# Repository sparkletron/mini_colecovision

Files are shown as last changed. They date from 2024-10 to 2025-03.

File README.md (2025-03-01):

# Mini Colecovision Project with Super Game Module Support
### Schematic, PCB, and CPLD design.



---

  author: Jay Convertino

  date: 2024.03.24

  details: A Super Game Module Compatible Colecovision that is much smaller than the original, and only uses +5v.

  license: MIT

---

## LICENSE
  - All files related to or generated from the KiCAD source fall under the MIT license.
  - All files related to or generated from the Verilog source fall under the MIT license.
  - All files generated by me, Jay Convertino, fall under the MIT license.
  - All files from other sources fall under the license of their specification.

## RELEASE VERSIONS
### Current
  - 1.0.1 - Fixed opcode games AY check for super game module.

### Past
  - 1.0.0 - First working version
  - DEV

### MISC
  - std_v1 - A branch that contains the first version with standard colecovision compatibility only.

## Intro
  This is a miniturization of the original colecovision. All logic is simplified to a single CPLD.

## Documentation
  For detailed usage information, please navigate to one of the following sources. They are the same, just in a different format.
  - [mini_colecovision.pdf](docs/manual/mini_colecovision.pdf)
  - [github page](https://sparkletron.github.io/mini_colecovision/)

## SOURCES
### Schematic Check
  - Righteous Tentacle Colecovision : https://github.com/sparkletron/righteous_tentacle_colecovision : Jay Convertino

## SOFTWARE REQUIREMENTS
  - KiCAD v7.X
  - Quartus v13.0.1sp1 web edition
  - Altera USB Blaster

## BUILD TIPS
  This design is made so anyone can build this. Though it will need a board from a PCB manufacture due to the small pitch and
  vias. There are only a few SMD devices, the CPU, a cap, and a few resistors. These are larger to help make soldering easier.

  Recommend populating the SMD parts first, then moving on to the through hole parts from passive to active. If you do not plan
  on using a battery pack the shotkey diodes can be omitted.

  This is a 4 layer board, power and ground planes are run on the two internal planes.

  All case parts are ABS Plastic.

## Completed Project Image

coleco|300

## PCB IMAGE

pcb_3D_img_front|300

pcb_3D_img_back|300

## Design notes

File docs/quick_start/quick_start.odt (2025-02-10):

Mini Colecovision Compatible Portable Console with Super Game Module Compatibility.

QUICK START GUIDE

Console Startup:

1. Insert Cartridge into the console (figure 3) while powered off.
2. Power on console using the power switch (figure 3). Power LED will illuminate.
3. Enjoy the game.

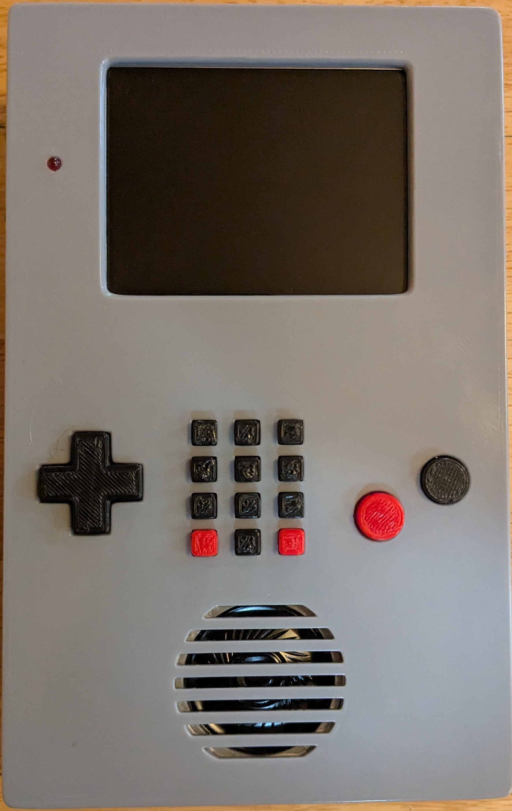
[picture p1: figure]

Figure 1: FRONT

The front of the console (figure 1) has the 3.5 inch LCD screen, power LED, first player controller, and speaker.

When powered the LED will illuminate. The LCD screen will display graphics.

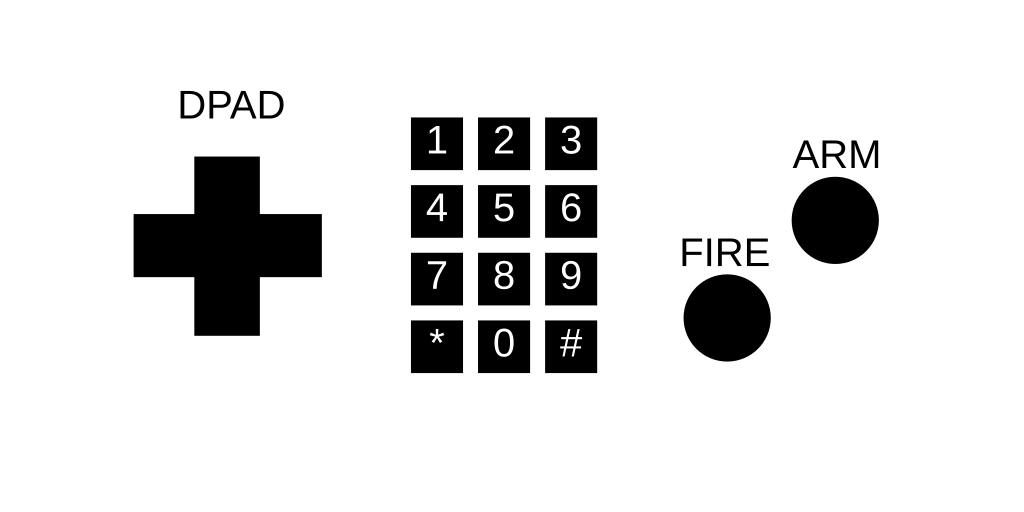
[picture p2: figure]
Controller

Figure 2: CONTROLLER

Figure 2 is the first player controller layout. This is similar to the original controller.

Headphone jack, power switch, and cartridge port are located on the top of the console (figure 3).

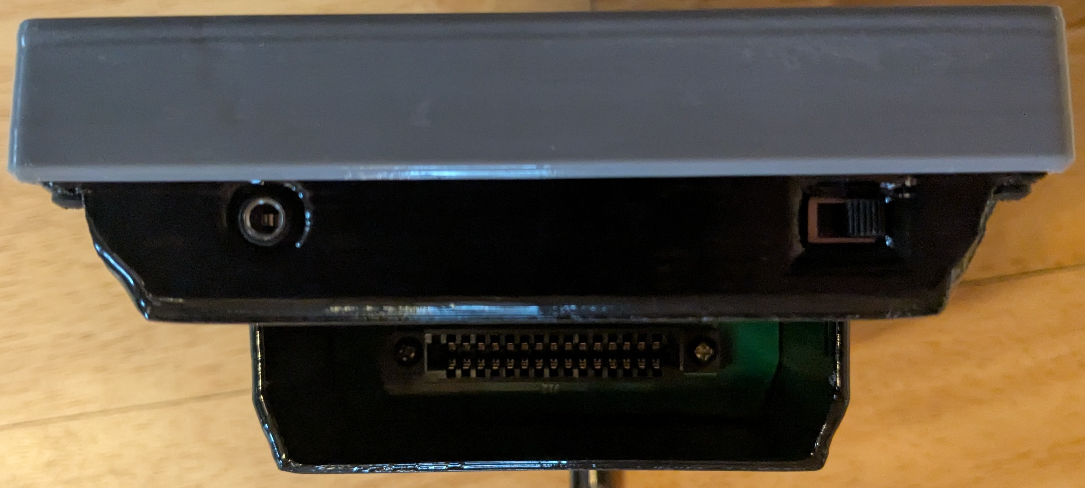
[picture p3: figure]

Figure 3: TOP

The headphone jack, circular port to the left, is a stereo 1/8th inch jack. When headphones are plugged in the speaker will have no sound output

On the right side, is a power switch for turning the console on and off.

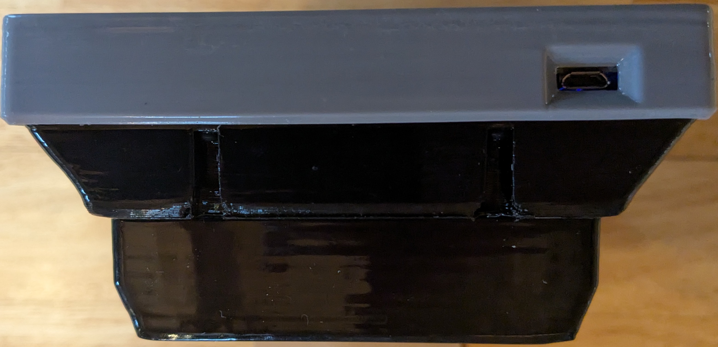
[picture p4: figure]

Figure 4: BOTTOM

To charge the console, use the power connector on the bottom (figure 4). It is a mini-USB connector that uses a 5 volt 500 mA charger.

Console specific controls are located on the left side (figure 5). This includes a row of four round switches for adjusting the LCD screen. From left to right these are: Enter Menu/Select, Adjust Up, Adjust Down, Input Switch (useless, press if screen is black). The rest from left to right are a reset switch, controller select switch, and first player controller port.

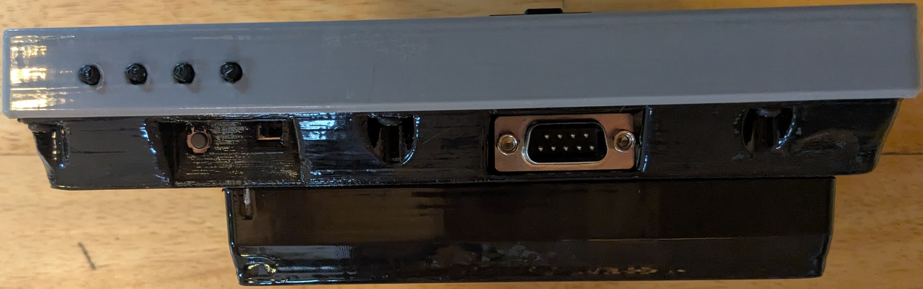
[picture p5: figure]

Figure 5: LEFT SIDE

From the top, left side of figure 5, the round gray switch is for resetting the console. Next is the toggle switch for selecting the controller to use. When it is positioned towards the reset switch, it will use the internal controllers only. When positioned towards the controller port it will use the external controller ports only. Last is the left side controller port that is for the first player controller when the controller toggle switch is set to the external position.

The right side (figure 6) has few controls. The volume control thumb wheel, and second player controller port are located on this side. The volume control, at the top right, adjusts the sound level for the speaker and the headphones Second player controller port, at the bottom left, is only active when the controller toggle switch is set to external.

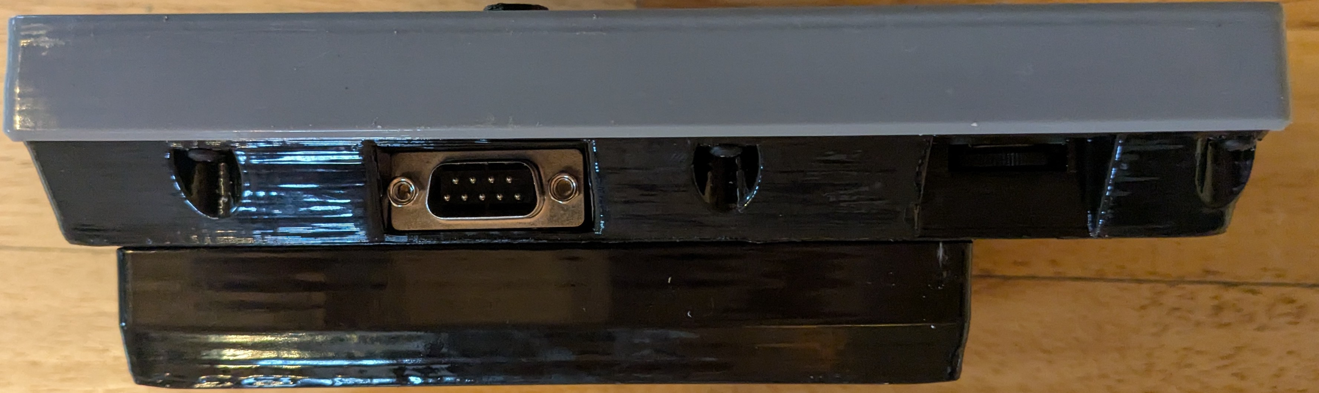
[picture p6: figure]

Figure 6: RIGHT SIDE

SPECIFICATIONS:

- z80 CPU @ 3.56 MHz
- 32 KiB of RAM
- 8 KiB of ROM
- MAX7128 CPLD
- TMS9118 VDP
- SN76489 Sound Chip
- YMZ284 Sound Chip
- TPA711D Amplifier
- 3.5 inch LCD screen
- Colecovision Compatible
- Super Game Module Compatible

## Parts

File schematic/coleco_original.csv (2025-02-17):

Item | Qty | Reference(s) | Value | LibPart | Footprint | Datasheet | DNP | Arrow Part Number | Arrow Price/Stock | Height | Manufacturer_Name | Manufacturer_Part_Number | Mouser Part Number | Mouser Price/Stock | Placement
1 | 14 | C1, C7, C8, C10, C11, C12, C13, C14, C18, C19, C23, C25, C29, C36 | 100nF | Device:C | Capacitor_THT:C_Disc_D7.0mm_W2.5mm_P5.00mm | ~
2 | 1 | C2 | 330uF | Device:CP | Capacitor_THT:CP_Radial_D8.0mm_P5.00mm
3 | 4 | C3, C5, C24, C30 | 10uF | Device:CP | Capacitor_THT:CP_Radial_D5.0mm_P2.50mm
4 | 1 | C4 | 100pF | Device:C | Capacitor_THT:C_Disc_D4.7mm_W2.5mm_P5.00mm | ~
5 | 1 | C6 | 270pF | Device:C | Capacitor_THT:C_Disc_D4.7mm_W2.5mm_P5.00mm | ~
6 | 8 | C9, C17, C22, C31, C32, C33, C34, C35 | 100nF | Device:C | Capacitor_SMD:C_1206_3216Metric | ~
7 | 2 | C15, C16 | 33pF | Device:C | Capacitor_THT:C_Disc_D3.0mm_W1.6mm_P2.50mm | ~
8 | 2 | C20, C21 | 10nF | Device:C | Capacitor_THT:C_Disc_D7.0mm_W2.5mm_P5.00mm | ~
9 | 1 | C26 | 0.47uF | Device:C_Polarized | Capacitor_THT:CP_Radial_D5.0mm_P2.00mm | ~
10 | 1 | C27 | 0.1uF | Device:C_Polarized | Capacitor_THT:CP_Radial_D5.0mm_P2.00mm | ~
11 | 1 | C28 | 2.2uF | Device:C_Polarized | Capacitor_THT:CP_Radial_D5.0mm_P2.00mm | ~
12 | 1 | D1 | LED | Device:LED | LED_THT:LED_D3.0mm | ~
13 | 5 | H1, H2, H4, H6, H7 | MountingHole_Pad | Mechanical:MountingHole_Pad | MountingHole:MountingHole_3.2mm_M3_DIN965_Pad | ~
14 | 1 | J1 | Conn_01x07 | Connector_Generic:Conn_01x07 | Connector_PinHeader_2.54mm:PinHeader_1x07_P2.54mm_Vertical | ~
15 | 3 | J2, J10, J11 | Conn_01x02 | Connector_Generic:Conn_01x02 | Connector_Molex:Molex_KK-254_AE-6410-02A_1x02_P2.54mm_Vertical | ~
16 | 1 | J3 | Conn_Coaxial | Connector:Conn_Coaxial | Connector_Molex:Molex_KK-254_AE-6410-02A_1x02_P2.54mm_Vertical | ~
17 | 1 | J4 | Cartridge Port | Connector_Generic:Conn_02x15_Odd_Even | TE_5530841-2:55308412_coleco | ~
18 | 1 | J5 | Player 1 | Connector:DB9_Male | Connector_Dsub:DSUB-9_Male_Horizontal_P2.77x2.84mm_EdgePinOffset7.70mm_Housed_MountingHolesOffset9.12mm | ~
19 | 1 | J6 | Conn_02x05_Odd_Even | Connector_Generic:Conn_02x05_Odd_Even | Connector_PinHeader_2.54mm:PinHeader_2x05_P2.54mm_Vertical | ~
20 | 1 | J7 | Player 2 | Connector:DB9_Male | Connector_Dsub:DSUB-9_Male_Horizontal_P2.77x2.84mm_EdgePinOffset7.70mm_Housed_MountingHolesOffset9.12mm | ~
21 | 1 | J9 | SJ1-3525NG | SJ-63053A:SJ1-3525NG | jacks2:SJ1-3525NG_CUD | SJ1-3525NG
22 | 3 | L1, L2, L3 | 4.7uH | Device:L | Inductor_THT:L_Axial_L7.0mm_D3.3mm_P10.16mm_Horizontal_Fastron_MICC | ~
23 | 1 | Q1 | 2N3904 | Transistor_BJT:2N3904 | Package_TO_SOT_THT:TO-92_Wide | https://www.onsemi.com/pub/Collateral/2N3903-D.PDF |  |  |  |  |  |  |  |  | Do Not Place if your end up with ghosting.
24 | 1 | R1 | 4k7 | Device:R | Resistor_THT:R_Axial_DIN0207_L6.3mm_D2.5mm_P10.16mm_Horizontal | ~
25 | 1 | R2 | 470R | Device:R | Resistor_THT:R_Axial_DIN0207_L6.3mm_D2.5mm_P10.16mm_Horizontal | ~
26 | 2 | R3, R28 | 100k | Device:R | Resistor_THT:R_Axial_DIN0207_L6.3mm_D2.5mm_P10.16mm_Horizontal | ~
27 | 2 | R4, R27 | 100K | Device:R | Resistor_THT:R_Axial_DIN0207_L6.3mm_D2.5mm_P7.62mm_Horizontal | ~
28 | 2 | R5, R6 | 2k2 | Device:R | Resistor_THT:R_Axial_DIN0207_L6.3mm_D2.5mm_P7.62mm_Horizontal | ~
29 | 3 | R7, R8, R9 | 3K3 | Device:R | Resistor_SMD:R_0805_2012Metric | ~
30 | 1 | R10 | 75R | Device:R | Resistor_THT:R_Axial_DIN0207_L6.3mm_D2.5mm_P7.62mm_Horizontal | ~ |  |  |  |  |  |  |  |  | Do Not Place if you get ghosting
31 | 1 | R11 | 510R | Device:R | Resistor_THT:R_Axial_DIN0207_L6.3mm_D2.5mm_P7.62mm_Horizontal | ~
32 | 1 | R12 | 100R | Device:R | Resistor_THT:R_Axial_DIN0207_L6.3mm_D2.5mm_P7.62mm_Horizontal | ~
33 | 1 | R13 | 3k3 | Device:R | Resistor_SMD:R_0805_2012Metric | ~
34 | 4 | R14, R15, R16, R17 | 1k | Device:R | Resistor_THT:R_Axial_DIN0207_L6.3mm_D2.5mm_P10.16mm_Horizontal | ~
35 | 2 | R18, R19 | 10k | Device:R | Resistor_THT:R_Axial_DIN0207_L6.3mm_D2.5mm_P10.16mm_Horizontal | ~
36 | 1 | R20 | 1K | Device:R | Resistor_SMD:R_0805_2012Metric | ~
37 | 1 | R21 | 1k | Device:R | Resistor_SMD:R_0805_2012Metric | ~
38 | 1 | R22 | 220R | Device:R | Resistor_THT:R_Axial_DIN0207_L6.3mm_D2.5mm_P10.16mm_Horizontal | ~
39 | 1 | R23 | 10K | Device:R | Resistor_THT:R_Axial_DIN0207_L6.3mm_D2.5mm_P7.62mm_Horizontal | ~
40 | 2 | R24, R26 | 1K | Device:R | Resistor_THT:R_Axial_DIN0207_L6.3mm_D2.5mm_P7.62mm_Horizontal | ~
41 | 1 | R25 | 68K | Device:R | Resistor_THT:R_Axial_DIN0207_L6.3mm_D2.5mm_P7.62mm_Horizontal | ~
42 | 2 | R29, R30 | 2R | Device:R | Resistor_THT:R_Axial_DIN0207_L6.3mm_D2.5mm_P7.62mm_Horizontal | ~
43 | 2 | RN1, RN2 | 10k | Device:R_Network06 | Resistor_THT:R_Array_SIP7 | http://www.vishay.com/docs/31509/csc.pdf
44 | 1 | RV1 | 10K | Device:R_Potentiometer | RV100F-30:RV100F304K1B50K | ~
45 | 1 | S1 | sparkletron | logos:sparkletron | logos:sparkletron
46 | 1 | SW1 | SW_Push | Switch:SW_Push | Button_Switch_THT:SW_Tactile_SKHH_Angled | ~
47 | 1 | SW2 | SW_SPDT | Switch:SW_SPDT | 1101M2S3ABE2:1101M2S3ABE2 | ~
48 | 1 | SW3 | SW_SPDT | Switch:SW_SPDT | Switches_THT:SW_CuK_OS102011MA1QN1_SPDT_Angled | ~
49 | 1 | U1 | TPA711D | TPA711D:TPA711D | TPA:SOIC127P600X175-8N | http://uk.rs-online.com/web/p/products/6606310 |  | TPA711D | https://www.arrow.com/en/products/tpa711d/texas-instruments | 1.75 | Texas Instruments | TPA711D | 595-TPA711D | https://www.mouser.co.uk/ProductDetail/Texas-Instruments/TPA711D?qs=N6WZOzgtpqXZp9VA2XuuWQ%3D%3D
50 | 1 | U2 | SN76489AN | Vintage_Audio_Synth:SN76489AN | Package_DIP:DIP-16_W7.62mm
51 | 1 | U3 | Z84C0010AEG | CPU_EXT:Z84C0010AEG | Package_QFP:LQFP-44_10x10mm_P0.8mm | http://www.mouser.com/datasheet/2/450/ps0178-19386.pdf |  | Z84C0010AEG | https://www.arrow.com/en/products/z84c0010aeg/ixys?region=nac | 1.6 | LITTELFUSE | Z84C0010AEG | 692-Z84C0010AEG | https://www.mouser.co.uk/ProductDetail/ZiLOG/Z84C0010AEG?qs=87AjWkFq0r4vnAaeK2Di%2FA%3D%3D
52 | 1 | U4 | CY62256-55PC | Memory_RAM:CY62256-70PC | Package_DIP:DIP-28_W15.24mm | https://ecee.colorado.edu/~mcclurel/Cypress_SRAM_CY62256.pdf
53 | 1 | U5 | 27C256 | Memory_EPROM:27C256 | Package_DIP:DIP-28_W15.24mm | http://ww1.microchip.com/downloads/en/DeviceDoc/doc0014.pdf
54 | 1 | U6 | TMS9118NL | Vintage_VDP:TMS9118NL | Package_DIP:DIP-40_W15.24mm
55 | 2 | U7, U8 | TMS4416 | Vintage_RAM:TMS4416 | Package_DIP:DIP-18_W7.62mm
56 | 1 | U9 | EPM7128SLC | CPLD:MAX7000_84_PLCC | Package_LCC:PLCC-84_THT-Socket
57 | 1 | U10 | 74ABT125 | 74xx:74LS125 | Package_SO:SOIC-14_3.9x8.7mm_P1.27mm | http://www.ti.com/lit/gpn/sn74LS125
58 | 1 | U11 | YMZ284 | Vintage_Audio_Synth:YMZ284 | Package_DIP:DIP-16_W7.62mm
59 | 5 | U12, U13, U14, U15, U16 | 74AHCT1G08 | 74xGxx:74AHCT1G08 | Package_TO_SOT_SMD:SOT-23-5_HandSoldering | http://www.ti.com/lit/sg/scyt129e/scyt129e.pdf
60 | 1 | Y1 | 10.738635 MHz | Device:Crystal | Crystal:Crystal_HC49-4H_Vertical | ~

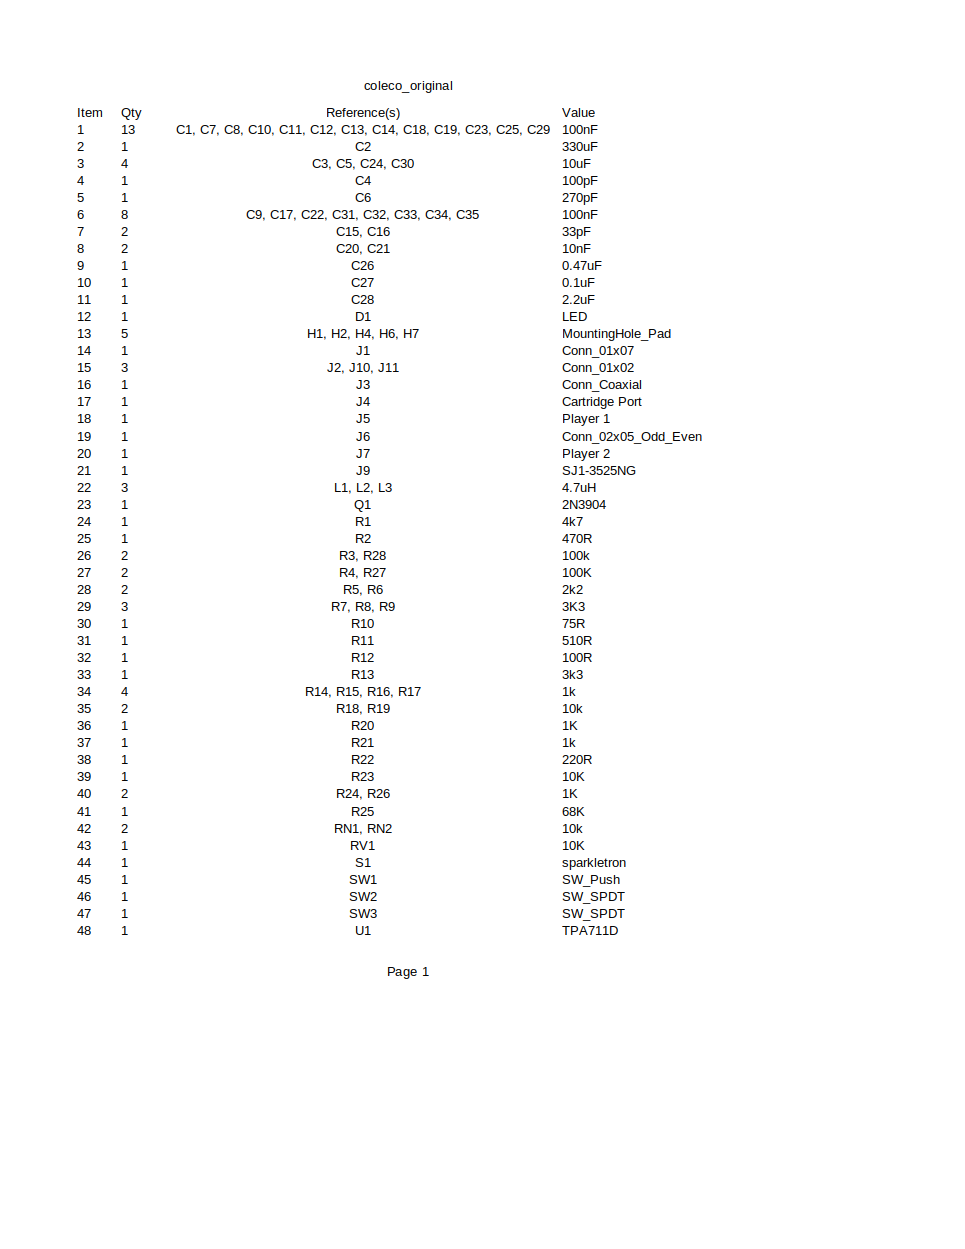
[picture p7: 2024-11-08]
docs/manual/img/coleco_bom.png

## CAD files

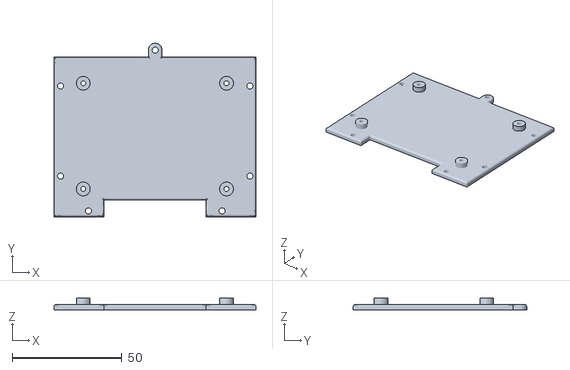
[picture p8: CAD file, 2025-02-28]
models/case/lcd_hold_mount.stl
92.2 x 79.2 x 5.33

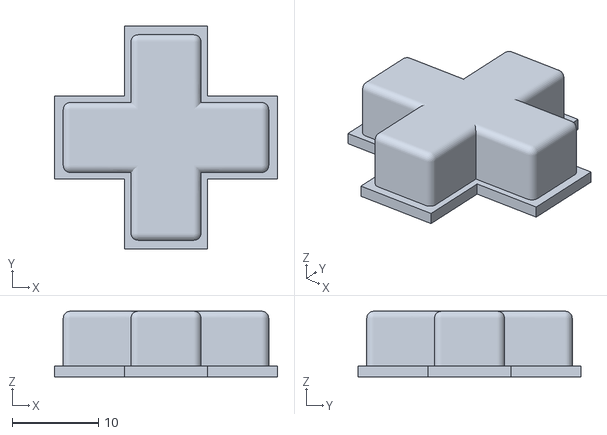
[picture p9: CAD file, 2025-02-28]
models/case/dpad_large.stl
25.9 x 25.9 x 7.62

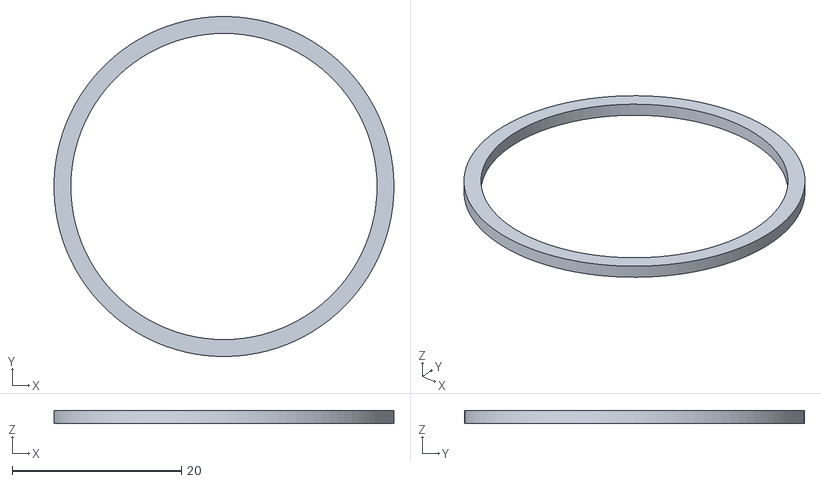
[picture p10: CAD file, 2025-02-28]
models/case/speaker_spacer.stl
40.1 x 40.1 x 1.50

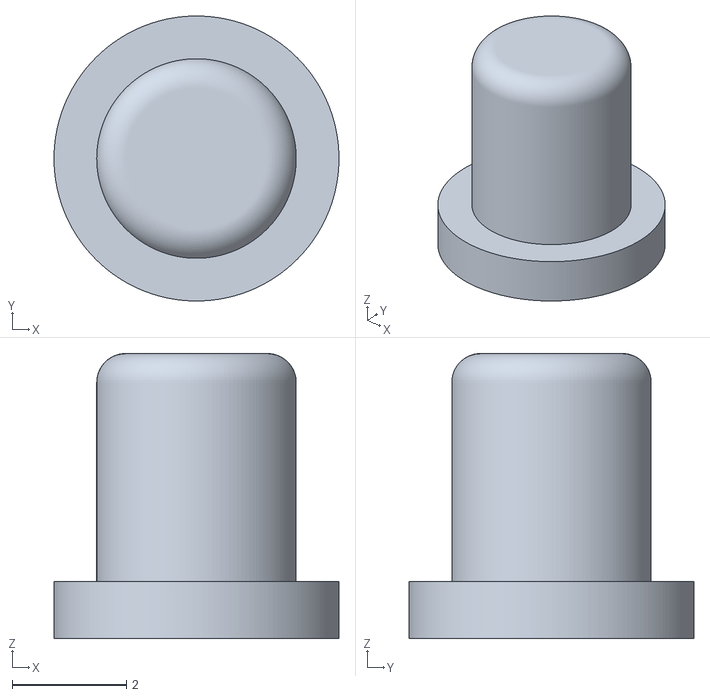
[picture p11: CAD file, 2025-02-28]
models/case/button.stl
5.00 x 5.00 x 5.00

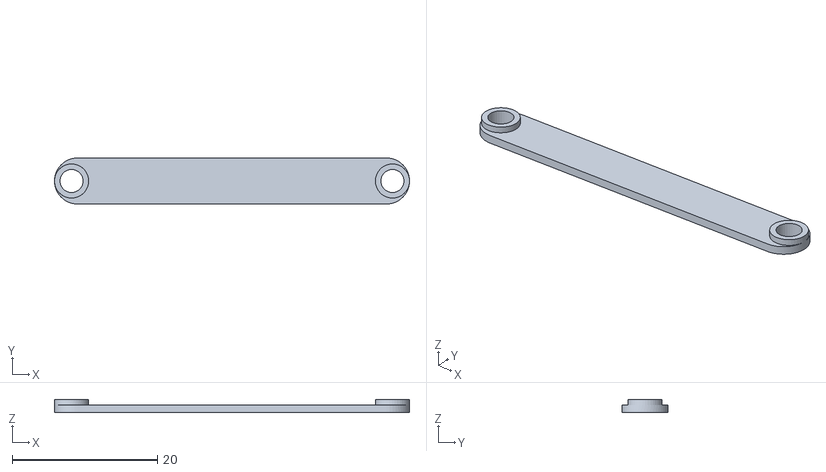
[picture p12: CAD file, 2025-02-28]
models/case/speaker_mount.stl
48.9 x 6.35 x 1.85

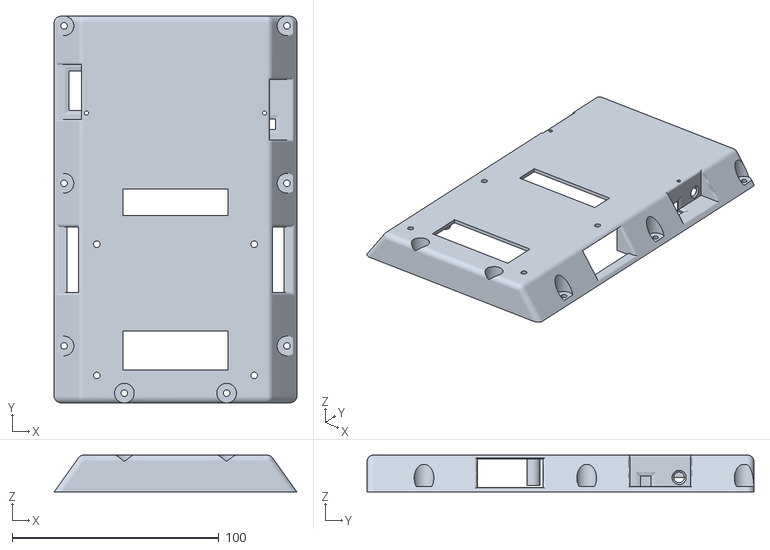
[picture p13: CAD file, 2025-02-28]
models/case/back.stl
117.5 x 187.3 x 17.8

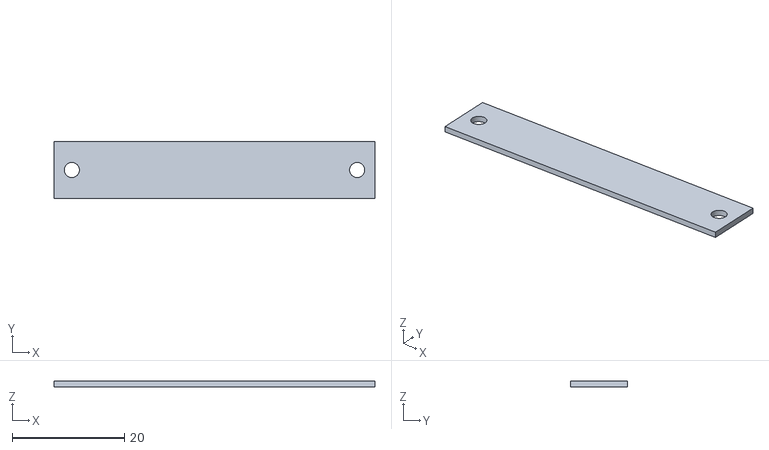
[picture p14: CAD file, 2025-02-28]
models/case/serial_strip.stl
57.2 x 10.2 x 1.02

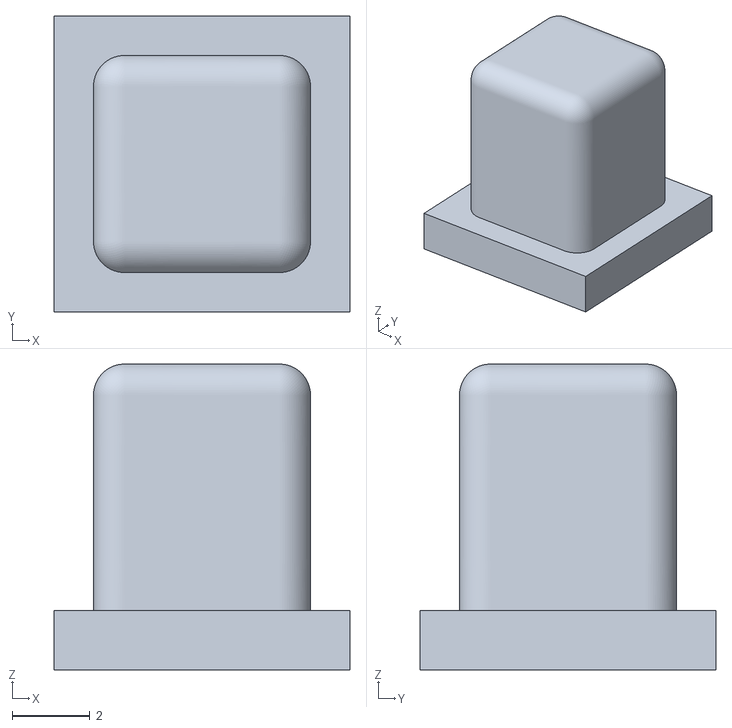
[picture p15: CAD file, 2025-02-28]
models/case/numpad.stl
7.62 x 7.62 x 7.87

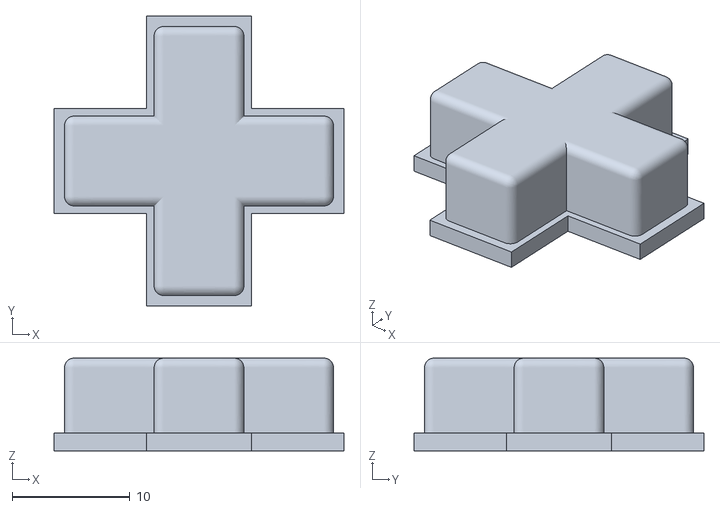
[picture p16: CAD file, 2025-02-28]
models/case/dpad.stl
24.6 x 24.6 x 7.87

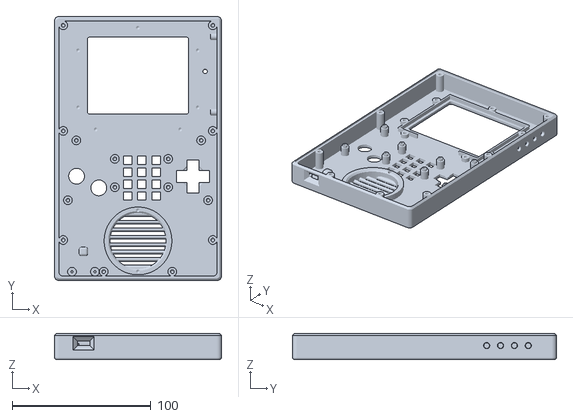
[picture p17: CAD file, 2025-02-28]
models/case/front.stl
120.7 x 190.5 x 19.0

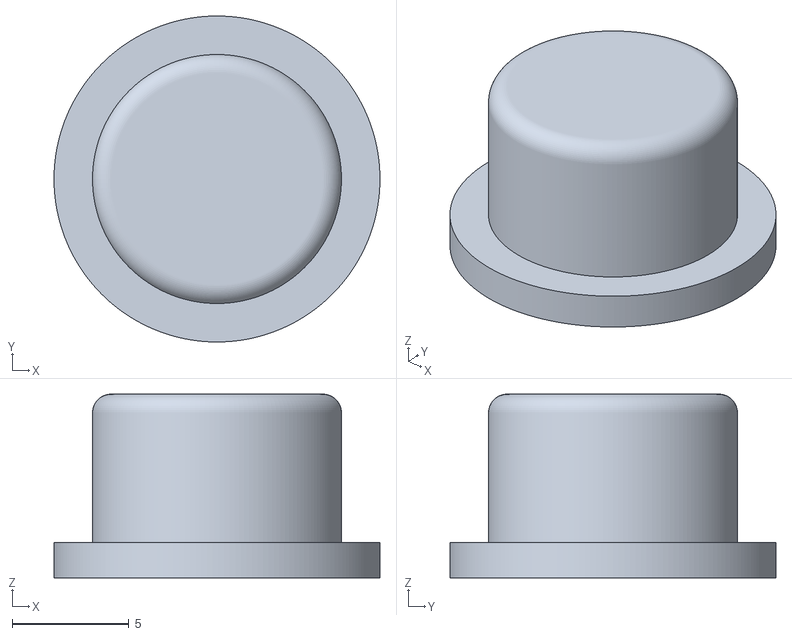
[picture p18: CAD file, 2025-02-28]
models/case/firebutton.stl
14.0 x 14.0 x 7.87

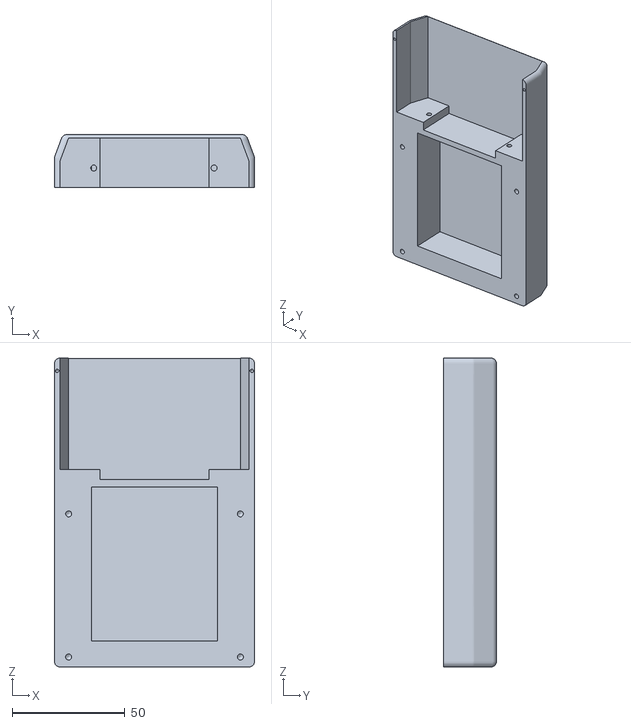
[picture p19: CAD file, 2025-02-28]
models/case/cart_back.stl
88.9 x 23.5 x 137.2

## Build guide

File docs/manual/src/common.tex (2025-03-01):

\begin{titlepage}
  \begin{center}

  {\Huge Mini Colecovision Compatible Portable}

  \vspace{25mm}

  

  \vspace{25mm}

  \today

  \vspace{15mm}

  {\Large Jay Convertino}

  \end{center}
\end{titlepage}

\tableofcontents

\newpage

\section{Introduction}

\par
Mini Colecovision Compatible Portable is a portable console version of the original Colecovision. Much of the TTL and Analog Monostable circuits
are emulated by a CPLD. The full PCB and CPLD code is in this repository. It emulates the original Colecovision
with the additional super game module. No 3D printed case is included at the moment, but has been designed and tested. This
manual is not at step by step document of how to build the unit, more of a highlight of aspects of the project.

\subsection{Fix for opcode games}

Opcode super game module mega cart games have a particular check for the sound chip in there startup routine.

\begin{enumerate}
  \item Set AY register address to 0x00
  \item Write the value 0xAA to AY (register 0x00).
  \item Set AY register address to 0x02
  \item Write the value 0x55 to AY (register 0x02).
  \item Set AY register address to 0x00
  \item Read the value from AY (register 0x00).
  \item Compare to value originally written (0xAA), fail if not matching
  \item Set AY register address to 0x02
  \item Read the value from AY (register 0x02).
  \item Compare to value originally written (0x55), fail if not matching.
\end{enumerate}

The hack fix for my setup is to only have 4 8 bit regiters for 0,1,2,3,4,5,6, and 7. The mapping is
AY Software Register ADDRESS => Cache Register ADDRESS

\begin{itemize}
  \item 0 => 0
  \item 1 => 0
  \item 2 => 1
  \item 3 => 1
  \item 4 => 2
  \item 5 => 2
  \item 6 => 3
  \item 7 => 3
\end{itemize}

\subsection{Specifications}

\par
\begin{itemize}
  \item Z80 CPU
  \item 32 KiB of RAM
  \item 32 KiB of ROM
  \item SN76489 Sound Chip
  \item YMZ284 Sound Chip
  \item TMS9118 Video Display Processor with 16 KiB of VRAM
  \item MAX7000S CPLD (EPM7128SLC)
  \item Main PCB, four layer
  \item Right Angle PCB, two layer
\end{itemize}

\subsection{Parts List}

\subsubsection{main pcb}
\begin{footnotesize}
\begin{longtable}{ |*{4}{c|} }
\hline
{Item} & {Qty} & {Reference(s)} & {Value} \\
\hline
{1} & {13} & {C1, C7, C8, C10 to C14, C18, C19, C23, C25, C29} & {100nF} \\
\hline
{2} & {1} & {C2} & {330uF} \\
\hline
{3} & {4} & {C3, C5, C24, C30} & {10uF} \\
\hline
{4} & {1} & {C4} & {100pF} \\
\hline
{5} & {1} & {C6} & {270pF} \\
\hline
{6} & {8} & {C9, C17, C22, C31 to C35} & {100nF} \\
\hline
{7} & {2} & {C15, C16} & {33pF} \\
\hline
{8} & {2} & {C20, C21} & {10nF} \\
\hline
{9} & {1} & {C26} & {0.47uF} \\
\hline
{10} & {1} & {C27} & {0.1uF} \\
\hline
{11} & {1} & {C28} & {2.2uF} \\
\hline
{12} & {1} & {D1} & {LED} \\
\hline
{14} & {1} & {J1} & {Conn\_01x07} \\
\hline
{15} & {3} & {J2, J10, J11} & {Conn\_01x02} \\
\hline
{16} & {1} & {J3} & {Conn\_Coaxial} \\
\hline
{17} & {1} & {J4} & {Cartridge Port} \\
\hline
{18} & {1} & {J5} & {DB9 Male} \\
\hline
{19} & {1} & {J6} & {Conn\_02x05\_Odd\_Even} \\
\hline
{20} & {1} & {J7} & {DB9 Male} \\
\hline
{21} & {1} & {J9} & {SJ1-3525NG} \\
\hline
{22} & {3} & {L1, L2, L3} & {4.7uH} \\
\hline
{23} & {1} & {Q1} & {2N3904} \\
\hline
{24} & {1} & {R1} & {4k7} \\
\hline
{25} & {1} & {R2} & {470R} \\
\hline
{26} & {2} & {R3, R28} & {100k} \\
\hline
{27} & {2} & {R4, R27} & {100K} \\
\hline
{28} & {2} & {R5, R6} & {2k2} \\
\hline
{29} & {3} & {R7, R8, R9} & {3K3} \\
\hline
{30} & {1} & {R10} & {75R} \\
\hline
{31} & {1} & {R11} & {510R} \\
\hline
{32} & {1} & {R12} & {100R} \\
\hline
{33} & {1} & {R13} & {3k3} \\
\hline
{34} & {4} & {R14, R15, R16, R17} & {1k} \\
\hline
{35} & {2} & {R18, R19} & {10k} \\
\hline
{36} & {1} & {R20} & {1K} \\
\hline
{37} & {1} & {R21} & {1k} \\
\hline
{38} & {1} & {R22} & {220R} \\
\hline
{39} & {1} & {R23} & {10K} \\
\hline
{40} & {2} & {R24, R26} & {1K} \\
\hline
{41} & {1} & {R25} & {68K} \\
\hline
{42} & {2} & {RN1, RN2} & {10k} \\
\hline
{43} & {1} & {RV1} & {10K} \\
\hline
{45} & {1} & {SW1} & {SW\_Push} \\
\hline
{46} & {1} & {SW2} & {SW\_SPDT} \\
\hline
{47} & {1} & {SW3} & {SW\_SPDT} \\
\hline
{48} & {1} & {U1} & {TPA711D} \\
\hline
{49} & {1} & {U2} & {SN76489AN} \\
\hline
{50} & {1} & {U3} & {Z84C0010AEG} \\
\hline
{51} & {1} & {U4} & {CY62256-55PC} \\
\hline
{52} & {1} & {U5} & {27C256} \\
\hline
{53} & {1} & {U6} & {TMS9118NL} \\
\hline
{54} & {2} & {U7, U8} & {TMS4416} \\
\hline
{55} & {1} & {U9} & {EPM7128SLC} \\
\hline
{56} & {1} & {U10} & {74ABT125} \\
\hline
{57} & {1} & {U11} & {YMZ284} \\
\hline
{58} & {5} & {U12, U13, U14, U15, U16} & {74AHCT1G08} \\
\hline
{59} & {1} & {Y1} & {10.738635 MHz} \\
\hline
\end{longtable}
\end{footnotesize}

\subsubsection{right angle adaptor}
\begin{footnotesize}
\begin{longtable}{ |*{4}{c|} }
\hline
{Item} & {Qty} & {Reference(s)} & {Value} \\
\hline
{1} & {1} & {J} & {Cartridge Port} \\
\hline
\end{longtable}
\end{footnotesize}

\subsubsection{misc electronics}
\begin{footnotesize}
\begin{longtable}{ |*{4}{c|} }
\hline
{Item} & {Qty} & {Reference(s)} & {Value} \\
\hline
{1} & {1} & {C1} & {Colecovision Controller, github.com/sparkletron/Colecovision\_Controller} \\
\hline
{2} & {1} & {LS1} & {LCD, LQ035NC111} \\
\hline
{3} & {1} & {LC1} & {LCD Controller, VS\-D1612\-N3 type with SS0101 controller chip or BIT1612} \\
\hline
{4} & {1} & {Battery} & {3 Cell 10050 mAh Adafruit 5035} \\
\hline
{5} & {1} & {Battery Charger} & {500 mA charger Adafruit 1944} \\
\hline
{6} & {1} & {Speaker} & {CMS\-4049\-28S} \\
\hline
\end{longtable}
\end{footnotesize}

\subsubsection{hardware}
\begin{footnotesize}
\begin{longtable}{ |*{4}{c|} }
\hline
{Item} & {Qty} & {Reference(s)} & {Value} \\
\hline
{1} & {22} & {S1} & {\#4-24 x 1/4 Fastenal 0142972, screw} \\
\hline
{2} & {9} & {S2} & {\#4-24 x 1/2 Fastenal 0173613, screw} \\
\hline
{3} & {4} & {S3} & {\#2-32 x 1/4 Fastenal 0148209, screw} \\
\hline
{4} & {8} & {S4} & {\#4-24 x 1/2 Fastenal 0149046, screw black} \\
\hline
\end{longtable}
\end{footnotesize}

\subsubsection{3D printed hardware}
\begin{footnotesize}
\begin{longtable}{ |*{4}{c|} }
\hline
{Item} & {Qty} & {Reference(s)} & {Value} \\
\hline
{1} & {1} & {P1} & {back.stl 100.5} \\
\hline
{2} & {4} & {P2} & {button.stl 100} \\
\hline
{3} & {1} & {P3} & {cart\_back.stl 100.5} \\
\hline
{4} & {1} & {P4} & {dpad\_large.stl 100} \\
\hline
{5} & {2} & {P5} & {firebutton.stl 100} \\
\hline
{6} & {1} & {P6} & {front.stl 100.5} \\
\hline
{7} & {1} & {P7} & {lcd\_hold\_mount.stl 100.5} \\
\hline
{8} & {12} & {P8} & {numpad.stl 100} \\
\hline
{9} & {4} & {P9} & {serial\_strip.stl 100} \\
\hline
{10} & {1} & {P10} & {speaker\_mount.stl 100.5} \\
\hline
{11} & {1} & {P11} & {speaker\_spacer.stl 100} \\
\hline
\end{longtable}
\end{footnotesize}

\section{Building}

\par
This document assumes some Electrical Engineering knowledge. Building circuits is not
trivial due to the mix of SMD and through hole components. What follow are general
steps to build the Mini Colecovision

\begin{itemize}
  \item Create main PCB from schematic/gerber/coleco\_original.zip
  \item Create Right Angle PCB from schematic/gerber/right\_angle/right\_angle.zip
  \item Program ROM with BIOS
  \item Populate main PCB
  \item Populate right angle PCB
  \item Power up and program CPLD
  \item Build your own case
\end{itemize}

\subsection{Dependencies}

\par
The following are the dependencies needed to build the firmware and PCB for the system.

\begin{itemize}
  \item Quartus 13.0 sp1
  \item python 3.X
  \item KiCAD v7.X
\end{itemize}

\input{src/fusesoc/files_fusesoc.tex}

\subsubsection{Fusesoc}
\par
Fusesoc is used for the simulation target only. There are no build targets due to the use of Quartus 13.0sp1.
This makes the use of it a bit silly. It does make it easier to use in future projects where the RAM,ROM,CPU,VDP,
and Sound chips are also IP cores.

\input{src/fusesoc/targets_fusesoc.tex}

\subsubsection{Quartus}
\par
This project uses the last version of Quartus that supports the MAX7000S series. The version is 13.0sp1.
The project is located at src/quartus13sp01/. Once you have the project open please follow the softwares steps
for building and programming the CPLD bitfile.

\subsection{PCB}

\par
The four layer PCB is fairly easy to populate. The right angle PCB is a dual layer PCB which is even easier.
I recommend starting with resistors, then IC's, and then the rest. Surface mount parts should be done last.
This is a fairly complex project to build, take great caution in making sure your CPU and CPLD are installed
correctly. Its easy to rotate square packages these come in.

\subsection{3D Printed Case}

\par
The 3D printed case has been tested on two different printers. It has only been tested with ABS filament.
The parts list for the 3D printed case has the STL file name in the value and the XXX.X value is the scale size.
In general I recommend the following steps for assembly.

\begin{enumerate}
  \item Front, populate side controls w/buttons. PCB will need to be cut down to fit height wise.
  \item Front, populate LCD screen.
  \item Front, Insert Power LED
  \item Front, Route LCD screen wires under gamepad. Glue LED wires to side of case to keep out of DPAD.
  \item Front, Mount colecovision\_controller with buttons.
  \item Front, Insert speaker with spacer.
  \item Front, Glue or use speaker\_mount to hold speaker.
  \item Front, Mount USB battery charger.
  \item Cart\_back, insert battery, check for wire crimping.
  \item Cart\_back, mount right angle adaptor.
  \item Back, mount cart\_back to back.
  \item Back, run battery wire to charger
  \item Back, run wires from front to main PCB
  \item Back, hot glue any wires that seem like they may come off.
  \item Back, Mount PCB by inserting the top with the power switch first. Then press it in and watch the reset switch and cart port for binding.
  \item Back, Mount serial strips over PCB ports.
  \item Finish, mate the back to the front. It should fold together and not give much resistance.
\end{enumerate}

\subsection{Programming}

\par
There are two devices that need to be programmed. ROM (read only memory) and the CPLD (complex programmable logic device).
They use two different methods to be programmed. The ROM is done off the board and then installed. The CPLD is installed
and the JTAG header is used to upload the bitfile.

\subsubsection{ROM}

\par
A TL866 is an excellent device for programming the ROM with a BIOS. The open source minipro application works well with it and
its clones. Below is a example command to use to program the ROM with a bios.

  \begin{lstlisting}[language=bash]
$ minipro -p ST27C256 -w coleco_bios.bin
  \end{lstlisting}

\subsubsection{CPLD}

\par
Quartus 13.0sp1 is the easiest way to build and program the MAX7000 CPLD. You will need an altera blaster.
I recommend the chinese clone blasters, they actually worked the best. While the worst was the Terasic blaster
which did not work at all. As for instructions on how to program it in Quartus, please see the software for details.

\newpage

\section{Usage}

\subsection{Directory Guide}

\par
Below highlights important folders from the root of mini\_colecovision.

\begin{enumerate}
  \item \textbf{docs} Contains all documentation related to this project.
    \begin{itemize}
      \item \textbf{datasheets} Contains all datasheets for components.
      \item \textbf{manual} Contains user manual and github page that are generated from the latex sources.
    \end{itemize}
  \item \textbf{img} Contains images of the project
  \item \textbf{schematic} KiCAD v7.X schematic and PCB designs
    \begin{itemize}
      \item \textbf{gerber} Contains gerber files and archives for production.
      \item \textbf{pdf} PDF schematic
    \end{itemize}
  \item \textbf{src} CPLD firmware source
    \begin{itemize}
      \item \textbf{protable\_coleco} Contains verilog source code and constraits
      \item \textbf{quartus13sp01} Quartus project used to generate firmware.
    \end{itemize}
\end{enumerate}

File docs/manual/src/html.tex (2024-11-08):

\documentclass{article}
\usepackage{graphicx}
\usepackage{listings}
\usepackage{longtable}
\usepackage[hidelinks]{hyperref}
\begin{document}

  \include{src/common.tex}

  \section{Module Documentation}
  \par What follows are html links to the natural docs generated pages. This documents
  the source code used for the CPLD.

  \subsection{\href{../files/porta_glue_coleco-v.html}{porta\_glue\_coleco}}

  \section{Schematics}

  \subsection{\href{../../../schematic/coleco_original.pdf}{Coleco Mini}}

  \subsection{\href{../../../schematic/right_angle.pdf}{Right Angle}}

\end{document}

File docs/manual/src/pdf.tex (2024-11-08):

\documentclass[usletter]{article}
\usepackage{DejaVuSans}
\renewcommand*\familydefault{\sfdefault}
\usepackage[T1]{fontenc}
\usepackage{graphicx}
\usepackage{listings}
\usepackage{pdfpages}
\usepackage{multirow}
\usepackage{lscape}
\usepackage{graphics}
\usepackage{longtable}
\usepackage{graphics}
\usepackage{lscape}
\usepackage[hidelinks]{hyperref}
\begin{document}

  \include{src/common.tex}

  \section{Module Documentation}
  \par What follows are PDF pages generated from natural docs HTML pages. This documents
  the source code used for the CPLD.

  \includepdf[pages=-, addtotoc={1,subsection,1,porta\_glue\_coleco,p1}, pagecommand={}]{porta_glue_coleco-v.pdf}

  \section{Schematics}

  \includepdf[pages=-, addtotoc={1,subsection,1,Coleco Mini,p1}, pagecommand={}]{../../schematic/pdf/coleco_original.pdf}

  \includepdf[pages=-, addtotoc={1,subsection,1,Right Angle,p1}, pagecommand={}]{../../schematic/pdf/right_angle.pdf}

\end{document}

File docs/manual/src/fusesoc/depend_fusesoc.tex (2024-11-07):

\subsubsection{Protable Coleco Glue Depenecies}
\begin{itemize}
\end{itemize}

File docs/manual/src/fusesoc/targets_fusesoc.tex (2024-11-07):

\subsubsection{Protable Coleco Glue Targets}
\begin{itemize}
\item default
	\begin{itemize}
	\item[$\space$] Info: Default IP target for future tool intergration.
	\item src
	\item constr
	\end{itemize}
\item sim
	\begin{itemize}
	\item[$\space$] Info: Simulation target for basic test bench.
	\item src
	\item tb
	\end{itemize}
\end{itemize}

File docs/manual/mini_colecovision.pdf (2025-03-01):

# Mini Colecovision Compatible Portable

March 1, 2025

## Jay Convertino

## Contents

1 Introduction | 2
2 Building | 5
3 Usage | 9
4 Module Documentation | 10
5 Schematics | 31

1

## 1 Introduction

Mini Colecovision Compatible Portable is a portable console version of the original Colecovision. Much of the TTL and Analog Monostable circuits are emulated by a CPLD. The full PCB and CPLD code is in this repository. It emulates the original Colecovision with the additional super game module. No 3D printed case is included at the moment, but has been designed and tested. This manual is not at step by step document of how to build the unit, more of a highlight of aspects of the project.

## 1.1 Fix for opcode games

Opcode super game module mega cart games have a particular check for the sound chip in there startup routine.

1. Set AY register address to 0x00
2. Write the value 0xAA to AY (register 0x00).
3. Set AY register address to 0x02
4. Write the value 0x55 to AY (register 0x02).
5. Set AY register address to 0x00
6. Read the value from AY (register 0x00).
7. Compare to value originally written (0xAA), fail if not matching
8. Set AY register address to 0x02
9. Read the value from AY (register 0x02).
10. Compare to value originally written (0x55), fail if not matching.

The hack fix for my setup is to only have 4 8 bit regiters for 0,1,2,3,4,5,6, and 7. The mapping is AY Software Register ADDRESS => Cache Register ADDRESS

- 0 => 0
- 1 => 0
- 2 => 1
- 3 => 1
- 4 => 2
- 5 => 2
- 6 => 3
- 7 => 3

2

## 1.2 Specifications

- Z80 CPU
- 32 KiB of RAM
- 32 KiB of ROM
- SN76489 Sound Chip
- YMZ284 Sound Chip
- TMS9118 Video Display Processor with 16 KiB of VRAM
- MAX7000S CPLD (EPM7128SLC)
- Main PCB, four layer
- Right Angle PCB, two layer

## 1.3 Parts List

### 1.3.1 main pcb

Item | Qty | Reference(s) | Value
1 | 13 | C1, C7, C8, C10 to C14, C18, C19, C23, C25, C29 | 100nF
2 | 1 | C2 | 330uF
3 | 4 | C3, C5, C24, C30 | 10uF
4 | 1 | C4 | 100pF
5 | 1 | C6 | 270pF
6 | 8 | C9, C17, C22, C31 to C35 | 100nF
7 | 2 | C15, C16 | 33pF
8 | 2 | C20, C21 | 10nF
9 | 1 | C26 | 0.47uF
10 | 1 | C27 | 0.1uF
11 | 1 | C28 | 2.2uF
12 | 1 | D1 | LED
14 | 1 | J1 | Conn_01x07
15 | 3 | J2, J10, J11 | Conn_01x02
16 | 1 | J3 | Conn_Coaxial
17 | 1 | J4 | Cartridge Port
18 | 1 | J5 | DB9 Male
19 | 1 | J6 | Conn_02x05_Odd_Even
20 | 1 | J7 | DB9 Male
21 | 1 | J9 | SJ1-3525NG
22 | 3 | L1, L2, L3 | 4.7uH
23 | 1 | Q1 | 2N3904
24 | 1 | R1 | 4k7
25 | 1 | R2 | 470R
26 | 2 | R3, R28 | 100k
27 | 2 | R4, R27 | 100K
28 | 2 | R5, R6 | 2k2

3

29 | 3 | R7, R8, R9 | 3K3
30 | 1 | R10 | 75R
31 | 1 | R11 | 510R
32 | 1 | R12 | 100R
33 | 1 | R13 | 3k3
34 | 4 | R14, R15, R16, R17 | 1k
35 | 2 | R18, R19 | 10k
36 | 1 | R20 | 1K
37 | 1 | R21 | 1k
38 | 1 | R22 | 220R
39 | 1 | R23 | 10K
40 | 2 | R24, R26 | 1K
41 | 1 | R25 | 68K
42 | 2 | RN1, RN2 | 10k
43 | 1 | RV1 | 10K
45 | 1 | SW1 | SW_Push
46 | 1 | SW2 | SW_SPDT
47 | 1 | SW3 | SW_SPDT
48 | 1 | U1 | TPA711D
49 | 1 | U2 | SN76489AN
50 | 1 | U3 | Z84C0010AEG
51 | 1 | U4 | CY62256-55PC
52 | 1 | U5 | 27C256
53 | 1 | U6 | TMS9118NL
54 | 2 | U7, U8 | TMS4416
55 | 1 | U9 | EPM7128SLC
56 | 1 | U10 | 74ABT125
57 | 1 | U11 | YMZ284
58 | 5 | U12, U13, U14, U15, U16 | 74AHCT1G08
59 | 1 | Y1 | 10.738635 MHz

### 1.3.2 right angle adaptor

Item | Qty | Reference(s) | Value
1 | 1 | J | Cartridge Port

### 1.3.3 misc electronics

Item | Qty | Reference(s) | Value
1 | 1 | C1 | Colecovision Controller, github.com/sparkletron/Colecovision_Controller
2 | 1 | LS1 | LCD, LQ035NC111
3 | 1 | LC1 | LCD Controller, VSD1612N3 type with SS0101 controller chip or BIT1612
4 | 1 | Battery | 3 Cell 10050 mAh Adafruit 5035
5 | 1 | Battery Charger | 500 mA charger Adafruit 1944
6 | 1 | Speaker | CMS404928S

### 1.3.4 hardware

4

Item | Qty | Reference(s) | Value
1 | 22 | S1 | #4-24 x 1/4 Fastenal 0142972, screw
2 | 9 | S2 | #4-24 x 1/2 Fastenal 0173613, screw
3 | 4 | S3 | #2-32 x 1/4 Fastenal 0148209, screw
4 | 8 | S4 | #4-24 x 1/2 Fastenal 0149046, screw black

1.3.5 3D printed hardware

Item | Qty | Reference(s) | Value
1 | 1 | P1 | back.stl 100.5
2 | 4 | P2 | button.stl 100
3 | 1 | P3 | cart_back.stl 100.5
4 | 1 | P4 | dpad_large.stl 100
5 | 2 | P5 | firebutton.stl 100
6 | 1 | P6 | front.stl 100.5
7 | 1 | P7 | lcd_hold_mount.stl 100.5
8 | 12 | P8 | numpad.stl 100
9 | 4 | P9 | serial_strip.stl 100
10 | 1 | P10 | speaker_mount.stl 100.5
11 | 1 | P11 | speaker_spacer.stl 100

## 2 Building

This document assumes some Electrical Engineering knowledge. Building circuits is not trivial due to the mix of SMD and through hole components. What follow are general steps to build the Mini Colecovision

- Create main PCB from schematic/gerber/coleco_original.zip
- Create Right Angle PCB from schematic/gerber/right_angle/right_angle.zip
- Program ROM with BIOS
- Populate main PCB
- Populate right angle PCB
- Power up and program CPLD
- Build your own case

## 2.1 Dependencies

The following are the dependencies needed to build the firmware and PCB for the system.

- Quartus 13.0 sp1
- python 3.X
- KiCAD v7.X

5

### 2.1.1 Protable Coleco Glue File List

- src

– ’src/porta_glue_coleco.v’: ’file_type’: ’verilogSource’

- constr

– ’constr/porta_glue_coleco.sdc’: ’file_type’: ’SDC’

- tb

– ’tb/tb_porta_glue_coleco.v’: ’file_type’: ’verilogSource’

### 2.1.2 Fusesoc

Fusesoc is used for the simulation target only. There are no build targets due to the use of Quartus 13.0sp1. This makes the use of it a bit silly. It does make it easier to use in future projects where the RAM,ROM,CPU,VDP, and Sound chips are also IP cores.

### 2.1.3 Protable Coleco Glue Targets

- default

Info: Default IP target for future tool intergration. – src
– constr
- sim

Info: Simulation target for basic test bench. – src
– tb

### 2.1.4 Quartus

This project uses the last version of Quartus that supports the MAX7000S series. The version is 13.0sp1. The project is located at src/quartus13sp01/. Once you have the project open please follow the soft-wares steps for building and programming the CPLD bitfile.

6

## 2.2 PCB

The four layer PCB is fairly easy to populate. The right angle PCB is a dual layer PCB which is even easier. I recommend starting with resistors, then IC’s, and then the rest. Surface mount parts should be done last. This is a fairly complex project to build, take great caution in making sure your CPU and CPLD are installed correctly. Its easy to rotate square packages these come in.

## 2.3 3D Printed Case

The 3D printed case has been tested on two different printers. It has only been tested with ABS filament. The parts list for the 3D printed case has the STL file name in the value and the XXX.X value is the scale size. In general I recommend the following steps for assembly.

1. Front, populate side controls w/buttons. PCB will need to be cut down to fit height wise.
2. Front, populate LCD screen.
3. Front, Insert Power LED
4. Front, Route LCD screen wires under gamepad. Glue LED wires to side of case to keep out of DPAD.
5. Front, Mount colecovision_controller with buttons.
6. Front, Insert speaker with spacer.
7. Front, Glue or use speaker_mount to hold speaker.
8. Front, Mount USB battery charger.
9. Cart_back, insert battery, check for wire crimping.
10. Cart_back, mount right angle adaptor.
11. Back, mount cart_back to back.
12. Back, run battery wire to charger
13. Back, run wires from front to main PCB
14. Back, hot glue any wires that seem like they may come off.
15. Back, Mount PCB by inserting the top with the power switch first. Then press it in and watch the reset switch and cart port for binding.
16. Back, Mount serial strips over PCB ports.
17. Finish, mate the back to the front. It should fold together and not give much resistance.

7

## 2.4 Programming

There are two devices that need to be programmed. ROM (read only memory) and the CPLD (complex programmable logic device). They use two different methods to be programmed. The ROM is done off the board and then installed. The CPLD is installed and the JTAG header is used to upload the bitfile.

### 2.4.1 ROM

A TL866 is an excellent device for programming the ROM with a BIOS. The open source minipro application works well with it and its clones. Below is a example command to use to program the ROM with a bios.

$ minipro −p ST27C256 −w coleco_bios . bin

### 2.4.2 CPLD

Quartus 13.0sp1 is the easiest way to build and program the MAX7000 CPLD. You will need an altera blaster. I recommend the chinese clone blasters, they actually worked the best. While the worst was the Tera-sic blaster which did not work at all. As for instructions on how to program it in Quartus, please see the software for details.

8

## 3 Usage

## 3.1 Directory Guide

Below highlights important folders from the root of mini_colecovision.

1. docs Contains all documentation related to this project.
- datasheets Contains all datasheets for components.
- manual Contains user manual and github page that are generated from the latex sources.
2. img Contains images of the project
3. schematic KiCAD v7.X schematic and PCB designs
- gerber Contains gerber files and archives for production.
- pdf PDF schematic
4. src CPLD firmware source
- protable_coleco Contains verilog source code and constraits
- quartus13sp01 Quartus project used to generate firmware.

9

## 4 Module Documentation

What follows are PDF pages generated from natural docs HTML pages. This documents the source code used for the CPLD.

10

# porta_glue_coleco.v

## AUTHORS

## JAY CONVERTINO

## DATES

2024/11/06

## INFORMATION

## Brief

Colecovision SGM glue logic chip

## License MIT

Copyright 2024 Jay Convertino
Permission is hereby granted, free of charge, to any person obtaining a copy of this software and associated documentation files (the "Software"), to deal in the Software without restriction, including without limitation the rights to use, copy, modify, merge, publish, distribute, sublicense, and/or sell copies of the Software, and to permit persons to whom the Software is furnished to do so, subject to the following conditions: The above copyright notice and this permission notice shall be included in all copies or substantial portions of the Software.
THE SOFTWARE IS PROVIDED "AS IS", WITHOUT WARRANTY OF ANY KIND, EXPRESS OR IMPLIED, INCLUDING BUT NOT LIMITED TO THE WARRANTIES OF MERCHANTABILITY, FITNESS FOR A PARTICULAR PURPOSE AND NONINFRINGEMENT. IN NO EVENT SHALL THE AUTHORS OR COPYRIGHT HOLDERS BE LIABLE FOR ANY CLAIM, DAMAGES OR OTHER LIABILITY, WHETHER IN AN ACTION OF CONTRACT, TORT OR OTHERWISE, ARISING FROM, OUT OF OR IN CONNECTION WITH THE SOFTWARE OR THE USE OR OTHER DEALINGS IN THE SOFTWARE.

## CONSTANTS

## DEF_RESET_DELAY

Number ticks for reset delay register

## DEF_FB_MONOSTABLE_COUNT

delay till state is at 1 instead of 0 (its stable state) for feedback stable circuit

## DEF_IRQ_MONOSTABLE_COUNT

11 delay till state is at 1 instead of 0 (its stable state) for the controller (spinner) generated interrupt.

## porta_glue_coleco

module porta_glue_coleco ( input
clk,

15:0]
A,
input
C1P1,
input
C1P2,
input
C1P3,
input
C1P4,
input
C1P6,
input
C1P7,
input
C1P9,
input
C2P1,
input
C2P2,
input
C2P3,
input
C2P4,
input
C2P6,
input
C2P7,
input
C2P9,
input
MREQn,
input
IORQn,
input
RFSHn,
input
M1n,
input
WRn,
input
RESETn_SW,
input
RDn,

7:0]
D,
output
CP5_ARM,
output
CP8_FIRE,
output
CS_h8000n,
output
CS_hA000n,
output

12

CS_hC000n,
output
CS_hE000n,
output
SND_ENABLEn,
output
ROM_ENABLEn,
output
RAM_CSn,
output
RAM_OEn,
output
CSWn,
output
CSRn,
output
WAITn,
output
RESETn,
output
RAM_MIRRORn,
output
INTn,
output
AS,
output
AY_SND_ENABLEn
)

Colecovision Super Game Module Glue Logic

### Ports

clk | Clock for all devices in the core

A Address input bus from Z80

C1P1 | DB9 Controller 1 Pin 1
C1P2 | DB9 Controller 1 Pin 2
C1P3 | DB9 Controller 1 Pin 3
C1P4 | DB9 Controller 1 Pin 4
C1P6 | DB9 Controller 1 Pin 6
C1P7 | DB9 Controller 1 Pin 7
C1P9 | DB9 Controller 1 Pin 9
C2P1 | DB9 Controller 2 Pin 1
C2P2 | DB9 Controller 2 Pin 2
C2P3 | DB9 Controller 2 Pin 3
C2P4 | DB9 Controller 2 Pin 4
C2P6 | DB9 Controller 2 Pin 6

13

C2P7 | DB9 Controller 2 Pin 7
C2P9 | DB9 Controller 2 Pin 9
MREQn | Z80 memory request input, active low
IORQn | Z80 IO request input, active low
RFSHn | Z80 Refresh input, active low
M1n | Z80 M1 state, active low
WRn | Z80 Write to bus, active low
RESETn_SW | Input for reset switch
RDn | Z80 Read from bus, active low

D Z80 8 bit data bus, tristate IN/OUT

CP5_ARM | DB9 Controller 1&2 ARM Select
CP8_FIRE | DB9 Controller 1&2 FIRE Select
CS_h8000n | Select when Z80 requests memory at h8000 (GAME CART), active low
CS_hA000n | Select when Z80 requests memory at hA000 (GAME CART), active low
CS_hC000n | Select when Z80 requests memory at hC000 (GAME CART), active low
CS_hE000n | Select when Z80 requests memory at hE000 (GAME CART), active low
SND_ENABLEn | SN76489 Sound chip enable, active low
ROM_ENABLEn | Enable BIOS ROM, active low
RAM_CSn | RAM chip select, active low
RAM_OEn | RAM Ouput enable, active low
CSWn | Chip Select Write for VDP, active low
CSRn | Chip Select Read for VDP, active low
WAITn | Wait state generator for Z80, active low
RESETn | Timed reset generated by Logic, active low
RAM_MIRRORn | Extended RAM, high is extended RAM, active low is mirrored.
INTn | Interrupt generator for Z80, active low

14

AS | AY sound chip address(0)/data(1) select
AY_SND_ENABLEn | AY sound enable, active low

## REGISTER INFORMATION

Core has 3 registers at the addresses that follow.
SOUND_ADDR_CACHE | h50
SOUND_CACHE | h51
RAM_24K_ENABLE | h53
SWAP_BIOS_TO_RAM | h7F

## SOUND_ADDR_CACHE

localparam SOUND_ADDR_CACHE = 8'h50

Defines the address of r_snd_addr_cache

Setup an address for cache the sound address so each write will be to a proper address (opcode games need to write multiple and read multiple addresses) The resister is only 2 bits, and is set to data line bits 2:1 to create a shift to divide all address by 2. Reducing the number of registers in r_snd_cache to 4.

## SOUND_CACHE

localparam SOUND_CACHE = 8'h51

Defines the address of r_snd_cache

Cache Sound Chip as the SGM games read from it (Yamaha chip does not have a read like a GI does).

## RAM_24K_ENABLE

localparam RAM_24K_ENABLE = 8'h53

Defines the address of r_24k_ena

15

Super Game Module 24K RAM enable using bit 0 (Active High)

## SWAP_BIOS_TO_RAM

localparam SWAP_BIOS_TO_RAM = 8'h7F

Defines the address of r_swap_ena

Super Game Module BIOS to RAM swap on bit 1 (Active Low)

## r_snd_addr_cache

reg [ 1:0] r_snd_addr_cache = 0

register for SOUND_ADDR_CACHE See Also: SOUND_ADDR_CACHE

## r_24k_ena

reg [ 7:0] r_24k_ena = 0

register for RAM_24K_ENABLE See Also: RAM_24K_ENABLE

## r_swap_ena

reg [ 7:0] r_swap_ena = 8'h0F

register for 8K RAM/ROM swap See Also: SWAP_BIOS_TO_RAM

## r_snd_cache

reg [ 7:0] r_snd_cache[3:0]

register for SOUND_CACHE See Also: SOUND_CACHE

## r_int_p1

16

reg r_int_p1 = 1'b0

Interrupt from player one control

## r_int_p2

reg r_int_p2 = 1'b0

Interrupt from player two control

## r_wait

reg r_wait = 1'b0

Wait state generated register

## r_reset_counter

reg [ 7:0] r_reset_counter = 0

Timed reset counter

## r_resetn

reg r_resetn = 0

Registered reset output, active low

## r_mono_count_p1

reg [11:0] r_mono_count_p1 = 0

monostable circuit counters, player 1 AND

## r_mono_count_p2

reg [11:0] r_mono_count_p2 = 0

monostable circuit counters, player 2 AND

## r_mono_count_int_p1

reg [ 5:0] r_mono_count_int_p1 = 0

monostable circuit counters, player 1 interrupt

17

## r_mono_count_int_p2

reg [ 5:0] r_mono_count_int_p2 = 0

monostable circuit counters, player 2 interrupt

## r_mono_p1

reg r_mono_p1 = 1'b0

Feedback from IRQ to controller 1 register

## r_mono_p2

reg r_mono_p2 = 1'b0

Feedback from IRQ to controller 2 register

## r_ctrl_fire

reg r_ctrl_fire = 1'b1

NAND Feedback Flip Flop FIRE select.

## r_ctrl_arm

reg r_ctrl_arm = 1'b0

NAND Feedback Flip Flop ARM select.

## ASSIGNMENT INFORMATION

How signals are created

## s_ram_csn

assign s_ram_csn = (
s_y0_seln |
r_swap_ena[1]
) & (s_ram2_csn | ~r_24k_ena[0]) & (s_ram1_csn | ~r_24k_ena[0]) & s_ram0_cs

RAM Chip select when address is requested (active low).
(s_y0_seln | r_swap_ena[1]) | address range starting at h0000, swap bios/rom bit is enabled (1 is disabled).
(s_ram1_csn | ~r_24k_ena[0]) | address range starting at h4000, 24k enable bit from register.
(s_ram2_csn | ~r_24k_ena[0]) | address range starting at h2000, 24k enable bit from register.

18

s_ram0_csn | address range starting h6000, this is always an available range.

## RAM_OEn

assign RAM_OEn = RDn | s_ram_csn

RAM Output enable when read is requested (active low).
RDn | Z80 read request, active low.
s_ram_csn | See Also: s_ram_csn

## RAM_CSn

assign RAM_CSn = s_ram_csn

RAM Chip Select output assignment. s_ram_csn See Also: s_ram_csn

## RAM_MIRRORn

assign RAM_MIRRORn = (
r_24k_ena[0] |
~
r_swap_ena[1]
)

RAM Mirror enable. Output to AND gates that block address lines (active low)
r_24k_ena[0] | If 24k ram extension is disabled, enable ram mirror
r_swap_ena[1] | If ram/bios swap is disabled, enable ram mirror.

## ROM_ENABLEn

assign ROM_ENABLEn = (
s_y0_seln |
~
r_swap_ena[1]
)

ROM enable (active low).
s_y0_seln | Only select ROM when address range h0000 is enabled.
r_swap_ena[1] | If ram/bios swap is disabled, enable ROM.

## DECODER INFORMATION FOR U5

How address decoder is created.

## s_enable_u5

19

assign s_enable_u5 = (
RFSHn &
~
MREQn
)

Enable the the decoder, duplicates U5 functionality from colecovision. always 1, RFSH is a double inversion on coleco (inverter + 138 internal)
RFSHn | Z80 Refresh line, when not in refresh enable is active.
MREQn | When the MREQn is active then encoder is enabled.

## s_y0_seln

assign s_y0_seln = ~(

A[14] &
~
A[13]
)

Address h0000, ROM/RAM
s_enable_u5 | Enable decoder
A[15:13] | Address lines used for select lines.

## s_ram2_csn

assign s_ram2_csn = ~(

A[14] &
A[13]
)

Address h2000, RAM
s_enable_u5 | Enable decoder
A[15:13] | Address lines used for select lines.

## s_ram1_csn

assign s_ram1_csn = ~(

A[14] &
~
A[13]
)

Address h4000, RAM
s_enable_u5 | Enable decoder
A[15:13] | Address lines used for select lines.

## s_ram0_csn

20

assign s_ram0_csn = ~(

A[14] &
A[13]
)

Address h6000, RAM
s_enable_u5 | Enable decoder
A[15:13] | Address lines used for select lines.

## CS_h8000n

assign CS_h8000n = ~(

A[14] &
~
A[13]
)

Address h8000, Game ROM bank select.
s_enable_u5 | Enable decoder
A[15:13] | Address lines used for select lines.

## CS_hA000n

assign CS_hA000n = ~(

A[14] &
A[13]
)

Address hA000, Game ROM bank select.
s_enable_u5 | Enable decoder
A[15:13] | Address lines used for select lines.

## CS_hC000n

assign CS_hC000n = ~(

A[14] &
~
A[13]
)

Address hC000, Game ROM bank select.
s_enable_u5 | Enable decoder
A[15:13] | Address lines used for select lines.

## CS_hE000n

21

assign CS_hE000n = ~(

A[14] &
A[13]
)

Address hE000, Game ROM bank select.
s_enable_u5 | Enable decoder
A[15:13] | Address lines used for select lines.

## DECODER INFORMATION FOR U6

How address decoder is created

## s_enable_u5

Enable the the decoder, duplicates U6 functionality from colecovision.
A[7] | Address IO range h80 to hFF
IORQn | When the IORQn is active then encoder is enabled.

## s_ctrl_en_2n

assign s_ctrl_en_2n = ~(

A[5] &
~
WRn
)

h80 PORT IO for controller Fire Select
s_enable_u6 | Enable decoder
A[6:5] | Address lines used for select lines.
WRn | Select write or read.

## CSWn

assign CSWn = ~(

A[5] &
~
WRn
)

hBE PORT IO for VDP write
s_enable_u6 | Enable decoder
A[6:5] | Address lines used for select lines.
WRn | Select write or read.

22

## CSRn

assign CSRn = ~(

A[5] &
WRn
)

hBF PORT IO for VDP read
s_enable_u6 | Enable decoder
A[6:5] | Address lines used for select lines.
WRn | Select write or read.

## s_ctrl_en_1n

assign s_ctrl_en_1n = ~(

A[5] &
~
WRn
)

hC0 PORT IO for controller ARM select
s_enable_u6 | Enable decoder
A[6:5] | Address lines used for select lines.
WRn | Select write or read.

## SND_ENABLEn

assign SND_ENABLEn = ~(

A[5] &
~
WRn
)

hFF PORT IO for sound enable.
s_enable_u6 | Enable decoder
A[6:5] | Address lines used for select lines.
WRn | Select write or read.

## s_ctrl_readn

assign s_ctrl_readn = ~(

A[5] &
WRn
)

hFC/FF PORT IO for controller read s_enable_u6 Enable decoder

23

A[6:5] | Address lines used for select lines.
WRn | Select write or read.

## DECODER INFORMATION FOR SUPER GAME MODULE

How address decoder is created for Super Game Module
SGM IO REG Clocked IO decoder for Super Game Module.

AS

assign AS = (
A[7:0]

)

h50 is the address select, when selected its in data mode
A[7:0] | If address matches h50, enable
IORQn | Active IO request, enable
WRn | Z80 write is active, enable

## AY_SND_ENABLEn

assign AY_SND_ENABLEn = (
A[7:1]

)

match both h50 and h51 by ignoring bit 0. Enable AY sound chip.
A[7:0] | If address matches h50 or h51, enable
IORQn | Active IO request, enable
WRn | Z80 write is active, enable

## AY_SND_ENABLEn

read cached register from previous write (AY emulation), at set address location (0=0,1=0,2=1,3=1,4=2,5=2,6=3,7=3).
A[7:0] | If address matches h52, enable
IORQn | Active IO request, enable
RDn | Z80 read is active, enable

## CONTROLLER REGISTER READ

How to read controller inputs for player 1 and 2, works with roller and standard gamepads.

## CP5_ARM

24 assign CP5_ARM = r_ctrl_arm

Activate ARM porition of controllers. r_ctrl_arm See Also: r_ctrl_arm

## CP8_FIRE

assign CP8_FIRE = r_ctrl_fire

Activate FIRE porition of controllers. r_ctrl_fire See Also: r_ctrl_fire

D[0]

assign D[0] = (

C1P1
:
1'bz
)

Data bit zero for P1
s_ctrl_readn | See Also: s_ctrl_readn, read when active low
A[1] | Address bit 1 is 0, read

D[1]

assign D[1] = (

C1P4
:
1'bz
)

Data bit one for P1
s_ctrl_readn | See Also: s_ctrl_readn, read when active low
A[1] | Address bit 1 is 0, read

D[2]

assign D[2] = (

C1P2
:
1'bz
)

Data bit two for P1
s_ctrl_readn | See Also: s_ctrl_readn, read when active low
A[1] | Address bit 1 is 0, read

25

D[3]

assign D[3] = (

C1P3
:
1'bz
)

Data bit three for P1
s_ctrl_readn | See Also: s_ctrl_readn, read when active low
A[1] | Address bit 1 is 0, read

D[4]

assign D[4] = (

r_mono_p1
:
1'bz
)

Data bit one for P1
s_ctrl_readn | See Also: s_ctrl_readn, read when active low
A[1] | Address bit 1 is 0, read

D[5]

assign D[5] = (

C1P7
:
1'bz
)

Data bit five for P1
s_ctrl_readn | See Also: s_ctrl_readn, read when active low
A[1] | Address bit 1 is 0, read

D[6]

assign D[6] = (

C1P6
:
1'bz
)

Data bit six for P1
s_ctrl_readn See Also: s_ctrl_readn, read when active low

26

A[1] | Address bit 1 is 0, read

D[7]

assign D[7] = (

s_int_p1
:
1'bz
)

Data bit seven for P1
s_ctrl_readn | See Also: s_ctrl_readn, read when active low
A[1] | Address bit 1 is 0, read

## s_int_p1

assign s_int_p1 = ~(
r_mono_p1 &
C1P9
)

generate interrupt for player one
r_mono_p1 | See Also: r_mono_p1, RC TL emulation
C1P9 | Input from controller port. Roller controller only.

D[0]

assign D[0] = (

C2P1
:
1'bz
)

Data bit zero for P2
s_ctrl_readn | See Also: s_ctrl_readn, read when active low
A[1] | Address bit 1 is 1, read

D[1]

assign D[1] = (

C2P4
:
1'bz
)

Data bit one for P2
s_ctrl_readn See Also: s_ctrl_readn, read when active low

27

A[1] | Address bit 1 is 1, read

D[2]

assign D[2] = (

C2P2
:
1'bz
)

Data bit two for P2
s_ctrl_readn | See Also: s_ctrl_readn, read when active low
A[1] | Address bit 1 is 1, read

D[3]

assign D[3] = (

C2P3
:
1'bz
)

Data bit three for P2
s_ctrl_readn | See Also: s_ctrl_readn, read when active low
A[1] | Address bit 1 is 1, read

D[4]

assign D[4] = (

r_mono_p2
:
1'bz
)

Data bit four for P2
s_ctrl_readn | See Also: s_ctrl_readn, read when active low
A[1] | Address bit 1 is 1, read

D[5]

assign D[5] = (

C2P7
:
1'bz
)

Data bit five for P2

28

s_ctrl_readn | See Also: s_ctrl_readn, read when active low
A[1] | Address bit 1 is 1, read

D[6]

assign D[6] = (

C2P6
:
1'bz
)

Data bit six for P2
s_ctrl_readn | See Also: s_ctrl_readn, read when active low
A[1] | Address bit 1 is 1, read

D[7]

assign D[7] = (

s_int_p2
:
1'bz
)

Data bit seven for P2
s_ctrl_readn | See Also: s_ctrl_readn, read when active low
A[1] | Address bit 1 is 1, read

## s_int_p2

assign s_int_p2 = ~(
r_mono_p2 &
C2P9
)

generate interrupt for player one
r_mono_p1 | See Also: r_mono_p1, RC TL emulation
C2P9 | Input from controller port. Roller controller only.

## INTn

assign INTn = ~(
r_int_p1 |
r_int_p2
)

INTn is generated by monostable circuit based on NAND outputs.
r_int_p1 | See Also: r_int_p1, RC TL emulation
r_int_p2 | See Also: r_int_p2, RC TL emulation

29

## CIRCUIT EMULATION

Everything below emulates a part of the circuit that uses some sort of linear/non-linear components to perform its task. Things such as RC reset circuits, RC interrupts, IRQ and others. See this source file for details.
WAIT GENERATE | Generate wait states for the Z80 procressor
RESET GENERATE | Generate a timed reset for the CPU/VDP/ETC.
TL RC RESET | Generate a interrupt for a monostable circuit that will trigger a 1 for a short duration.
CONTROLLER NAND | Controller NAND Latch FIRE/ARM emulation.
NAND IRQ PULSE | Controller bit 4 is a pulse that represents the spinner state.

30

## 5 Schematics

31

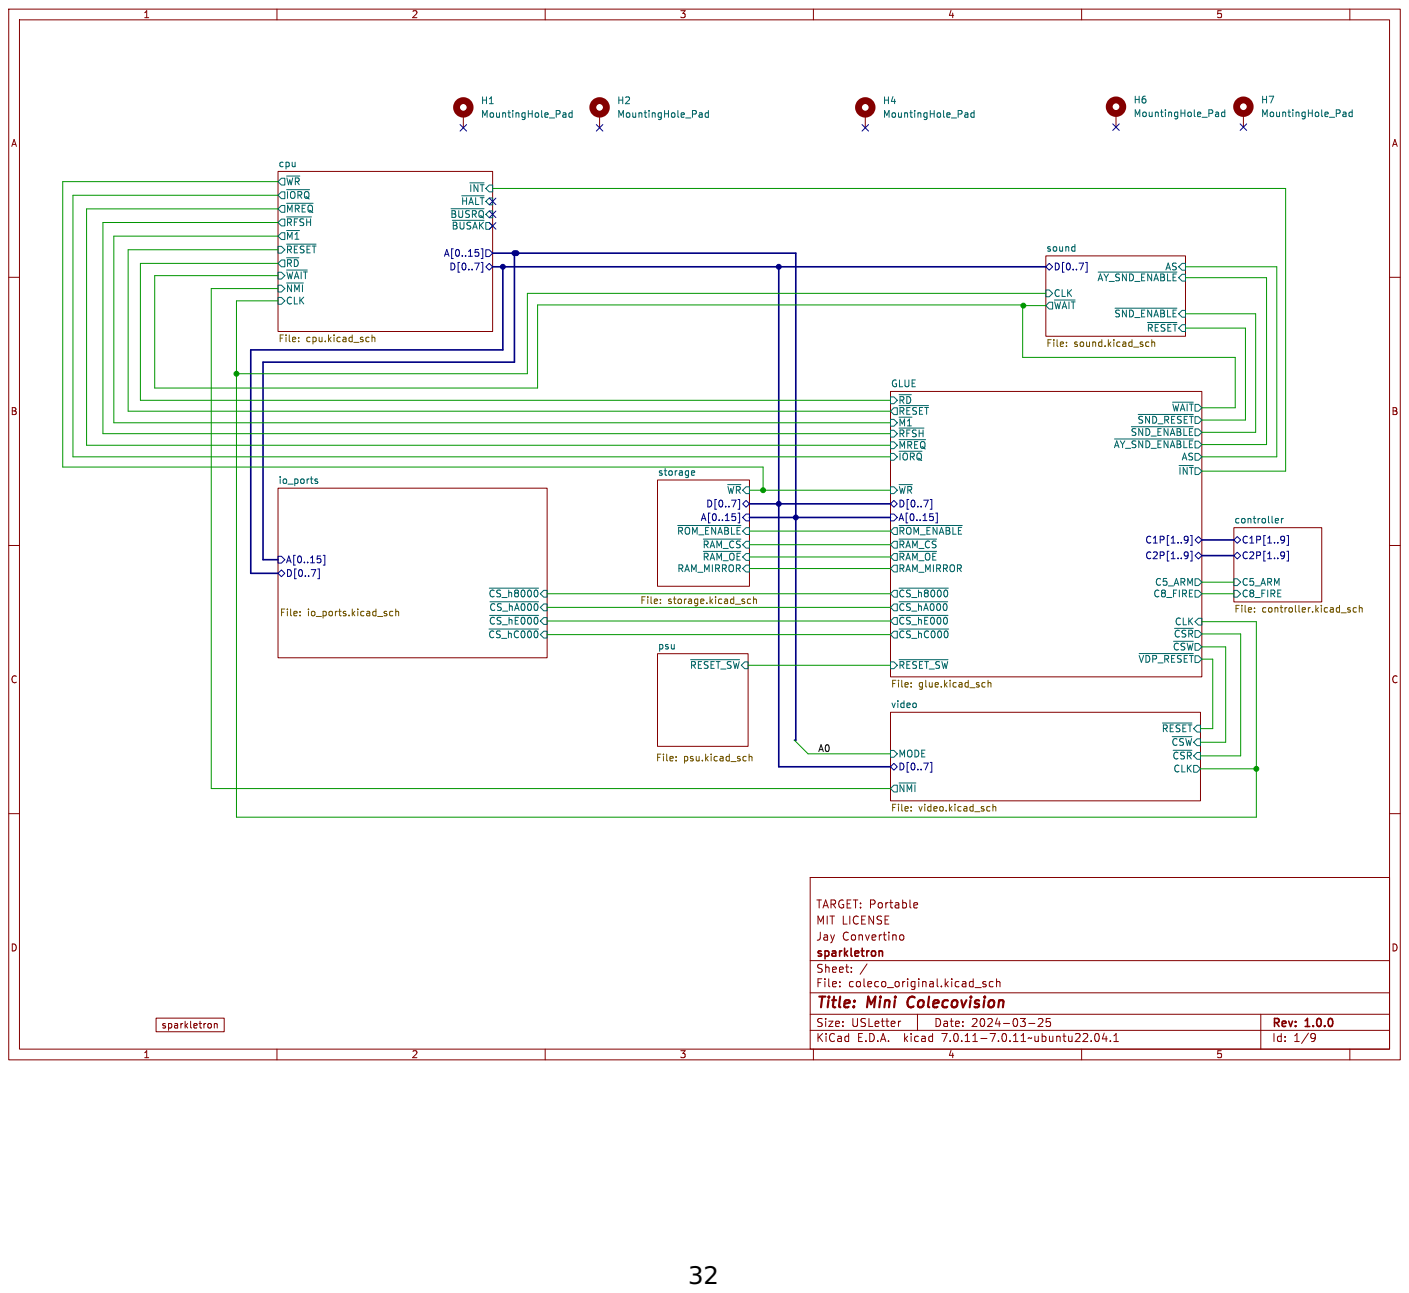
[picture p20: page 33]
D Date: 2024-03-25 KiCad E.D.A. kicad 7.0.11-7.0.11~ubuntu22.04.1 Size: USLetter; Rev: 1.0.0; ~{WAIT}; ~{SND_ENABLE} CLK; ~{RESET}; ~{AY_SND_ENABLE} AS; ~{IORQ}; ~{RFSH}; CLK D[0..7]; ~{MREQ}; ~{SND_ENABLE}; ~{ROM_ENABLE} ~{RAM_CS}; ~{CSW}; ~{CSR}; ~{INT}; ~{VDP_RESET}; ~{RAM_OE}; C8_FIRE C5_ARM; ~{SND_RESET}; ~{AY_SND_ENABLE} AS RAM_MIRROR GLUE; C2P[1..9] C8_FIRE C5_ARM; ~{NMI}; ~{HALT} ~{MREQ}; ~{BUSAK}; ~{BUSRQ}; ~{RFSH} CLK; cpu File: cpu.kicad_sch; io_ports File: io_ports.kicad_sch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

C1P[1..9] controller File: controller.kicad_sch D[0..7]

sound File: sound.kicad_sch ~{WR}

storage File: storage.kicad_sch

~{RESET_SW}
File: glue.kicad_sch
video File: video.kicad_sch

TARGET: Portable
Jay Convertino MIT LICENSE

File: coleco_original.kicad_sch Sheet: / sparkletron

Id: 1/9 Title: Mini Colecovision

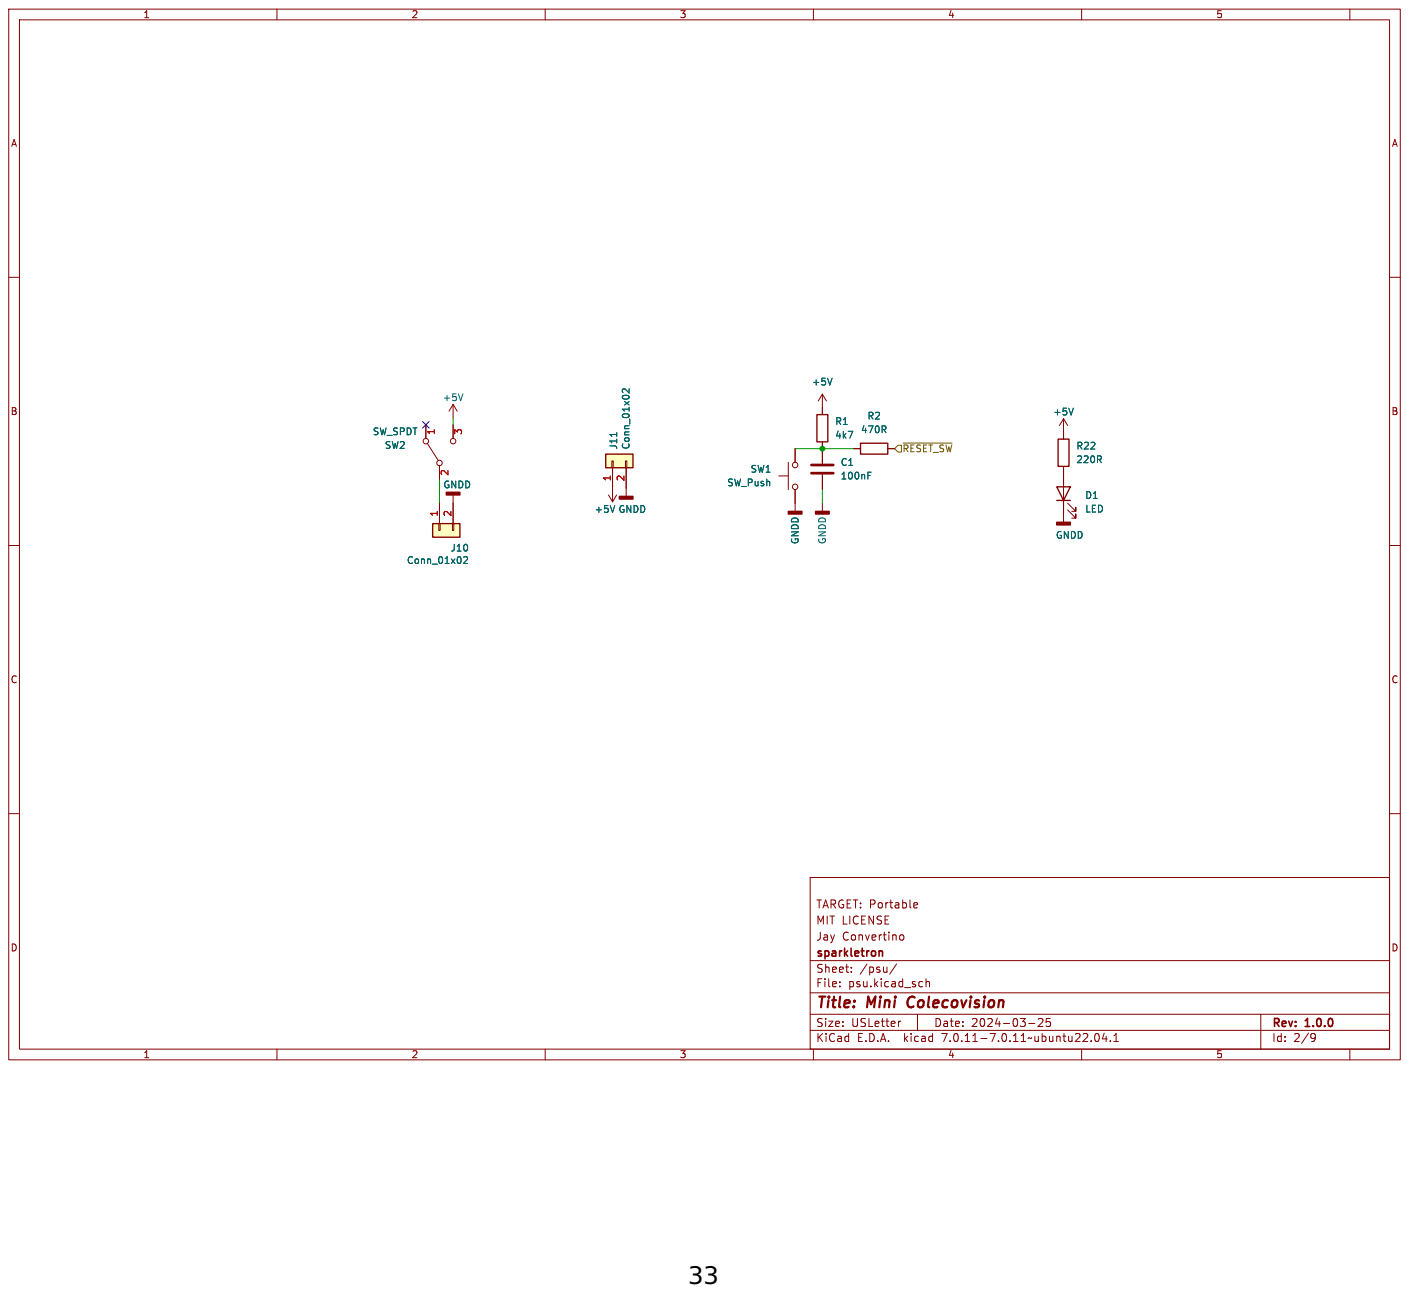
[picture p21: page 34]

LED GNDD GNDD GNDD

Jay Convertino MIT LICENSE

sparkletron
File: psu.kicad_sch Sheet: /psu/
Id: 2/9 Title: Mini Colecovision

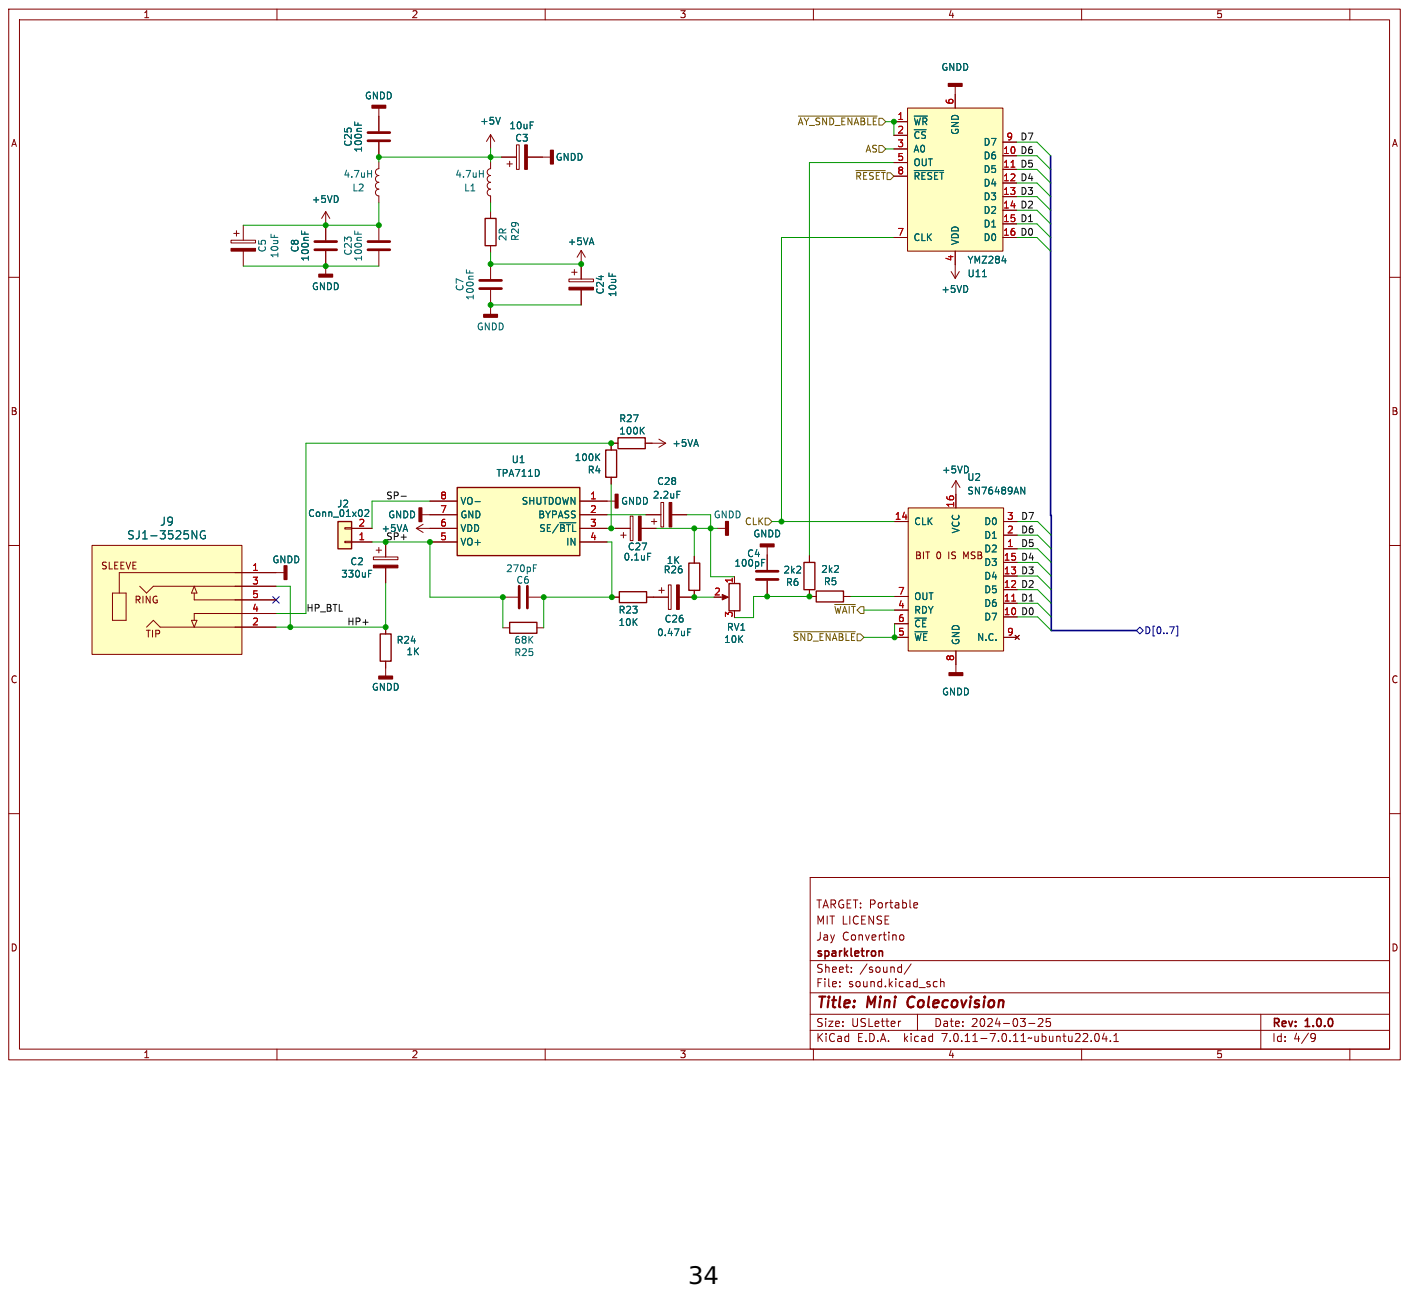
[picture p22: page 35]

6 CLK 7 ~{RESET} 8 D7 9 U11 YMZ284 GNDD GNDD

6 CLK 7 ~{RESET} 8 D7 9 GNDD GNDD

Jay Convertino MIT LICENSE

File: sound.kicad_sch Sheet: /sound/ sparkletron

Id: 4/9 Title: Mini Colecovision

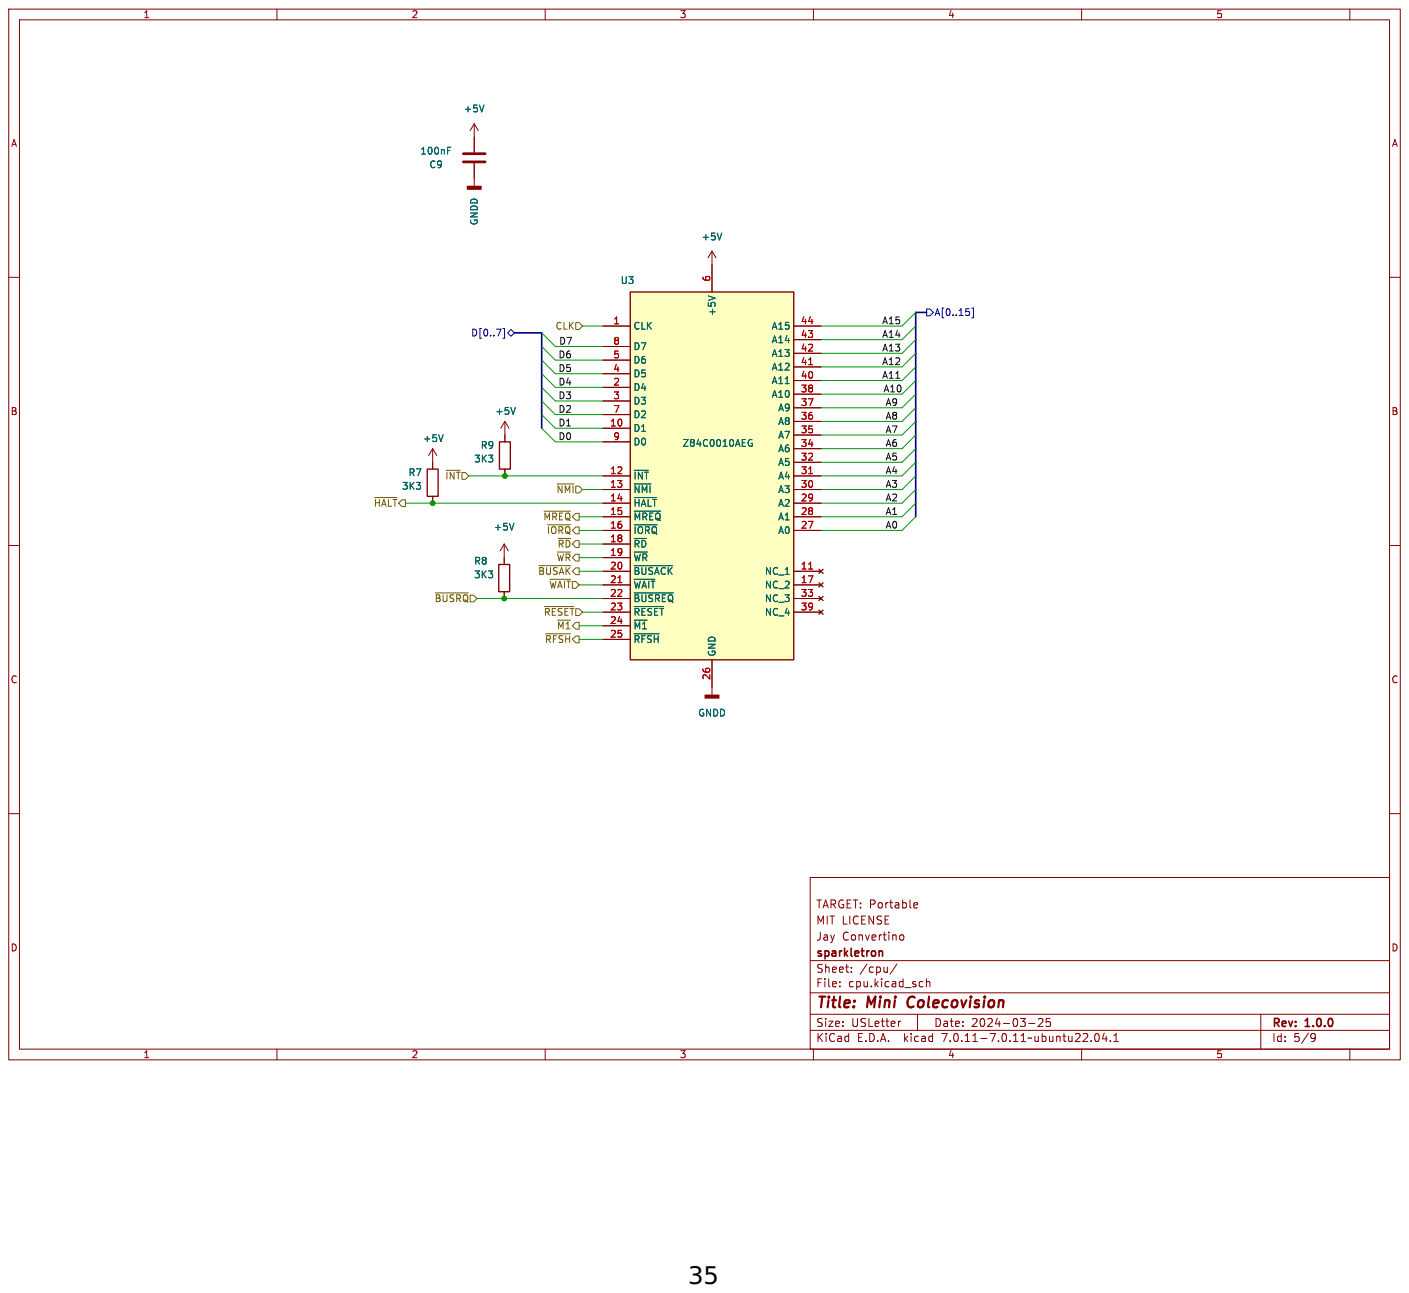
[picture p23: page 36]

TARGET: Portable
Jay Convertino MIT LICENSE

sparkletron
File: cpu.kicad_sch Sheet: /cpu/
Id: 5/9 Title: Mini Colecovision

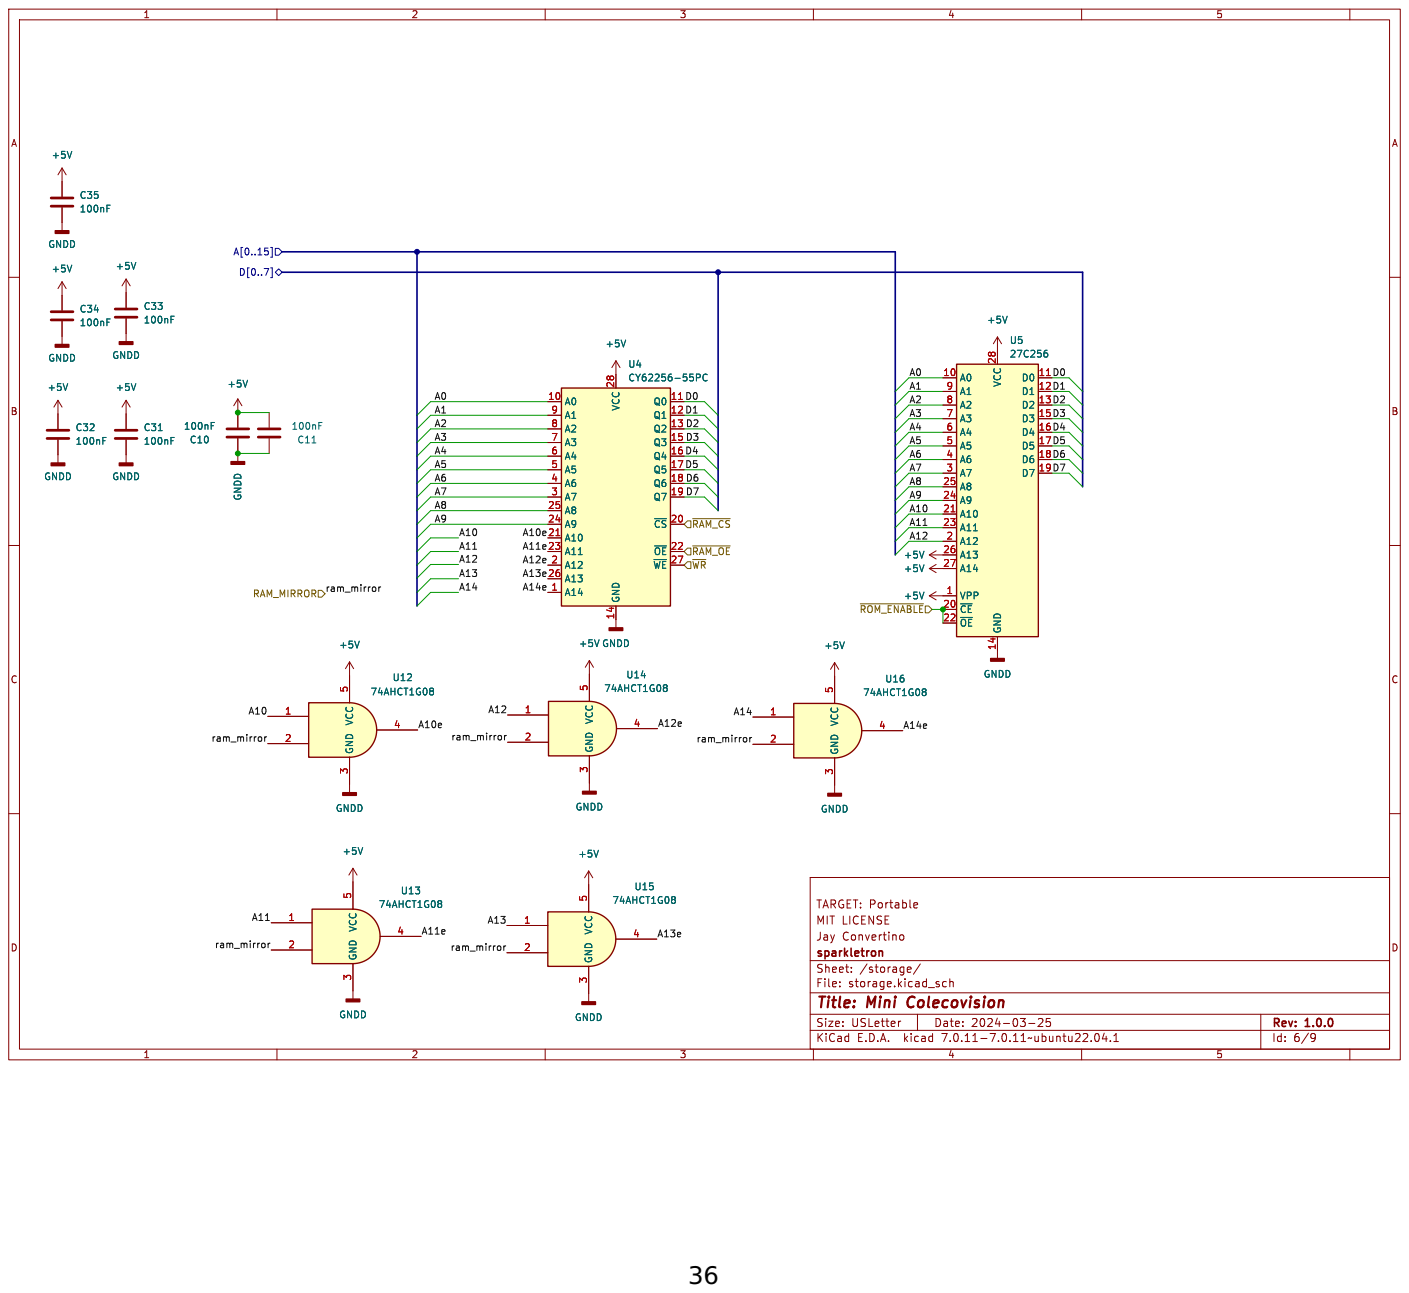
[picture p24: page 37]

Jay Convertino MIT LICENSE

sparkletron
File: storage.kicad_sch Sheet: /storage/
Id: 6/9 Title: Mini Colecovision

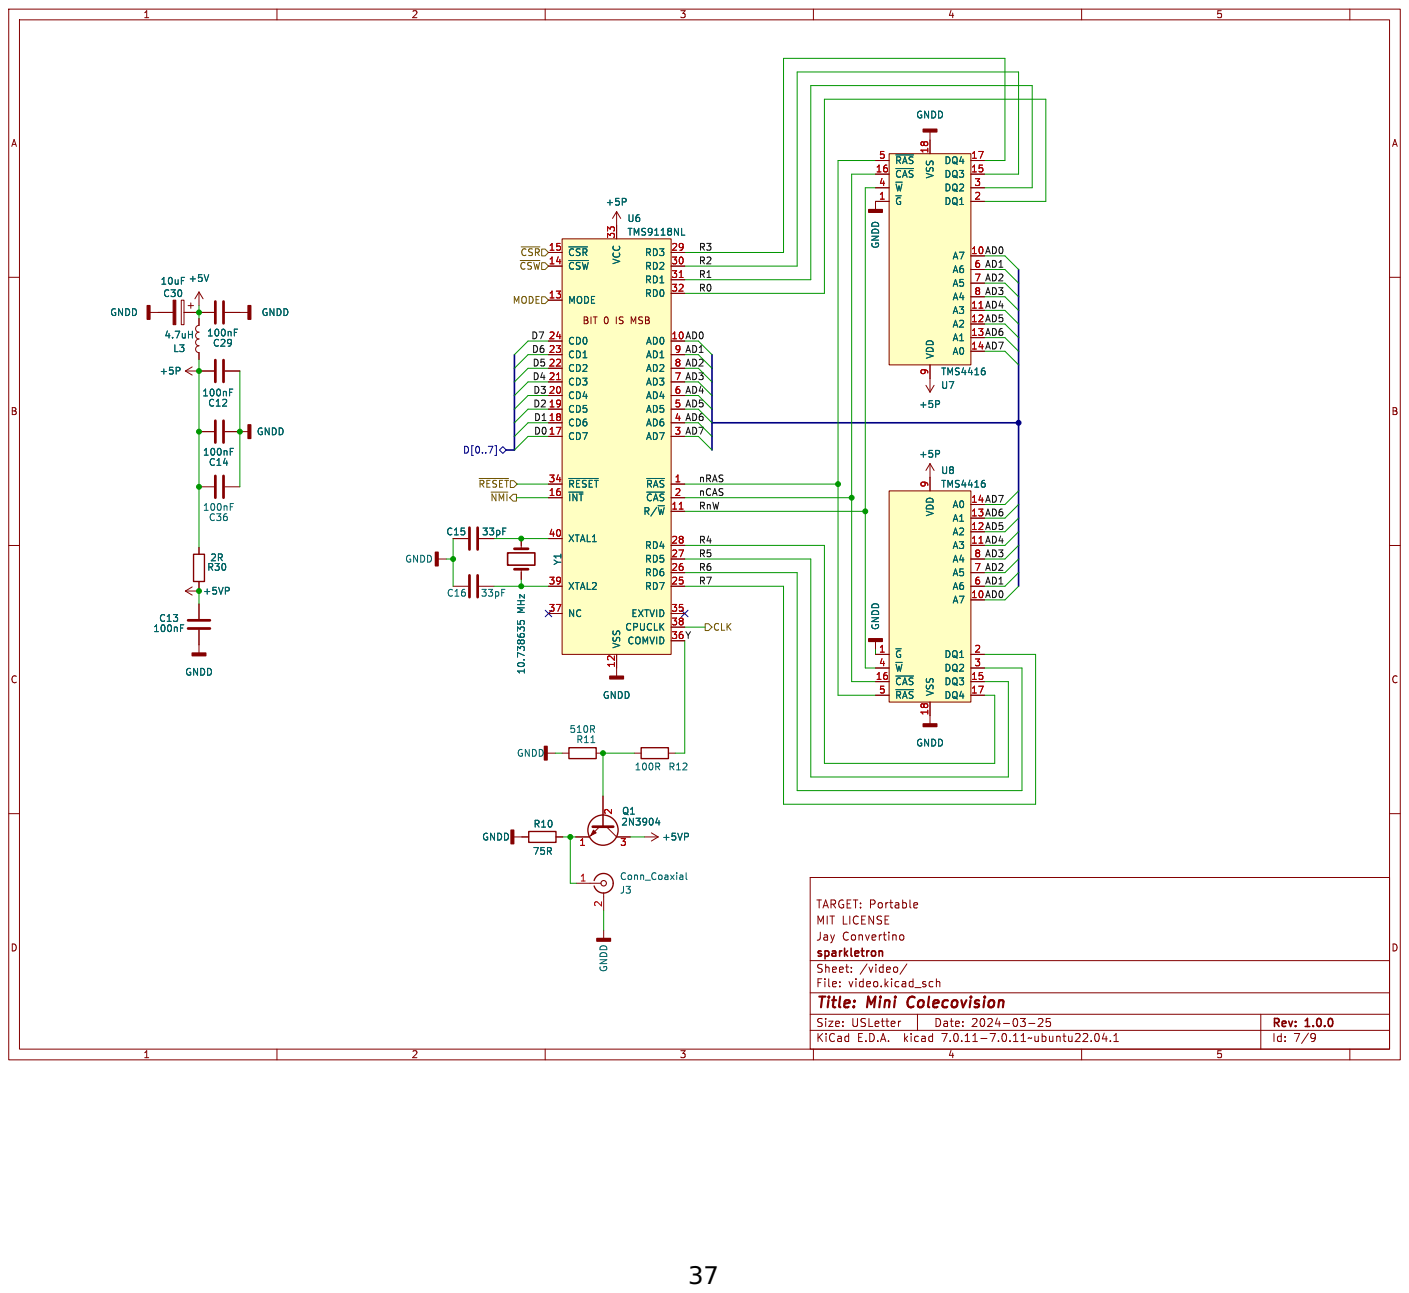
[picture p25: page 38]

Jay Convertino MIT LICENSE

File: video.kicad_sch Sheet: /video/ sparkletron

Id: 7/9 Title: Mini Colecovision

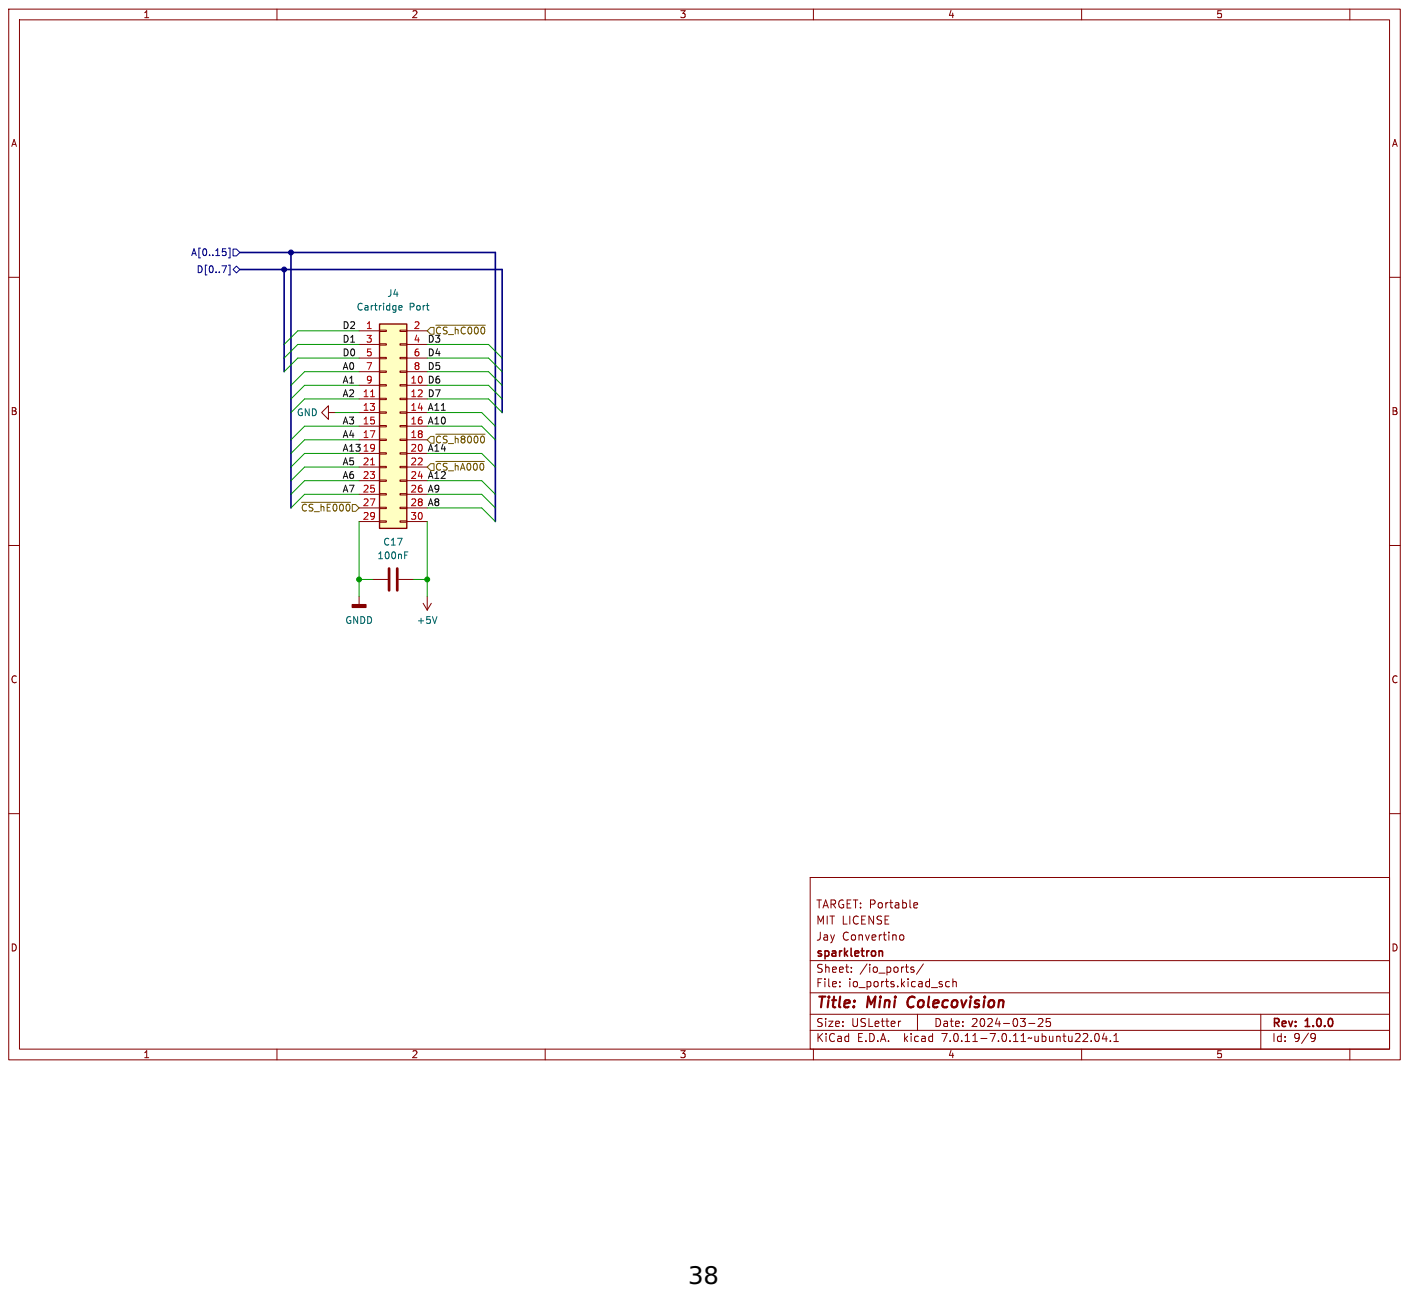
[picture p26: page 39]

Jay Convertino MIT LICENSE

sparkletron
File: io_ports.kicad_sch Sheet: /io_ports/
Id: 9/9 Title: Mini Colecovision

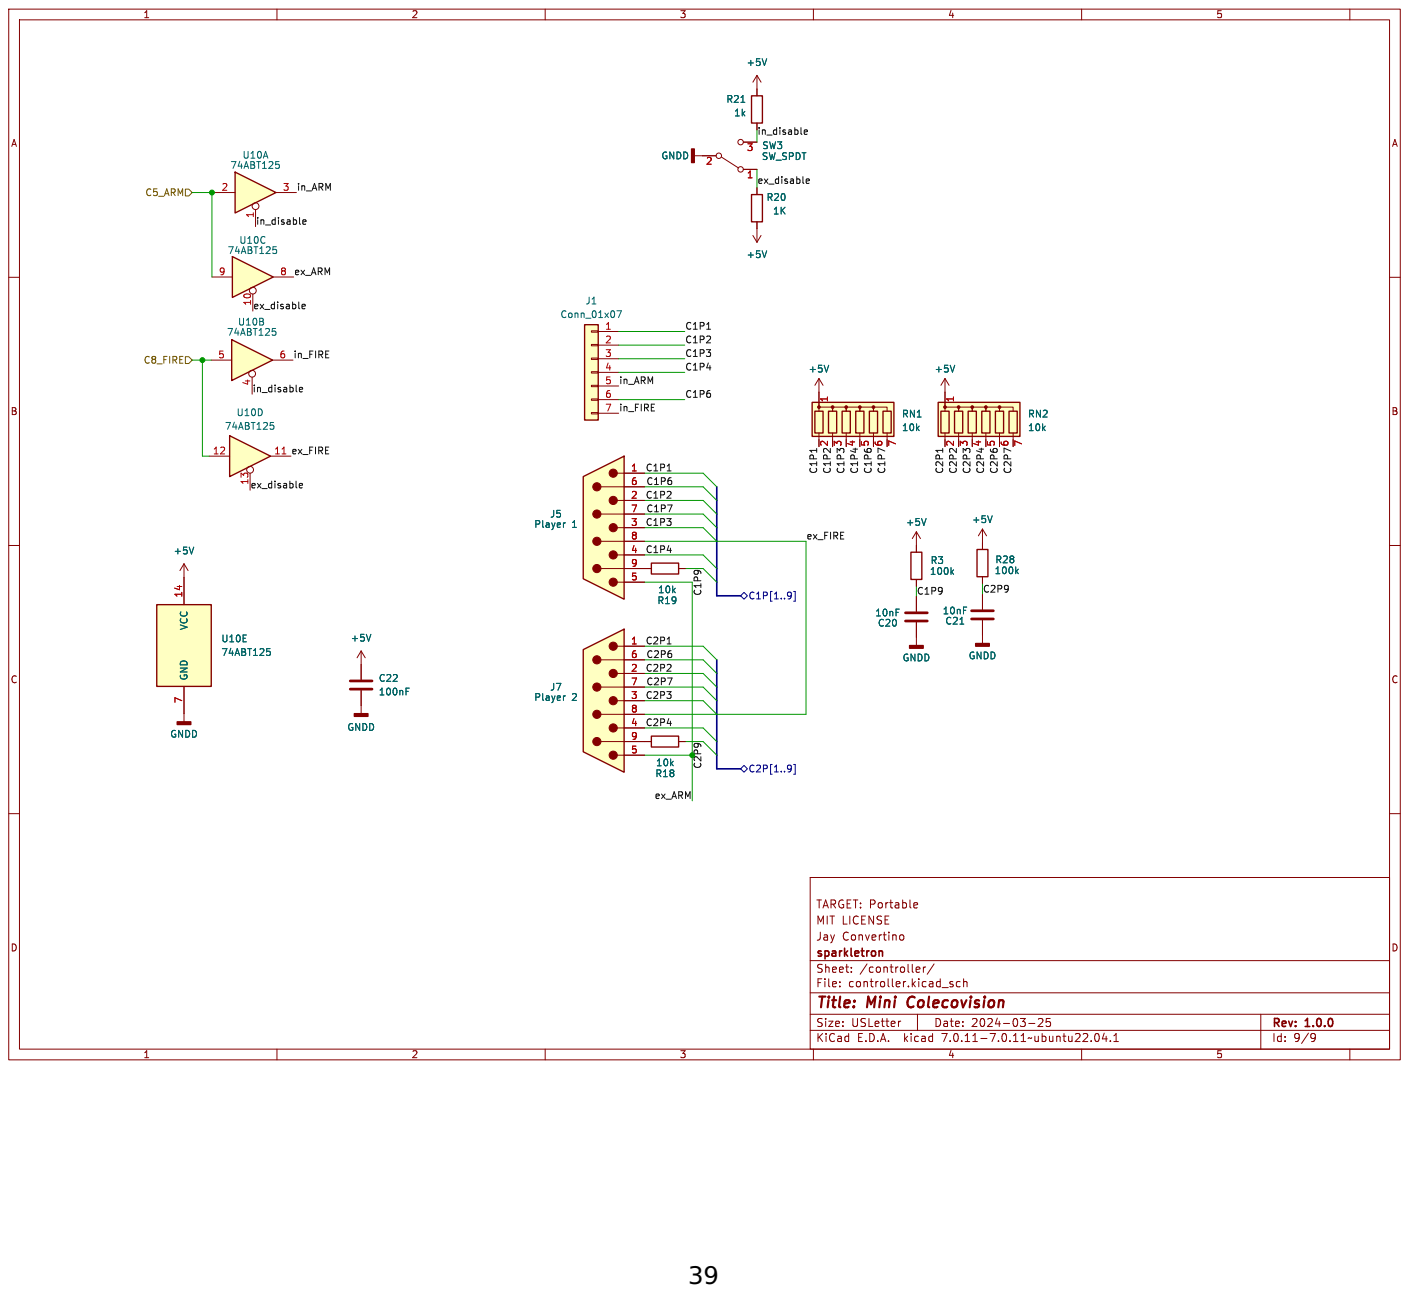
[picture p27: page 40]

J7 Player 2 VCC ¹⁴ GND

Jay Convertino MIT LICENSE

File: controller.kicad_sch Sheet: /controller/ sparkletron

Id: 9/9 Title: Mini Colecovision

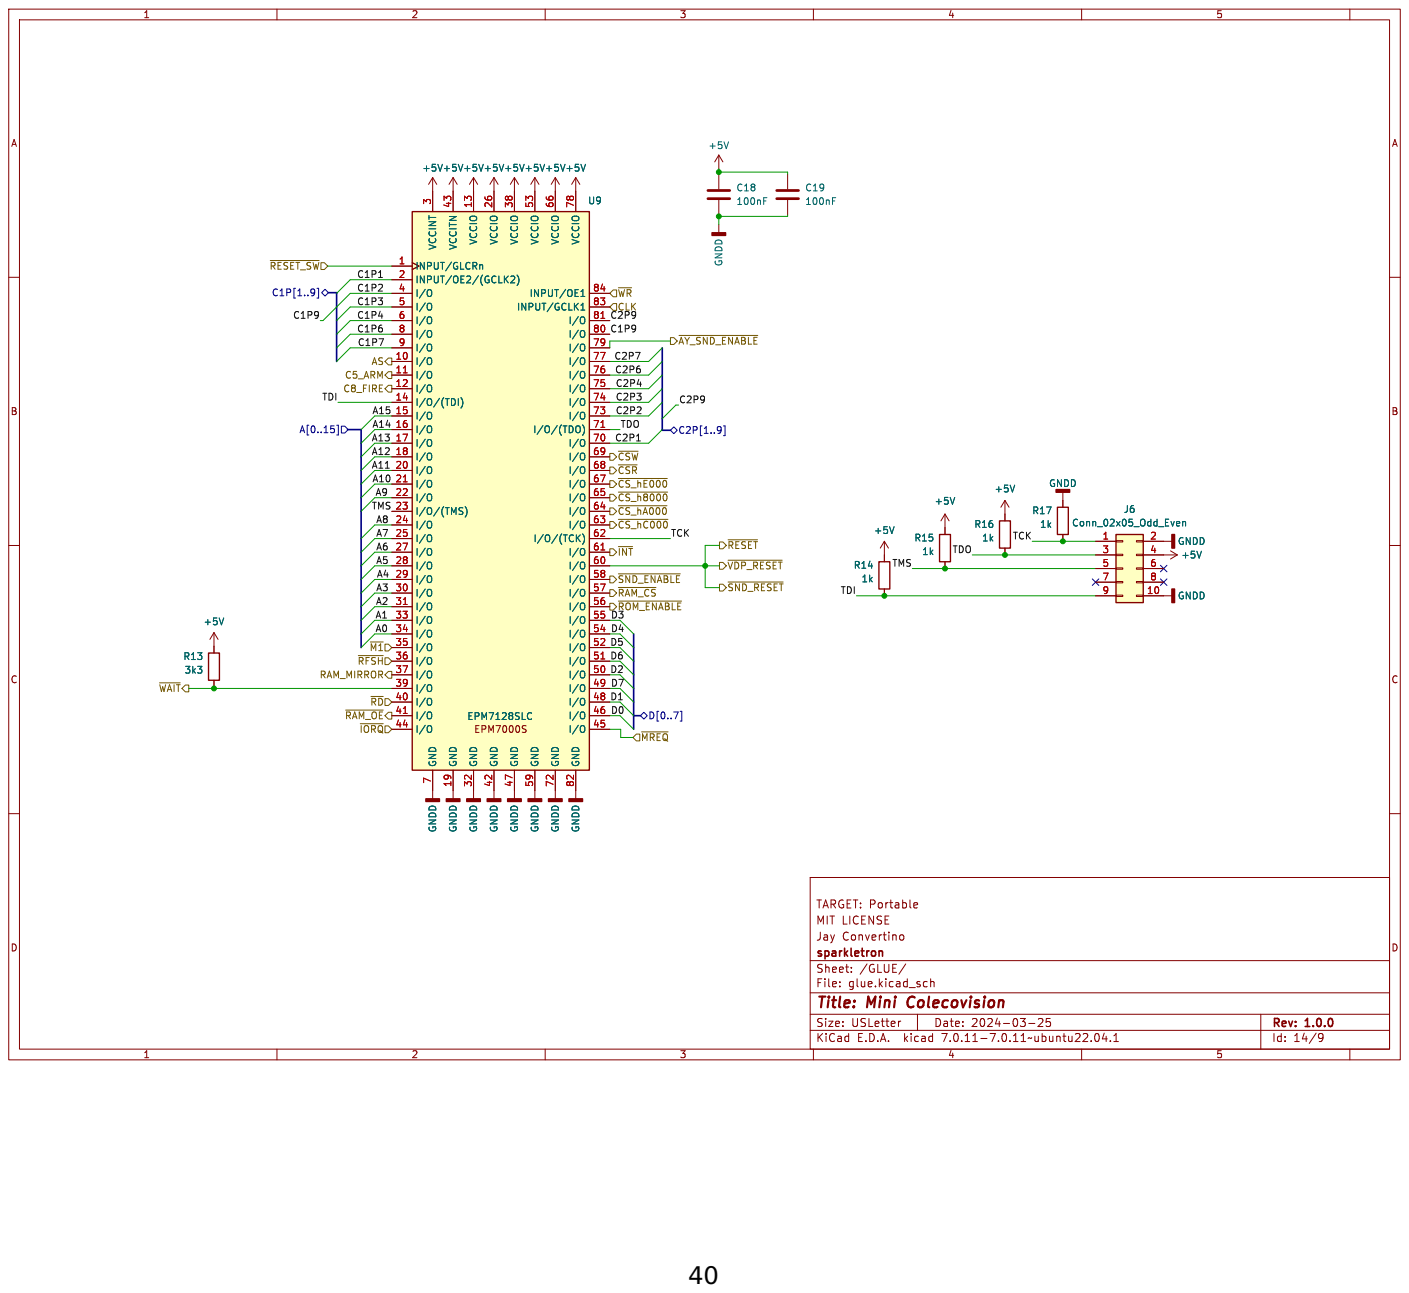
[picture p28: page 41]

TARGET: Portable
Jay Convertino MIT LICENSE

File: glue.kicad_sch Sheet: /GLUE/ sparkletron

Id: 14/9 Title: Mini Colecovision

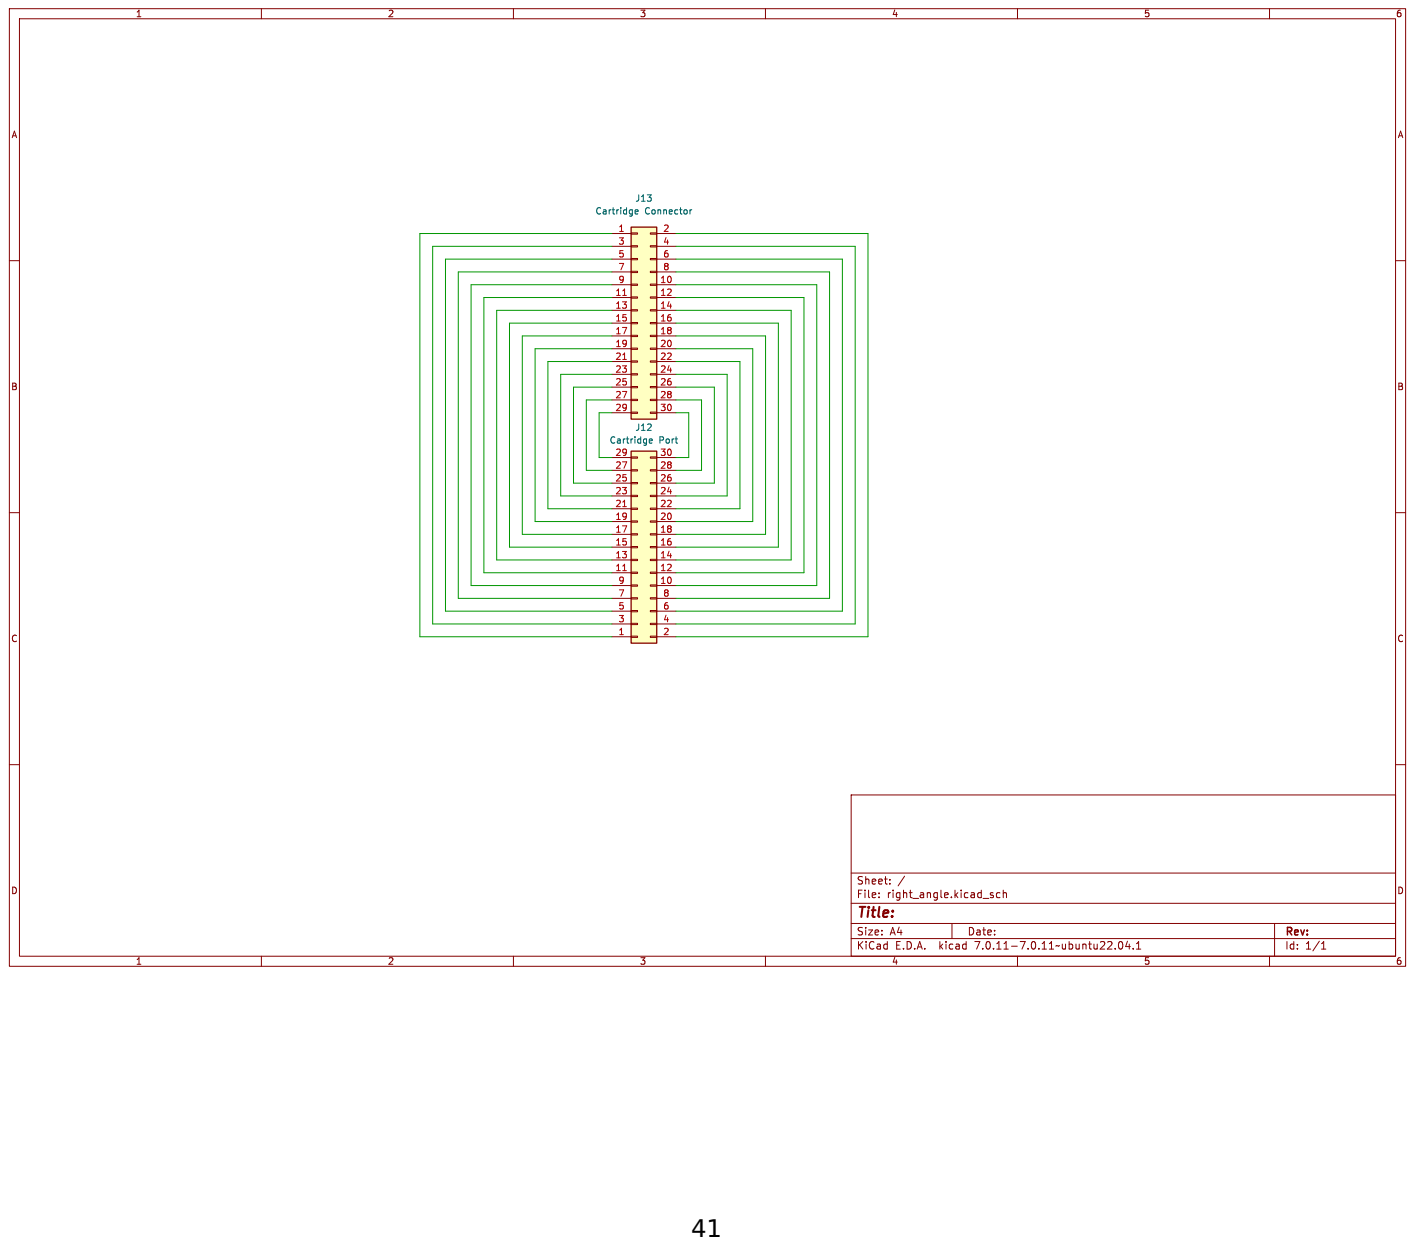
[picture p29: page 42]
D Date: KiCad E.D.A. kicad 7.0.11-7.0.11~ubuntu22.04.1 Size: A4; Rev:; Id: 1/1 Title: File: right_angle.kicad_sch Sheet: / ¹; J12 Cartridge; Port 1; J13 Cartridge; Connector

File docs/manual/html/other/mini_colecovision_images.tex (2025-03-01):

\batchmode
\documentclass{article}
\RequirePackage{ifthen}

\usepackage{graphicx}
\usepackage{listings}
\usepackage{longtable}
\usepackage[hidelinks]{hyperref}

\usepackage{xcolor}

\makeatletter

\makeatletter
\count@=\the\catcode`\_ \catcode`\_=8 
\newenvironment{tex2html_wrap}{}{}%
\catcode`\<=12\catcode`\_=\count@
\newcommand{\providedcommand}[1]{\expandafter\providecommand\csname #1\endcsname}%
\newcommand{\renewedcommand}[1]{\expandafter\providecommand\csname #1\endcsname{}%
  \expandafter\renewcommand\csname #1\endcsname}%
\newcommand{\newedenvironment}[1]{\newenvironment{#1}{}{}\renewenvironment{#1}}%
\let\newedcommand\renewedcommand
\let\renewedenvironment\newedenvironment
\makeatother
\let\mathon=$
\let\mathoff=$
\ifx\AtBeginDocument\undefined \newcommand{\AtBeginDocument}[1]{}\fi
\newbox\sizebox
\setlength{\hoffset}{0pt}\setlength{\voffset}{0pt}
\addtolength{\textheight}{\footskip}\setlength{\footskip}{0pt}
\addtolength{\textheight}{\topmargin}\setlength{\topmargin}{0pt}
\addtolength{\textheight}{\headheight}\setlength{\headheight}{0pt}
\addtolength{\textheight}{\headsep}\setlength{\headsep}{0pt}
\newwrite\lthtmlwrite
\makeatletter
\let\realnormalsize=\normalsize
\global\topskip=2sp
\def\preveqno{}\let\real@float=\@float \let\realend@float=\end@float
\def\@float{\let\@savefreelist\@freelist\real@float}
\def\liih@math{\ifmmode$\else\bad@math\fi}
\def\end@float{\realend@float\global\let\@freelist\@savefreelist}
\let\real@dbflt=\@dbflt \let\end@dblfloat=\end@float
\let\@largefloatcheck=\relax
\let\if@boxedmulticols=\iftrue
\def\@dbflt{\let\@savefreelist\@freelist\real@dbflt}
\def\adjustnormalsize{\def\normalsize{\mathsurround=0pt \realnormalsize
 \parindent=0pt\abovedisplayskip=0pt\belowdisplayskip=0pt}%
 \def\phantompar{\csname par\endcsname}\normalsize}%
\def\lthtmltypeout#1{{\let\protect\string \immediate\write\lthtmlwrite{#1}}}%
\usepackage[tightpage,active]{preview}
\PreviewBorder=1bp
\newbox\lthtmlPageBox
\newdimen\lthtmlCropMarkHeight
\newdimen\lthtmlCropMarkDepth
\long\def\lthtmlTightVBoxA#1{\def\lthtmllabel{#1}
    \setbox\lthtmlPageBox\vbox\bgroup\catcode`\_=8 }%
\long\def\lthtmlTightVBoxZ{\egroup
    \lthtmlCropMarkHeight=\ht\lthtmlPageBox \advance \lthtmlCropMarkHeight 6pt
    \lthtmlCropMarkDepth=\dp\lthtmlPageBox
    \lthtmltypeout{^^J:\lthtmllabel:lthtmlCropMarkHeight:=\the\lthtmlCropMarkHeight}%
    \lthtmltypeout{^^J:\lthtmllabel:lthtmlCropMarkDepth:=\the\lthtmlCropMarkDepth:1ex:=\the \dimexpr 1ex}%
    \begin{preview}\copy\lthtmlPageBox\end{preview}}%
\long\def\lthtmlTightFBoxA#1{\def\lthtmllabel{#1}%
    \adjustnormalsize\setbox\lthtmlPageBox=\vbox\bgroup\hbox\bgroup %
    \let\ifinner=\iffalse \let\)\liih@math %
    \bgroup\catcode`\_=8 }%
\long\def\lthtmlTightFBoxZ{\egroup\egroup
    \@next\next\@currlist{}{\def\next{\voidb@x}}%
    \expandafter\box\next\egroup %
    \lthtmlCropMarkHeight=\ht\lthtmlPageBox \advance \lthtmlCropMarkHeight 6pt
    \lthtmlCropMarkDepth=\dp\lthtmlPageBox
    \lthtmltypeout{^^J:\lthtmllabel:lthtmlCropMarkHeight:=\the\lthtmlCropMarkHeight}%
    \lthtmltypeout{^^J:\lthtmllabel:lthtmlCropMarkDepth:=\the\lthtmlCropMarkDepth:1ex:=\the \dimexpr 1ex}%
    \begin{preview}\copy\lthtmlPageBox\end{preview}}%
    \long\def\lthtmlinlinemathA#1#2\lthtmlindisplaymathZ{\lthtmlTightVBoxA{#1}{\hbox\bgroup#2\egroup}\lthtmlTightVBoxZ}
    \def\lthtmlinlineA#1#2\lthtmlinlineZ{\lthtmlTightVBoxA{#1}{\hbox\bgroup#2\egroup}\lthtmlTightVBoxZ}
    \long\def\lthtmldisplayA#1#2\lthtmldisplayZ{\lthtmlTightVBoxA{#1}{#2}\lthtmlTightVBoxZ}
    \long\def\lthtmldisplayB#1#2\lthtmldisplayZ{\\edef\preveqno{(\theequation)}%
        \lthtmlTightVBoxA{#1}{\let\@eqnnum\relax#2}\lthtmlTightVBoxZ}
    \long\def\lthtmlfigureA#1{\let\@savefreelist\@freelist
        \lthtmlTightFBoxA{#1}}
    \long\def\lthtmlfigureZ{
        \lthtmlTightFBoxZ\global\let\@freelist\@savefreelist}
    \long\def\lthtmlpictureA#1{\let\@savefreelist\@freelist
        \lthtmlTightVBoxA{#1}}
    \long\def\lthtmlpictureZ{
        \lthtmlTightVBoxZ\global\let\@freelist\@savefreelist}
\def\lthtmlcheckvsize{\ifdim\ht\sizebox<\vsize 
  \ifdim\wd\sizebox<\hsize\expandafter\hfill\fi \expandafter\vfill
  \else\expandafter\vss\fi}%
\providecommand{\selectlanguage}[1]{}%
\makeatletter \tracingstats = 1 

\begin{document}
\pagestyle{empty}\thispagestyle{empty}\lthtmltypeout{}%
\lthtmltypeout{latex2htmlLength hsize=\the\hsize}\lthtmltypeout{}%
\lthtmltypeout{latex2htmlLength vsize=\the\vsize}\lthtmltypeout{}%
\lthtmltypeout{latex2htmlLength hoffset=\the\hoffset}\lthtmltypeout{}%
\lthtmltypeout{latex2htmlLength voffset=\the\voffset}\lthtmltypeout{}%
\lthtmltypeout{latex2htmlLength topmargin=\the\topmargin}\lthtmltypeout{}%
\lthtmltypeout{latex2htmlLength topskip=\the\topskip}\lthtmltypeout{}%
\lthtmltypeout{latex2htmlLength headheight=\the\headheight}\lthtmltypeout{}%
\lthtmltypeout{latex2htmlLength headsep=\the\headsep}\lthtmltypeout{}%
\lthtmltypeout{latex2htmlLength parskip=\the\parskip}\lthtmltypeout{}%
\lthtmltypeout{latex2htmlLength oddsidemargin=\the\oddsidemargin}\lthtmltypeout{}%
\makeatletter
\if@twoside\lthtmltypeout{latex2htmlLength evensidemargin=\the\evensidemargin}%
\else\lthtmltypeout{latex2htmlLength evensidemargin=\the\oddsidemargin}\fi%
\lthtmltypeout{}%
\makeatother
\setcounter{page}{1}
\onecolumn

% !!! IMAGES START HERE !!!

{\newpage\clearpage
\lthtmlpictureA{tex2html_wrap610}%
%
\lthtmlpictureZ
\lthtmlcheckvsize\clearpage}

\stepcounter{section}
\stepcounter{subsection}
\stepcounter{subsection}
\stepcounter{subsection}
\stepcounter{subsubsection}
\stepcounter{subsubsection}
\stepcounter{subsubsection}
\stepcounter{subsubsection}
\stepcounter{subsubsection}
\stepcounter{section}
\stepcounter{subsection}
\stepcounter{subsubsection}
\stepcounter{subsubsection}
\stepcounter{subsubsection}
{\newpage\clearpage
\lthtmlinlinemathA{tex2html_wrap_inline476}%
$\ $%
\lthtmlindisplaymathZ
\lthtmlcheckvsize\clearpage}

\stepcounter{subsubsection}
\stepcounter{subsection}
\stepcounter{subsection}
\stepcounter{subsection}
\stepcounter{subsubsection}
\stepcounter{subsubsection}
\stepcounter{section}
\stepcounter{subsection}
\stepcounter{section}
\stepcounter{subsection}
\stepcounter{section}
\stepcounter{subsection}
\stepcounter{subsection}

\end{document}

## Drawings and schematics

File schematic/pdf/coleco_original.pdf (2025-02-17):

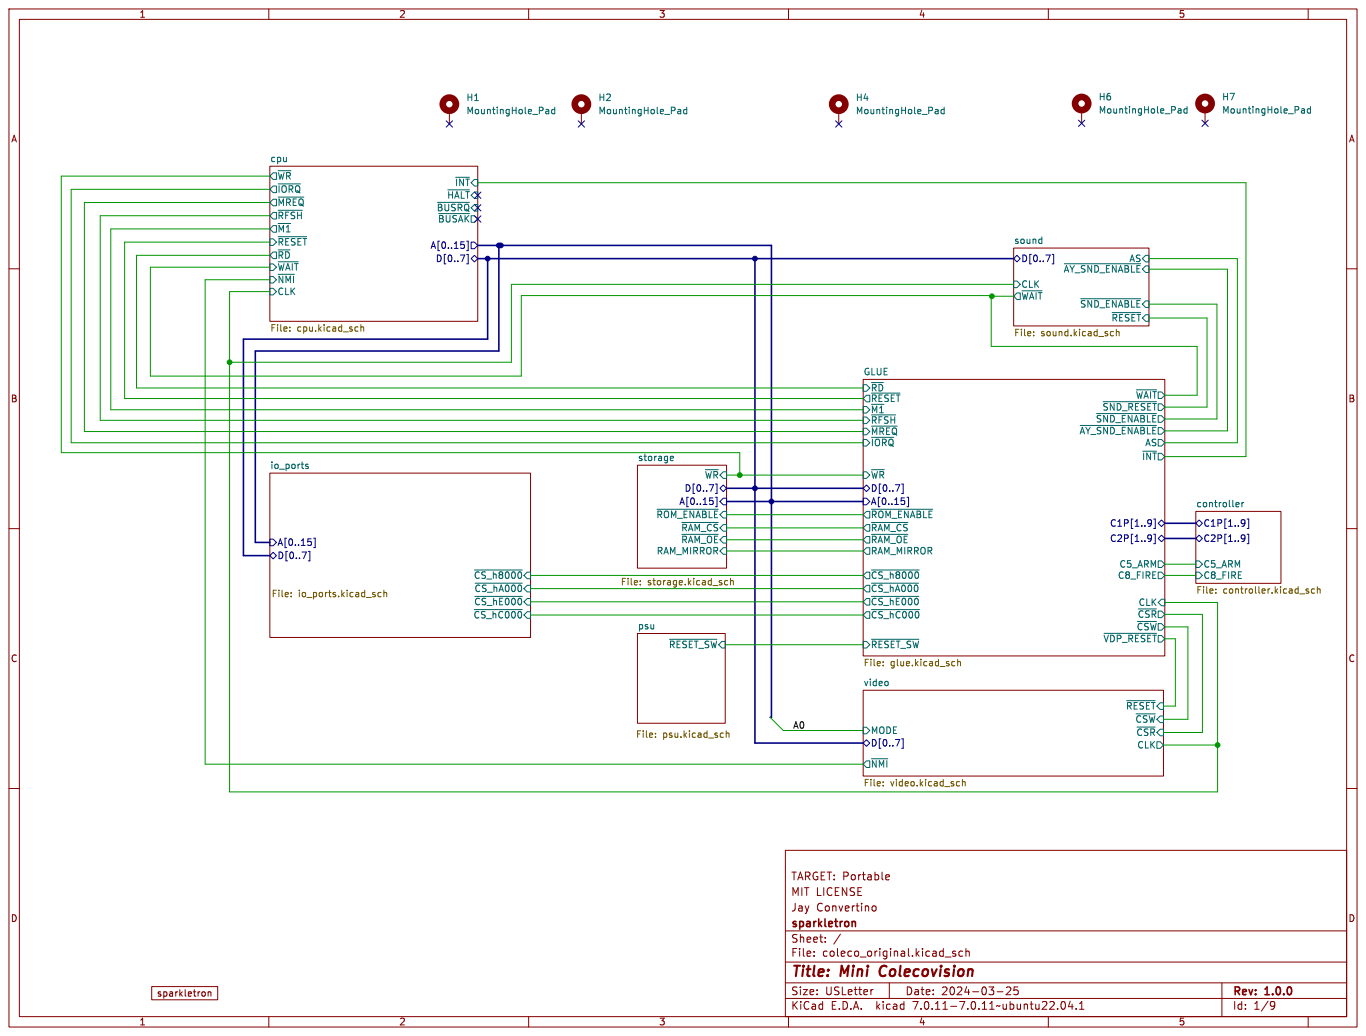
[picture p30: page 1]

sound File: sound.kicad_sch ~{WR}

Id: 1/9 Title: Mini Colecovision

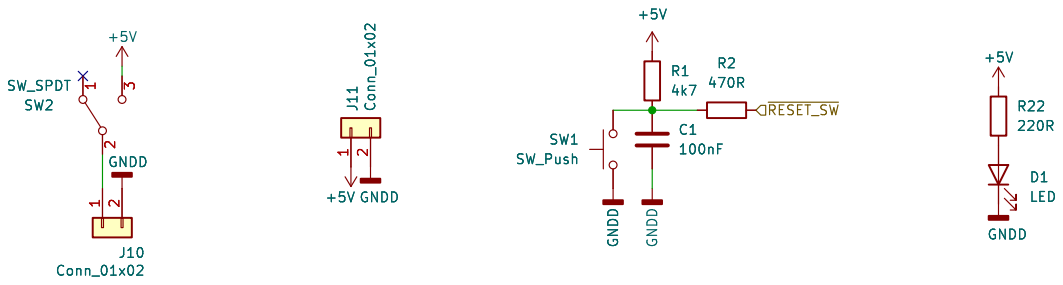
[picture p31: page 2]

LED GNDD GNDD GNDD

TARGET: Portable Jay Convertino MIT sparkletron | LICENSE

E.D.A. kicad 7.0.11-7.0.11~ubuntu22.04.1 Size: USLetter Rev: 1.0.0 | D Date: 2024-03-25 KiCad

File: psu.kicad_sch Sheet: /psu/
Id: 2/9 Title: Mini Colecovision

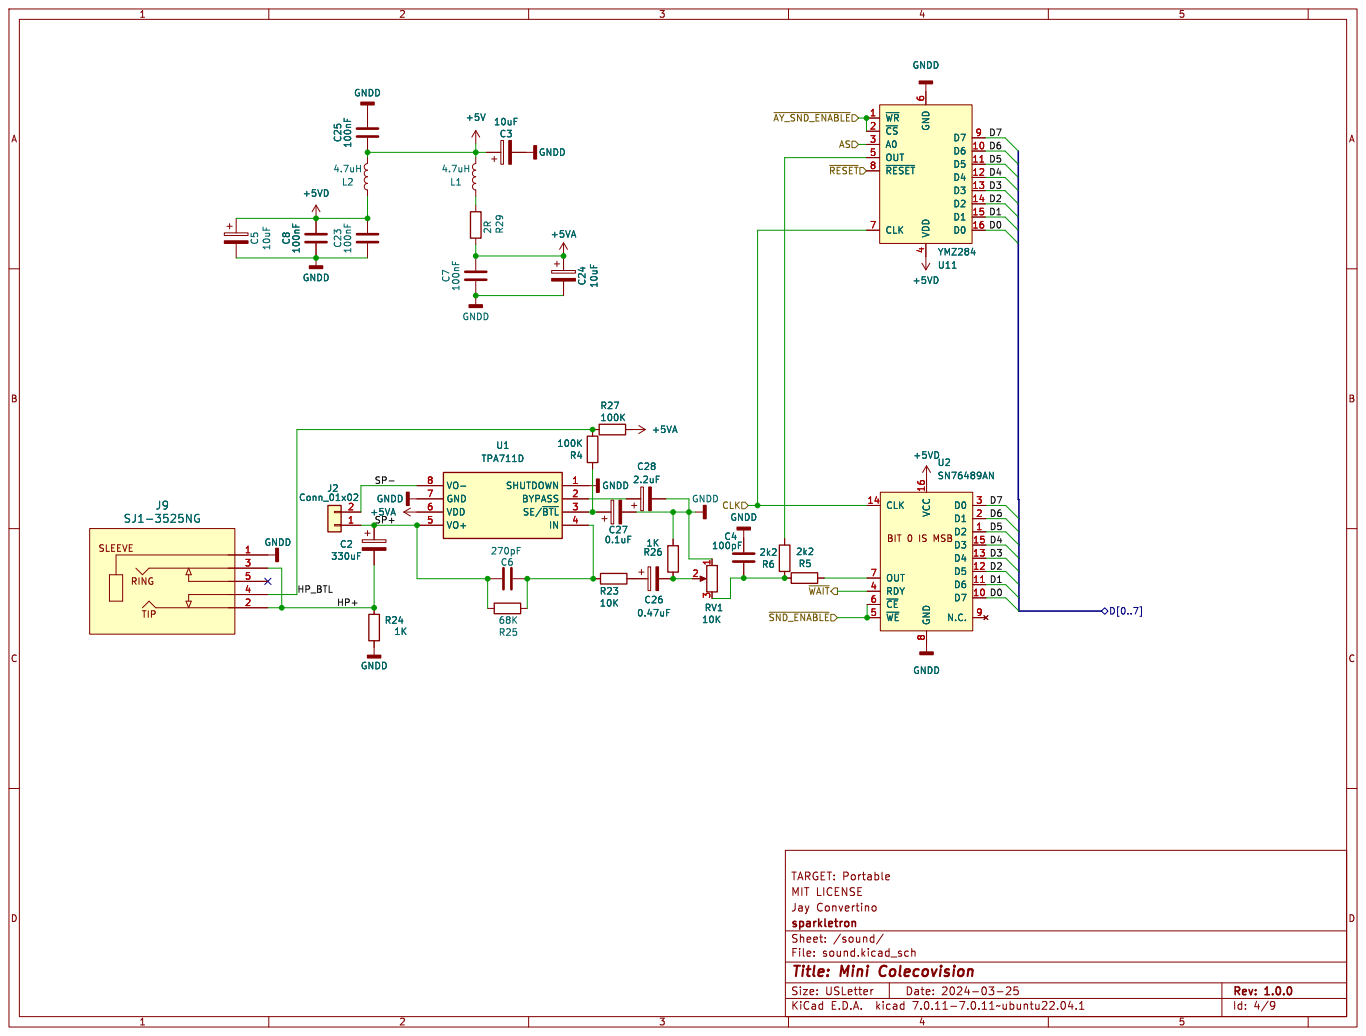
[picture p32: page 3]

6 CLK 7 ~{RESET} 8 D7 9 U11 YMZ284 GNDD GNDD

6 CLK 7 ~{RESET} 8 D7 9 GNDD GNDD

File: sound.kicad_sch Sheet: /sound/ sparkletron

Id: 4/9 Title: Mini Colecovision

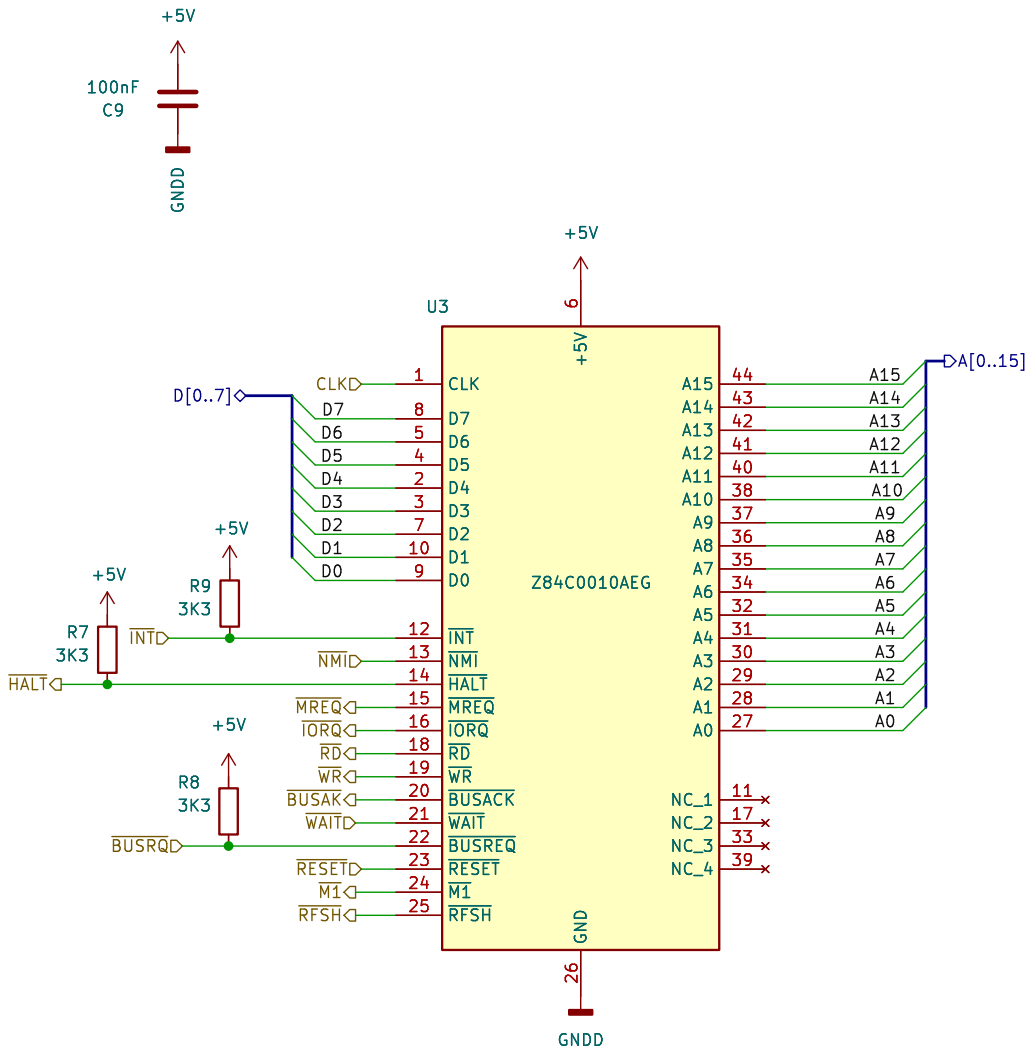
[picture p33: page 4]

sparkletron
File: cpu.kicad_sch Sheet: /cpu/
Id: 5/9 Title: Mini Colecovision

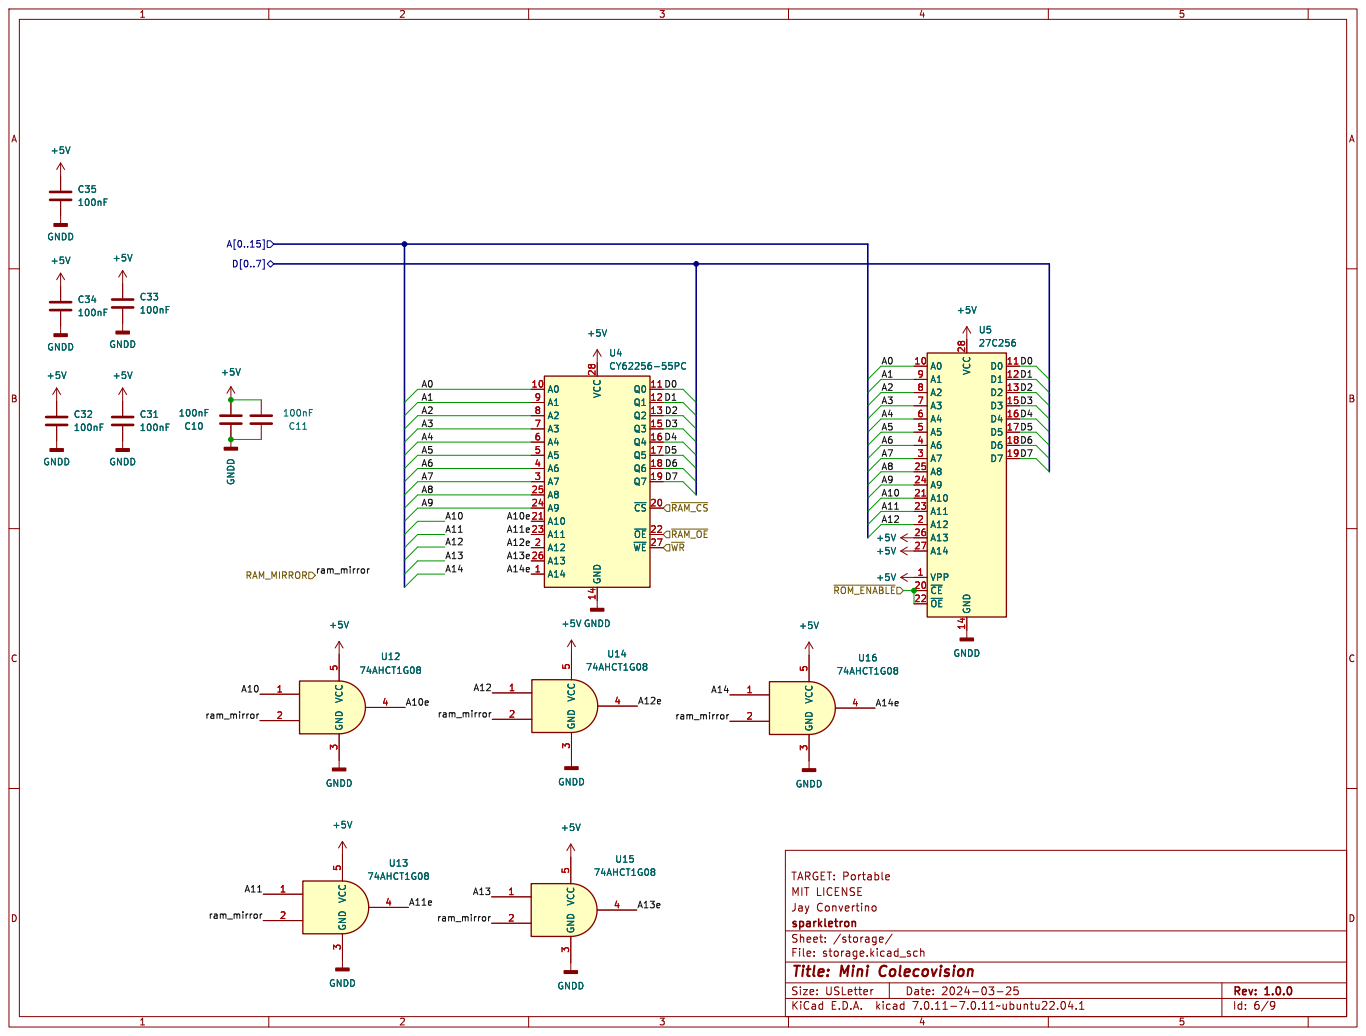
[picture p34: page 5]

sparkletron
File: storage.kicad_sch Sheet: /storage/
Id: 6/9 Title: Mini Colecovision

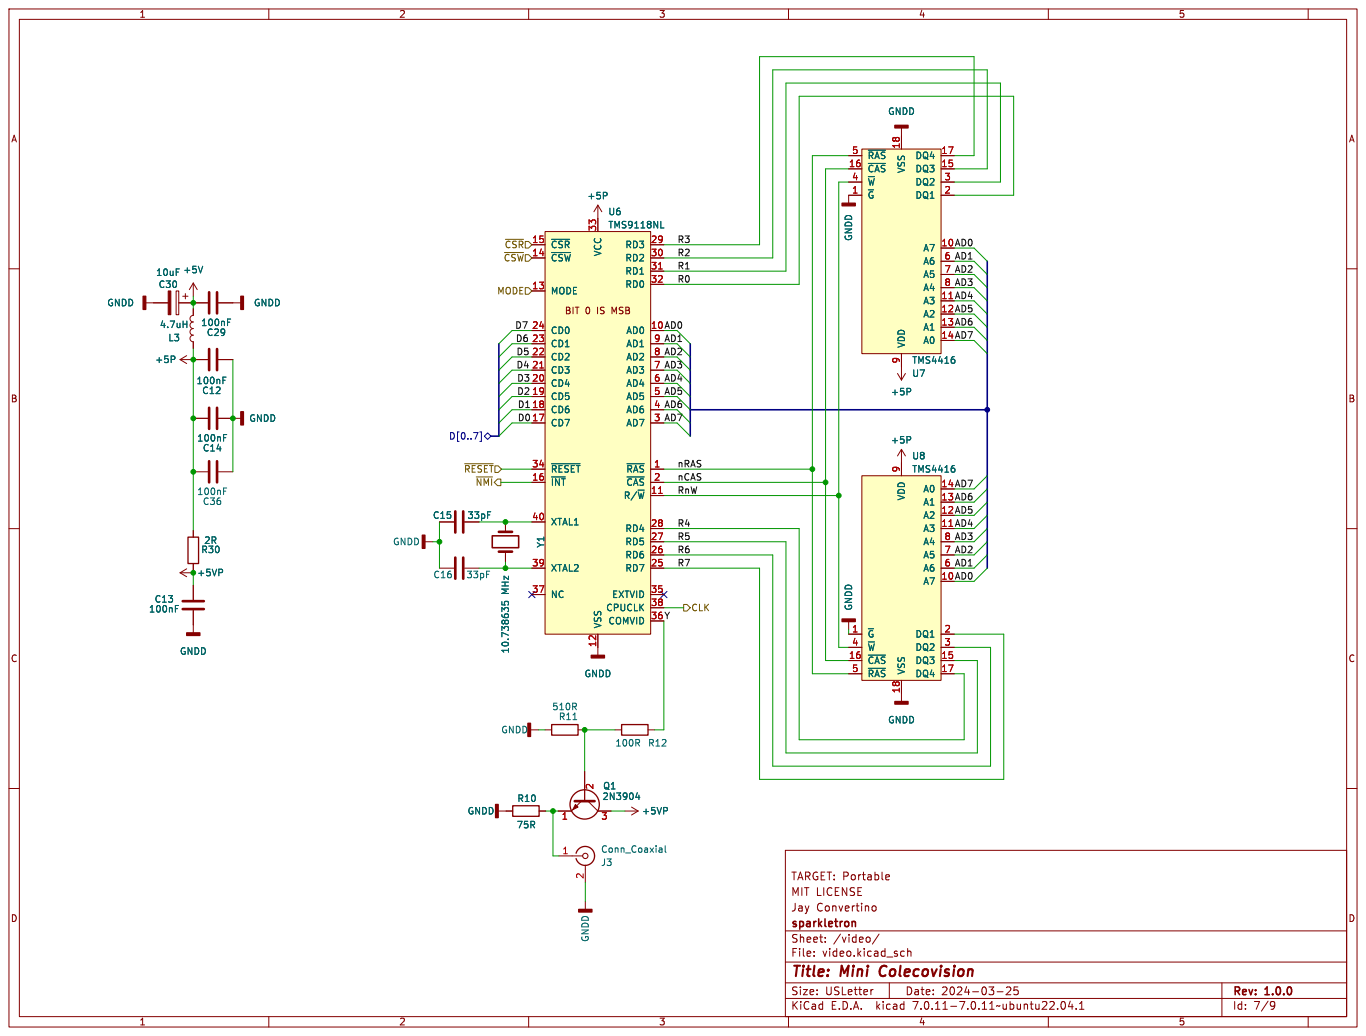
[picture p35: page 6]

File: video.kicad_sch Sheet: /video/ sparkletron

Id: 7/9 Title: Mini Colecovision

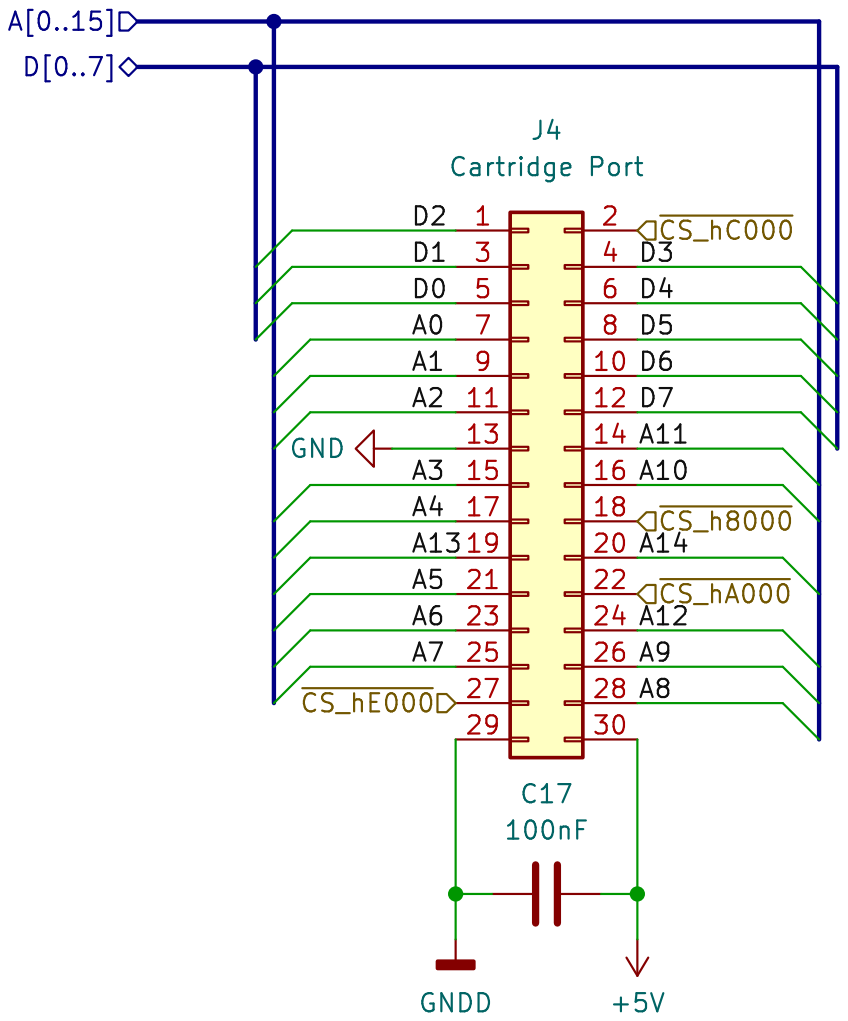
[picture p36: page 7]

Jay Convertino MIT sparkletron | LICENSE

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

File: io_ports.kicad_sch Sheet: /io_ports/
Id: 9/9 Title: Mini Colecovision

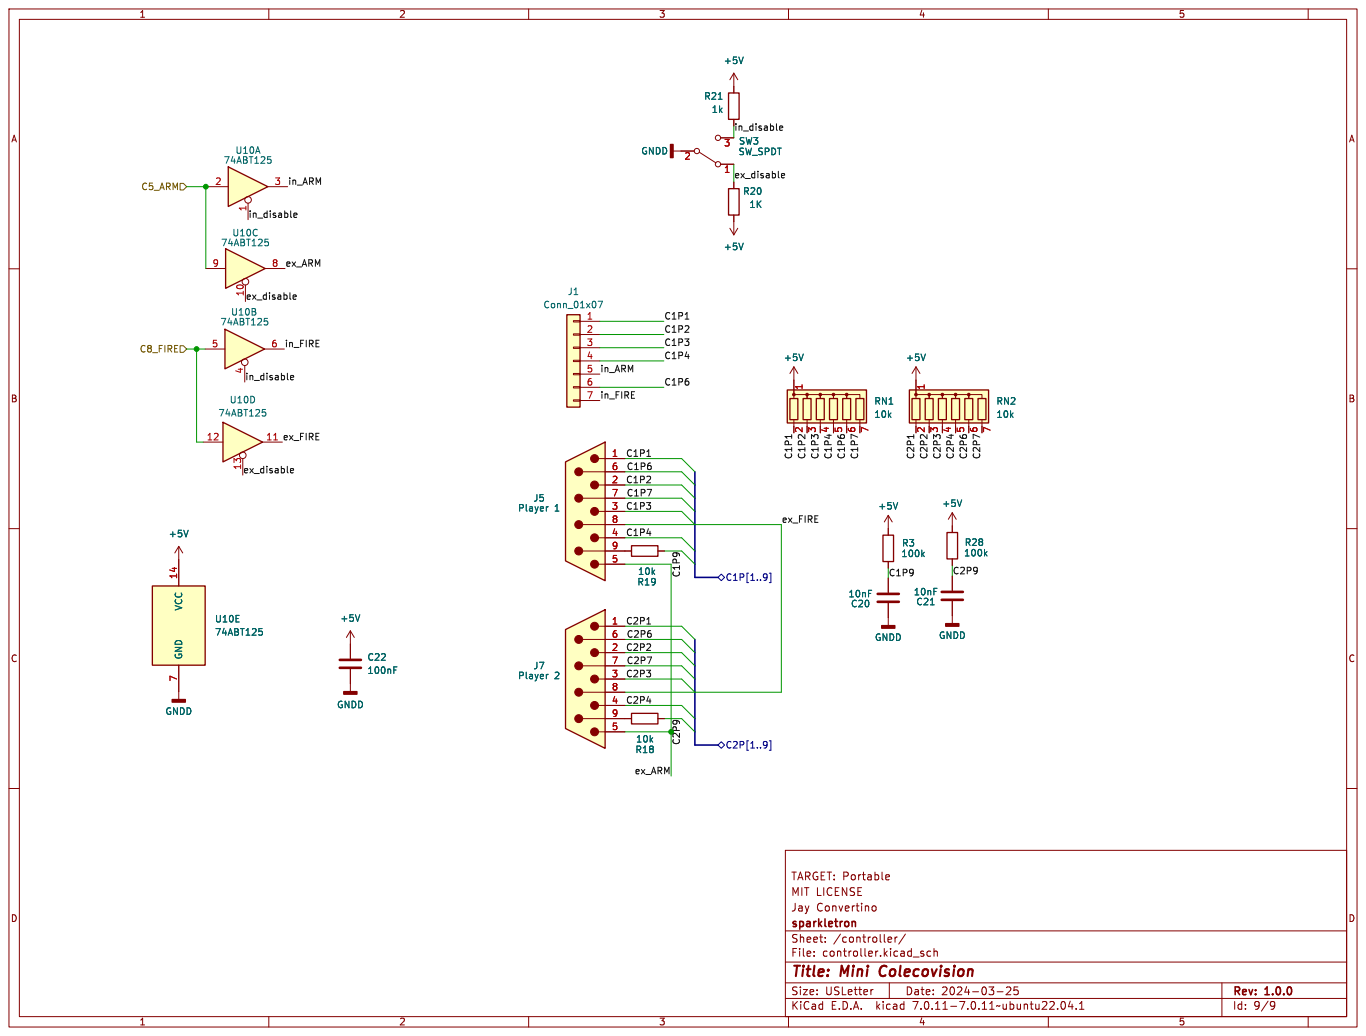
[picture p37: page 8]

File: controller.kicad_sch Sheet: /controller/ sparkletron

Id: 9/9 Title: Mini Colecovision

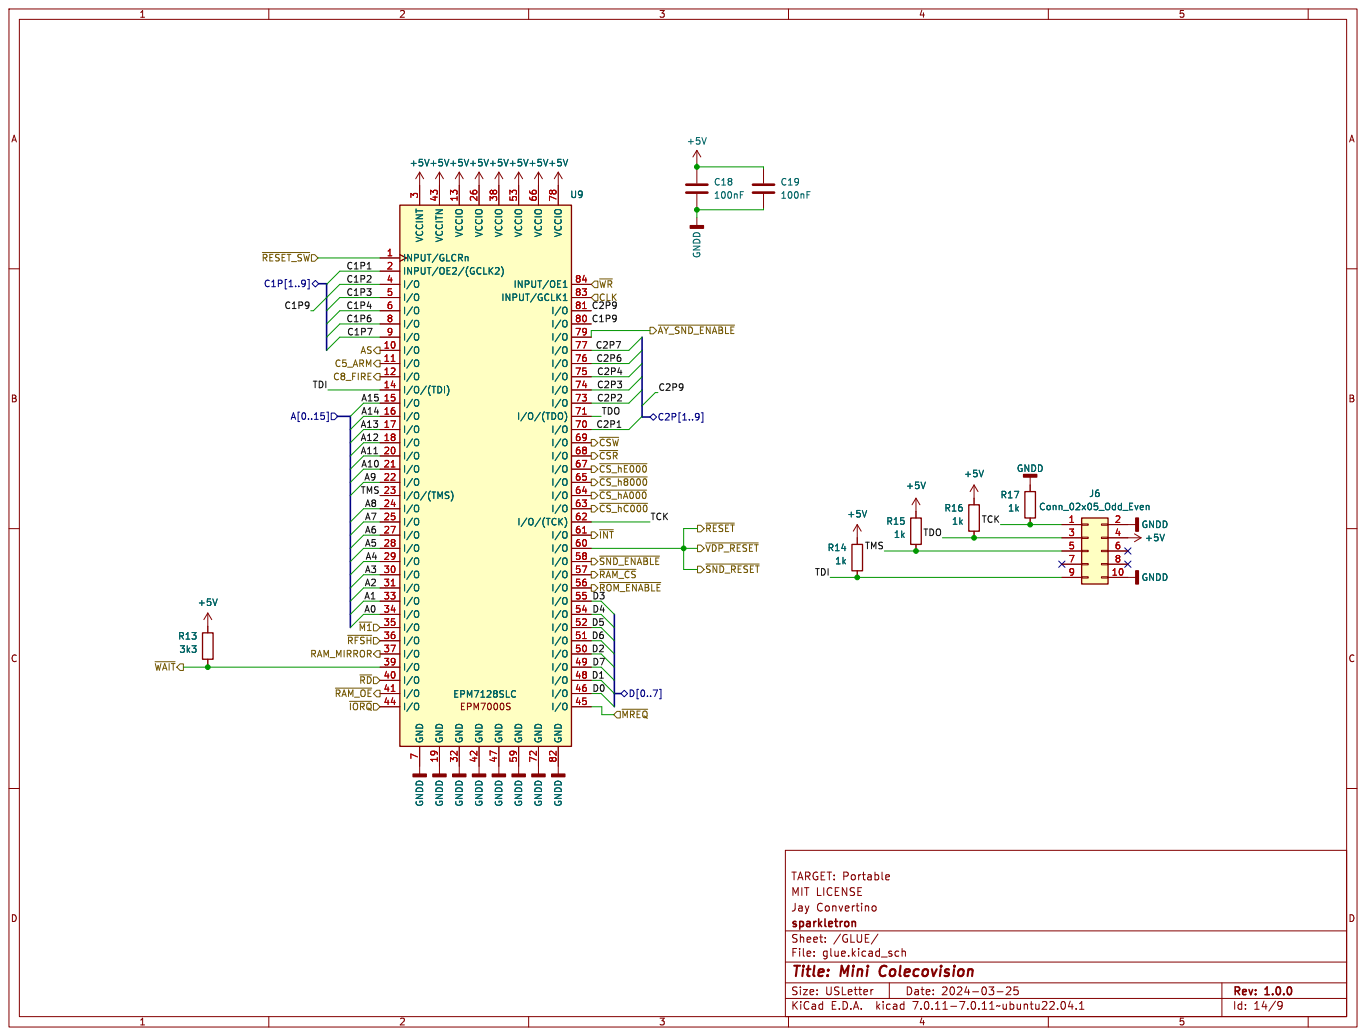
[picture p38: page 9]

File: glue.kicad_sch Sheet: /GLUE/ sparkletron

Id: 14/9 Title: Mini Colecovision

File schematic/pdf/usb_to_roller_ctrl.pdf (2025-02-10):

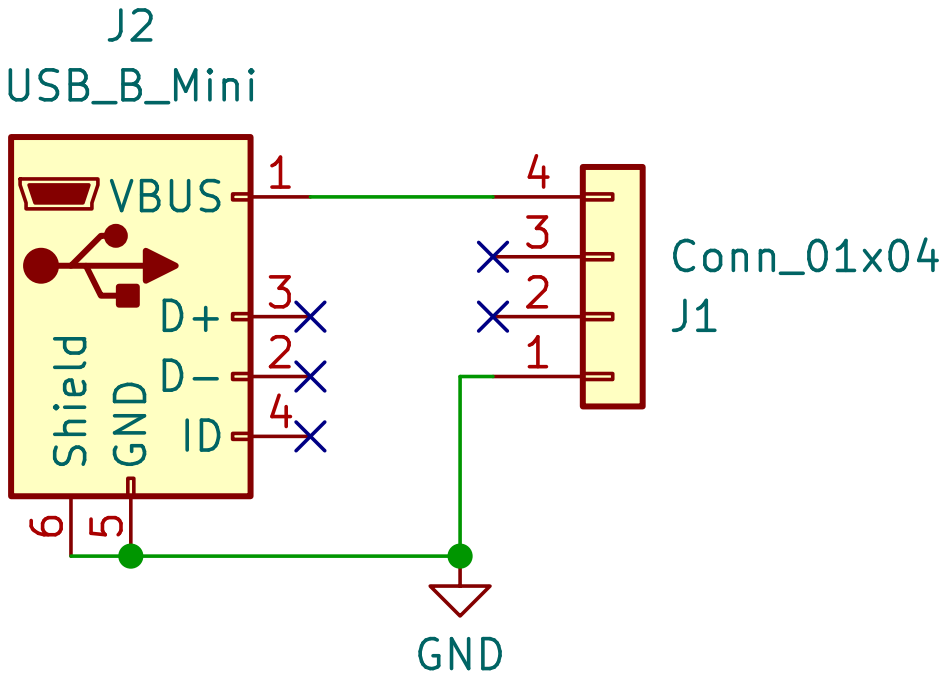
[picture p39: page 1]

Id: 1/1 Title: File: usb_to_roller_ctrl.kicad_sch Sheet: /

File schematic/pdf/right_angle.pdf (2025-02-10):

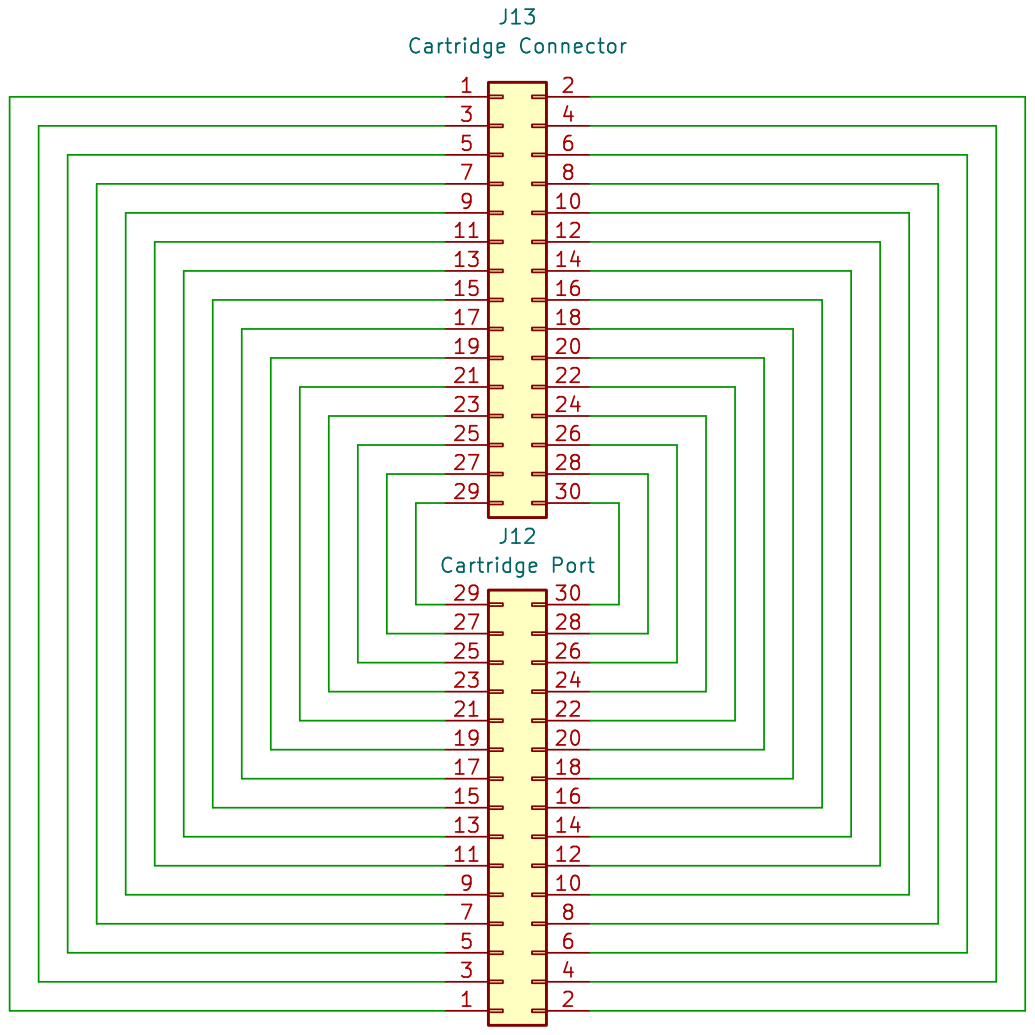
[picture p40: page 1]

11 | 12
13 | 14
15 | 16
17 | 18

21 | 22
23 | 24
25 | 26
27 | 28

Id: 1/1 Title: File: right_angle.kicad_sch Sheet: / 1

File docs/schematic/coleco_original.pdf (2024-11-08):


sound File: sound.kicad_sch ~{WR}

Id: 1/9 Title: Mini Colecovision


LED GNDD GNDD GNDD

TARGET: Portable Jay Convertino MIT sparkletron | LICENSE

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

File: psu.kicad_sch Sheet: /psu/
Id: 2/9 Title: Mini Colecovision

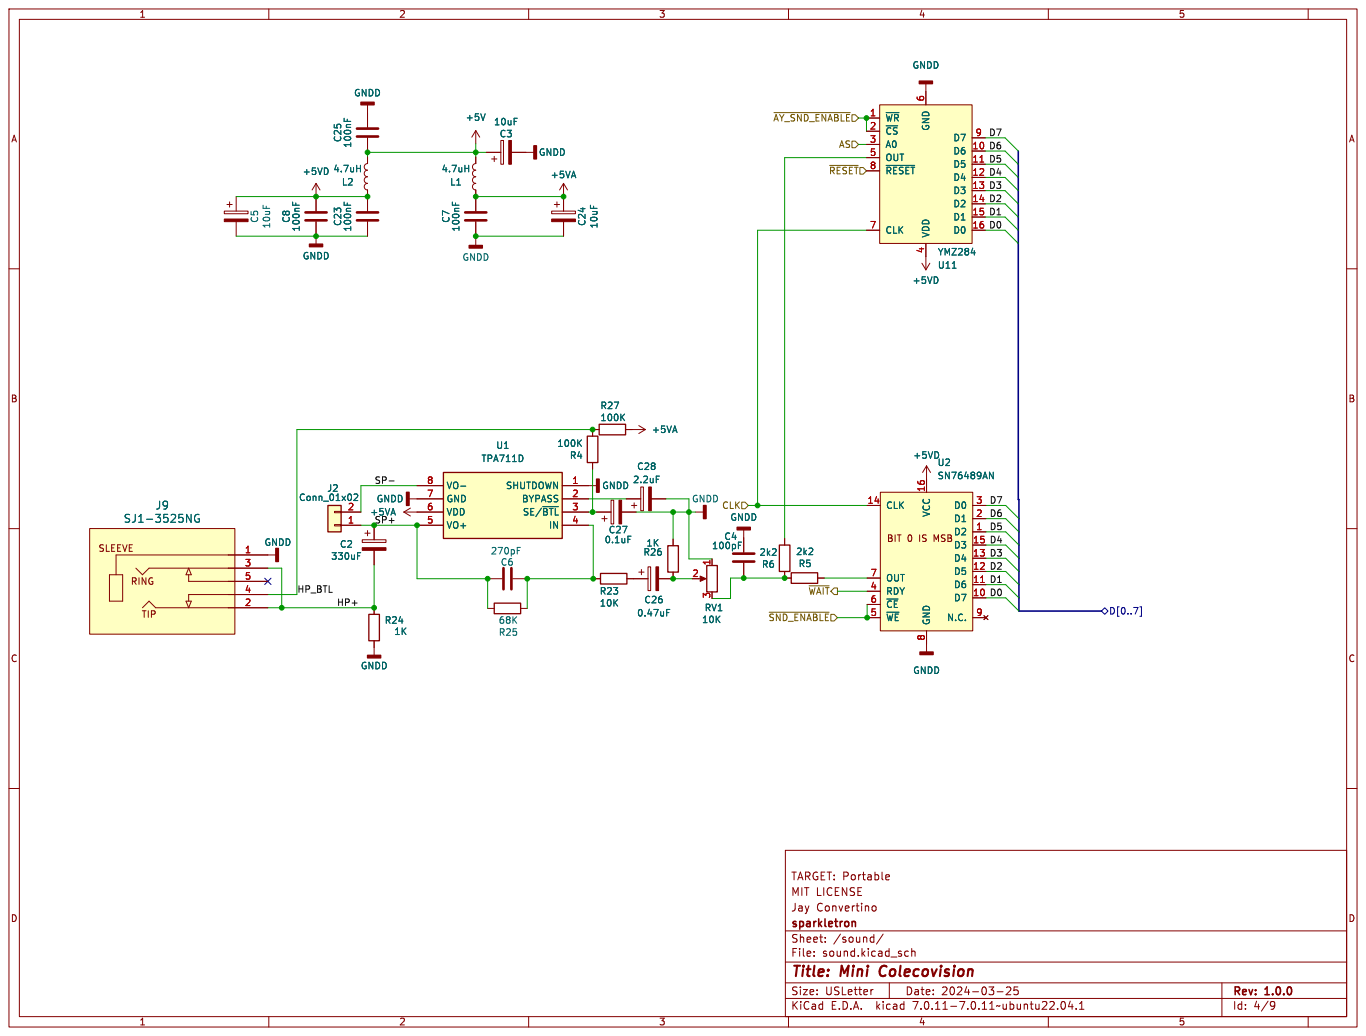
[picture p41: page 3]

File: sound.kicad_sch Sheet: /sound/ sparkletron

Id: 4/9 Title: Mini Colecovision


sparkletron
File: cpu.kicad_sch Sheet: /cpu/
Id: 5/9 Title: Mini Colecovision


sparkletron
File: storage.kicad_sch Sheet: /storage/
Id: 6/9 Title: Mini Colecovision


File: video.kicad_sch Sheet: /video/ sparkletron

Id: 7/9 Title: Mini Colecovision


Jay Convertino MIT sparkletron | LICENSE

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

File: io_ports.kicad_sch Sheet: /io_ports/
Id: 9/9 Title: Mini Colecovision


File: controller.kicad_sch Sheet: /controller/ sparkletron

Id: 9/9 Title: Mini Colecovision


File: glue.kicad_sch Sheet: /GLUE/ sparkletron

Id: 14/9 Title: Mini Colecovision

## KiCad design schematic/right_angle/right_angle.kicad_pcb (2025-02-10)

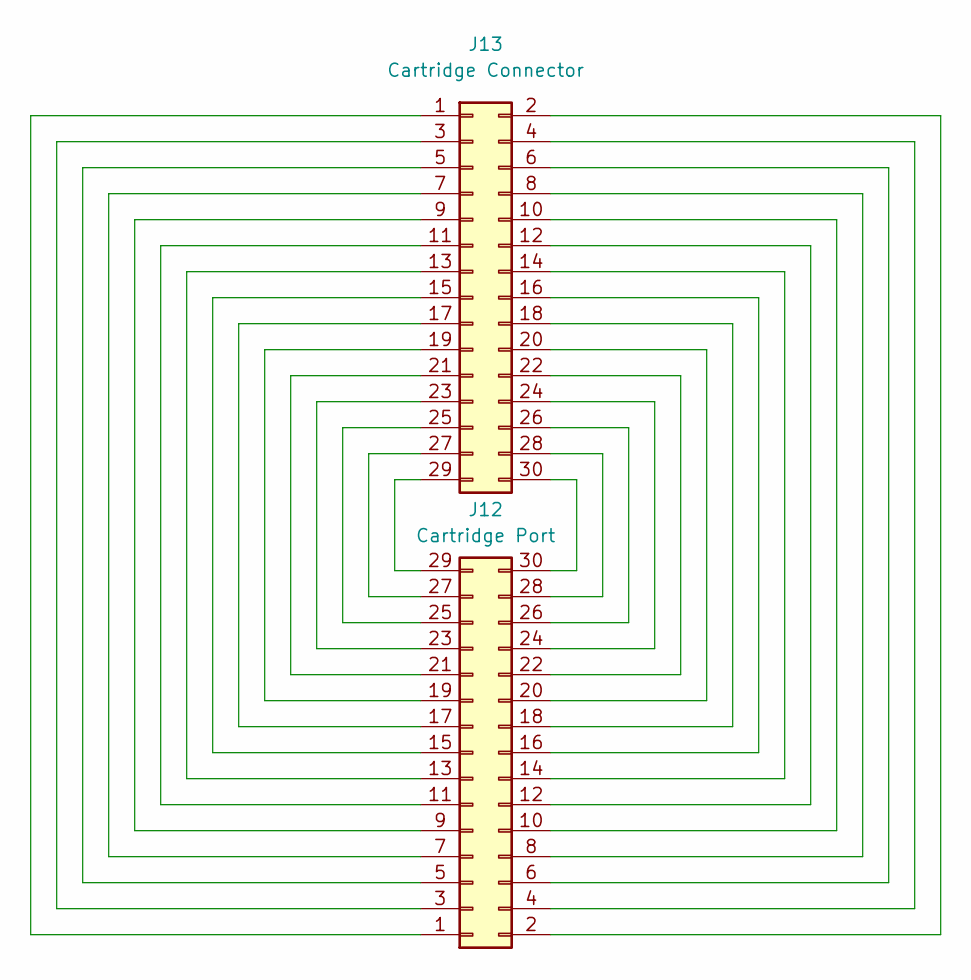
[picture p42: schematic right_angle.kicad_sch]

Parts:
J12: Cartridge Port; 55308412_coleco
J13: Cartridge Connector; Colecovision_Cartridge

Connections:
unnamed: J12.1, J13.1
unnamed: J12.2, J13.2
unnamed: J12.3, J13.3
unnamed: J12.4, J13.4
unnamed: J12.5, J13.5
unnamed: J12.6, J13.6
unnamed: J12.7, J13.7
unnamed: J12.8, J13.8
unnamed: J12.9, J13.9
unnamed: J12.10, J13.10
unnamed: J12.11, J13.11
unnamed: J12.12, J13.12
unnamed: J12.13, J13.13
unnamed: J12.14, J13.14
unnamed: J12.15, J13.15
unnamed: J12.16, J13.16
unnamed: J12.17, J13.17
unnamed: J12.18, J13.18
unnamed: J12.19, J13.19
unnamed: J12.20, J13.20
unnamed: J12.21, J13.21
unnamed: J12.22, J13.22
unnamed: J12.23, J13.23
unnamed: J12.24, J13.24
unnamed: J12.25, J13.25
unnamed: J12.26, J13.26
unnamed: J12.27, J13.27
unnamed: J12.28, J13.28
unnamed: J12.29, J13.29
unnamed: J12.30, J13.30

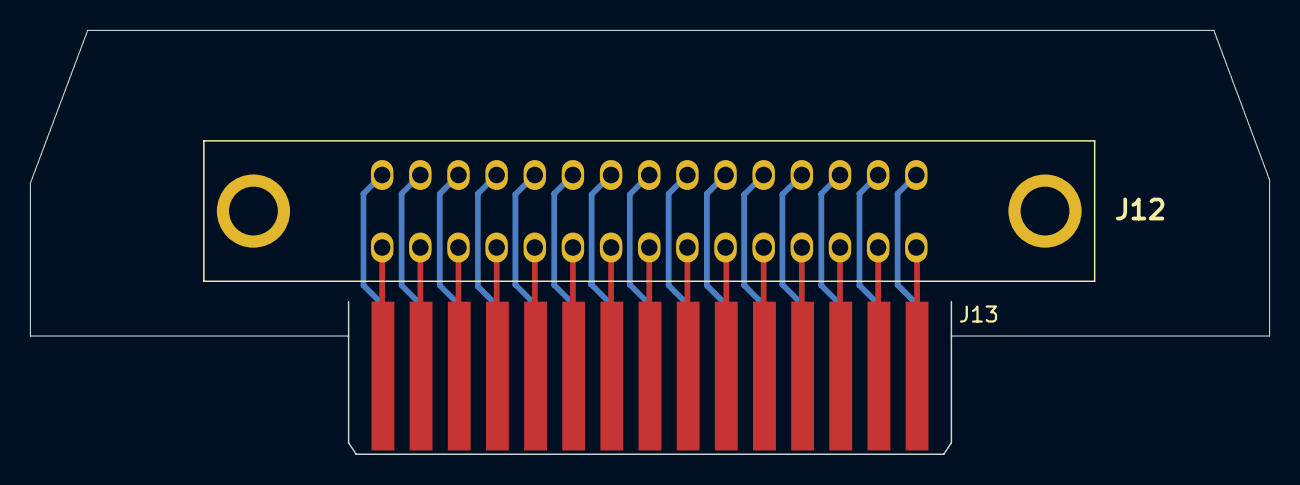
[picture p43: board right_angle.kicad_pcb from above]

Board: 2 copper layers, 82.5 x 28.2 mm, 3 parts (0 on the bottom side), 30 nets.

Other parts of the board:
S1: sparkletron

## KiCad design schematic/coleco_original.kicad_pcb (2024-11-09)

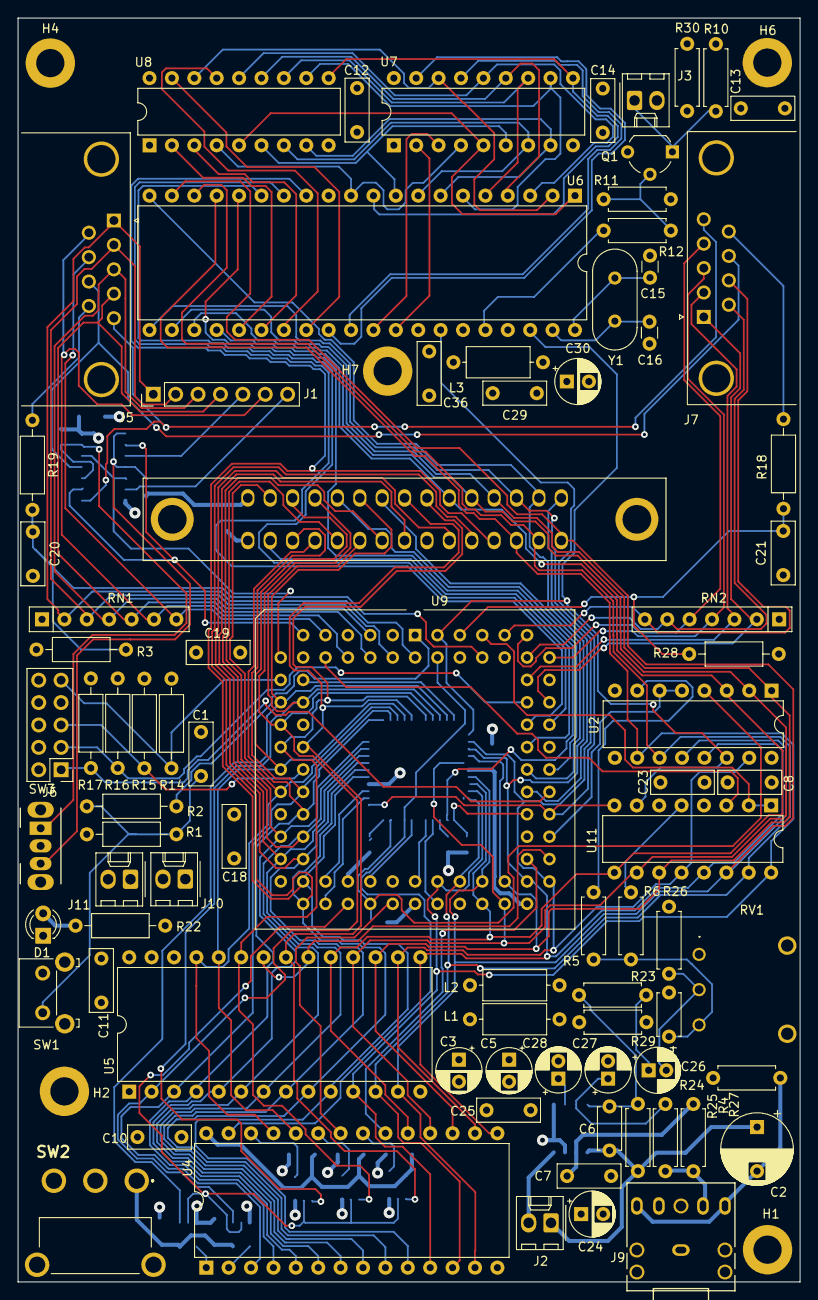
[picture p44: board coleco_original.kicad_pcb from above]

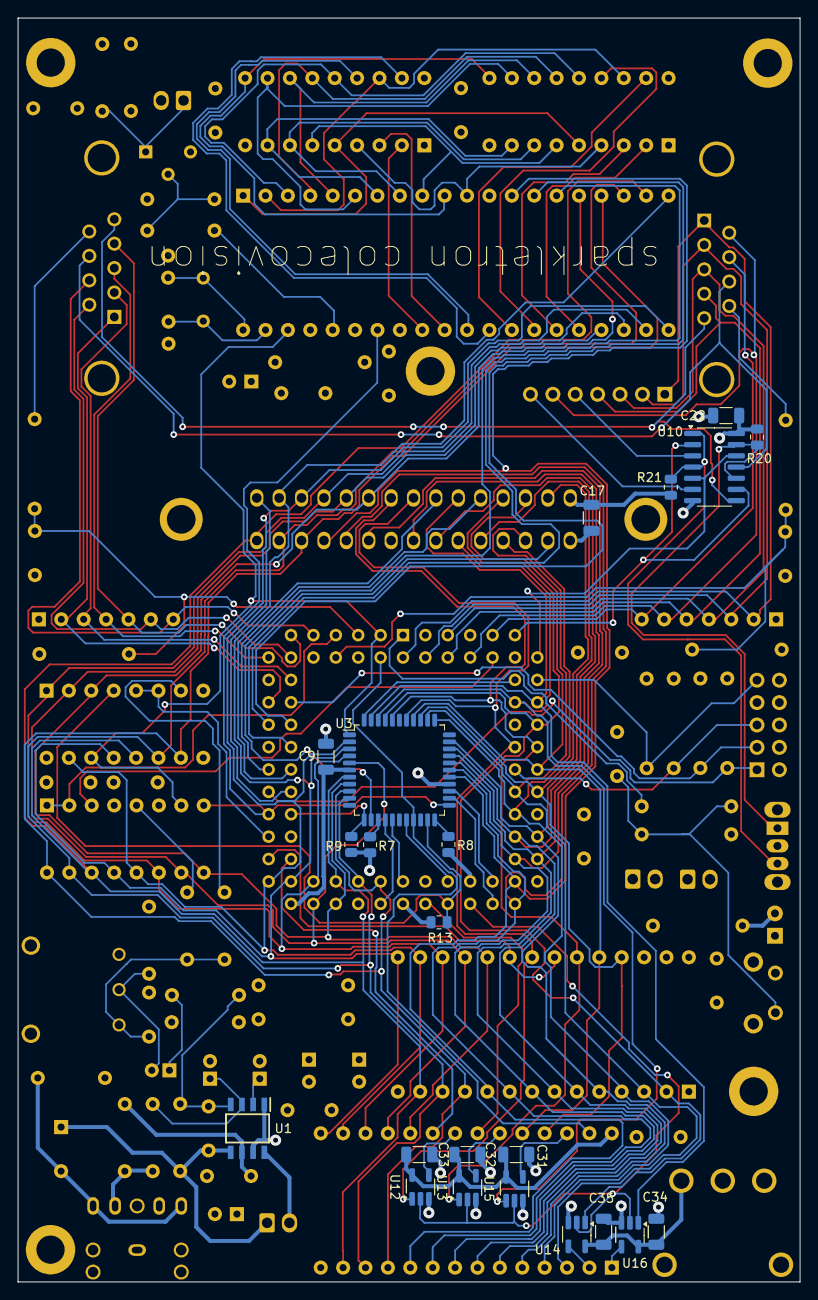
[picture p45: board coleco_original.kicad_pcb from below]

Board: 4 copper layers, 88.7 x 143.4 mm, 110 parts (22 on the bottom side), 130 nets.

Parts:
C1, C7, C8, C10, C11, C12, C13, C14, C18, C19, C23, C25, C29, C36: 100nF; C_Disc_D7.0mm_W2.5mm_P5.00mm
C2: 330uF; CP_Radial_D8.0mm_P5.00mm
C3, C5, C24, C30: 10uF; CP_Radial_D5.0mm_P2.50mm
C4: 100pF; C_Disc_D4.7mm_W2.5mm_P5.00mm
C6: 270pF; C_Disc_D4.7mm_W2.5mm_P5.00mm
C9, C17, C22, C31, C32, C33, C34, C35: 100nF; C_1206_3216Metric
C15, C16: 33pF; C_Disc_D3.0mm_W1.6mm_P2.50mm
C20, C21: 10nF; C_Disc_D7.0mm_W2.5mm_P5.00mm
C26: 0.47uF; CP_Radial_D5.0mm_P2.00mm
C27: 0.1uF; CP_Radial_D5.0mm_P2.00mm
C28: 2.2uF; CP_Radial_D5.0mm_P2.00mm
D1: LED; LED_D3.0mm
H1, H2, H4, H6, H7: MountingHole_Pad; MountingHole_3.2mm_M3_DIN965_Pad
J1: Conn_01x07; PinHeader_1x07_P2.54mm_Vertical
J2, J10, J11: Conn_01x02; Molex_KK-254_AE-6410-02A_1x02_P2.54mm_Vertical
J3: Conn_Coaxial; Molex_KK-254_AE-6410-02A_1x02_P2.54mm_Vertical
J4: Cartridge Port; 55308412_coleco
J5: Player 1; DSUB-9_Male_Horizontal_P2.77x2.84mm_EdgePinOffset7.70mm_Hou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
J6: Conn_02x05_Odd_Even; PinHeader_2x05_P2.54mm_Vertical
J7: Player 2; DSUB-9_Male_Horizontal_P2.77x2.84mm_EdgePinOffset7.70mm_Hou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
J9: SJ1-3525NG; SJ1-3525NG_CUD
L1, L2, L3: 4.7uH; L_Axial_L7.0mm_D3.3mm_P10.16mm_Horizontal_Fastron_MICC
Q1: 2N3904; TO-92_Wide
R1: 4k7; R_Axial_DIN0207_L6.3mm_D2.5mm_P10.16mm_Horizontal
R2: 470R; R_Axial_DIN0207_L6.3mm_D2.5mm_P10.16mm_Horizontal
R3, R28: 100k; R_Axial_DIN0207_L6.3mm_D2.5mm_P10.16mm_Horizontal
R4, R27: 100K; R_Axial_DIN0207_L6.3mm_D2.5mm_P7.62mm_Horizontal
R5, R6: 2k2; R_Axial_DIN0207_L6.3mm_D2.5mm_P7.62mm_Horizontal
R7, R8, R9: 3K3; R_0805_2012Metric
R10: 75R; R_Axial_DIN0207_L6.3mm_D2.5mm_P7.62mm_Horizontal
R11: 510R; R_Axial_DIN0207_L6.3mm_D2.5mm_P7.62mm_Horizontal
R12: 100R; R_Axial_DIN0207_L6.3mm_D2.5mm_P7.62mm_Horizontal
R13: 3k3; R_0805_2012Metric
R14, R15, R16, R17: 1k; R_Axial_DIN0207_L6.3mm_D2.5mm_P10.16mm_Horizontal
R18, R19: 10k; R_Axial_DIN0207_L6.3mm_D2.5mm_P10.16mm_Horizontal
R20: 1K; R_0805_2012Metric
R21: 1k; R_0805_2012Metric
R22: 220R; R_Axial_DIN0207_L6.3mm_D2.5mm_P10.16mm_Horizontal
R23: 10K; R_Axial_DIN0207_L6.3mm_D2.5mm_P7.62mm_Horizontal
R24, R26: 1K; R_Axial_DIN0207_L6.3mm_D2.5mm_P7.62mm_Horizontal
R25: 68K; R_Axial_DIN0207_L6.3mm_D2.5mm_P7.62mm_Horizontal
R29, R30: 2R; R_Axial_DIN0207_L6.3mm_D2.5mm_P7.62mm_Horizontal
RN1, RN2: 10k; R_Array_SIP7
RV1: 10K; RV100F304K1B50K
S1: sparkletron
SW1: SW_Push; SW_Tactile_SKHH_Angled
SW2: SW_SPDT; 1101M2S3ABE2
SW3: SW_SPDT; SW_CuK_OS102011MA1QN1_SPDT_Angled
U1: TPA711D; SOIC127P600X175-8N
U2: SN76489AN; DIP-16_W7.62mm
U3: Z84C0010AEG; LQFP-44_10x10mm_P0.8mm
U4: CY62256-55PC; DIP-28_W15.24mm
U5: 27C256; DIP-28_W15.24mm
U6: TMS9118NL; DIP-40_W15.24mm
U7, U8: TMS4416; DIP-18_W7.62mm
U9: EPM7128SLC; PLCC-84_THT-Socket
U10: 74ABT125; SOIC-14_3.9x8.7mm_P1.27mm
U11: YMZ284; DIP-16_W7.62mm
U12, U13, U14, U15, U16: 74AHCT1G08; SOT-23-5_HandSoldering
Y1: 10.738635 MHz; Crystal_HC49-4H_Vertical

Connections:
+5P: C12.1, C14.1, C36.1, L3.1, R30.2, U6.33 (VCC), U7.9 (VDD), U8.9 (VDD)
+5V: C3.1, C9.1, C10.1, C11.1, C17.1, C18.1, C19.1, C22.1, C25.2, C29.1, C30.1, C31.1, C32.1, C33.1, C34.1, C35.1, J4.30, J6.4, J11.1, L1.2, L2.2, L3.2, R1.1, R3.2, R7.2, R8.1, R9.2, R13.2, R14.2, R15.2, R16.2, R20.1, R21.2, R22.1, R28.2, RN1.1 (common), RN2.1 (common), SW2.3 (C), U3.6 (+5V), U4.28 (VCC), U5.1 (VPP), U5.26 (A13), U5.27 (A14), U5.28 (VCC), U9.3 (VCCINT), U9.13 (VCCIO), U9.26 (VCCIO), U9.38 (VCCIO), U9.43 (VCCITN), U9.53 (VCCIO), U9.66 (VCCIO), U9.78 (VCCIO), U10.14 (VCC), U12.5 (VCC), U13.5 (VCC), U14.5 (VCC), U15.5 (VCC), U16.5 (VCC)
+5VA: C7.1, C24.1, R27.2, R29.2, U1.6 (VDD)
+5VD: C5.1, C8.1, C23.1, L2.1, U2.16 (VCC), U11.4 (VDD)
+5VP: C13.1, Q1.3 (C), R30.1
/GLUE/A0: J4.7, U3.27 (A0), U4.10 (A0), U5.10 (A0), U6.13 (MODE), U9.34 (I/O)
/GLUE/A1: J4.9, U3.28 (A1), U4.9 (A1), U5.9 (A1), U9.33 (I/O)
/GLUE/A2: J4.11, U3.29 (A2), U4.8 (A2), U5.8 (A2), U9.31 (I/O)
/GLUE/A3: J4.15, U3.30 (A3), U4.7 (A3), U5.7 (A3), U9.30 (I/O)
/GLUE/A4: J4.17, U3.31 (A4), U4.6 (A4), U5.6 (A4), U9.29 (I/O)
/GLUE/A5: J4.21, U3.32 (A5), U4.5 (A5), U5.5 (A5), U9.28 (I/O)
/GLUE/A6: J4.23, U3.34 (A6), U4.4 (A6), U5.4 (A6), U9.27 (I/O)
/GLUE/A7: J4.25, U3.35 (A7), U4.3 (A7), U5.3 (A7), U9.25 (I/O)
/GLUE/A8: J4.28, U3.36 (A8), U4.25 (A8), U5.25 (A8), U9.24 (I/O)
/GLUE/A9: J4.26, U3.37 (A9), U4.24 (A9), U5.24 (A9), U9.22 (I/O)
/GLUE/A10: J4.16, U3.38 (A10), U5.21 (A10), U9.21 (I/O), U12.1
/GLUE/A11: J4.14, U3.40 (A11), U5.23 (A11), U9.20 (I/O), U13.1
/GLUE/A12: J4.24, U3.41 (A12), U5.2 (A12), U9.18 (I/O), U14.1
/GLUE/A13: J4.19, U3.42 (A13), U9.17 (I/O), U15.1
/GLUE/A14: J4.20, U3.43 (A14), U9.16 (I/O), U16.1
/GLUE/A15: U3.44 (A15), U9.15 (I/O)
/GLUE/AS: U9.10 (I/O), U11.3 (A0)
/GLUE/C1P1: J1.1, J5.1, RN1.2 (R1), U9.2 (INPUT/OE2/(GCLK2))
/GLUE/C1P2: J1.2, J5.2, RN1.3 (R2), U9.4 (I/O)
/GLUE/C1P3: J1.3, J5.3, RN1.4 (R3), U9.5 (I/O)
/GLUE/C1P4: J1.4, J5.4, RN1.5 (R4), U9.6 (I/O)
/GLUE/C1P6: J1.6, J5.6, RN1.6 (R5), U9.8 (I/O)
/GLUE/C1P7: J5.7, RN1.7 (R6), U9.9 (I/O)
/GLUE/C1P9: C20.1, R3.1, R19.2, U9.80 (I/O)
/GLUE/C2P1: J7.1, RN2.2 (R1), U9.70 (I/O)
/GLUE/C2P2: J7.2, RN2.3 (R2), U9.73 (I/O)
/GLUE/C2P3: J7.3, RN2.4 (R3), U9.74 (I/O)
/GLUE/C2P4: J7.4, RN2.5 (R4), U9.75 (I/O)
/GLUE/C2P6: J7.6, RN2.6 (R5), U9.76 (I/O)
/GLUE/C2P7: J7.7, RN2.7 (R6), U9.77 (I/O)
/GLUE/C2P9: C21.1, R18.2, R28.1, U9.81 (I/O)
/GLUE/C5_ARM: U9.11 (I/O), U10.2, U10.9
/GLUE/C8_FIRE: U9.12 (I/O), U10.5, U10.12
/GLUE/CLK: U2.14 (CLK), U3.1 (CLK), U6.38 (CPUCLK), U9.83 (INPUT/GCLK1), U11.7 (CLK)
/GLUE/D0: J4.5, U2.10 (D7), U3.9 (D0), U4.11 (Q0), U5.11 (D0), U6.17 (CD7), U9.46 (I/O), U11.16 (D0)
/GLUE/D1: J4.3, U2.11 (D6), U3.10 (D1), U4.12 (Q1), U5.12 (D1), U6.18 (CD6), U9.48 (I/O), U11.15 (D1)
/GLUE/D2: J4.1, U2.12 (D5), U3.7 (D2), U4.13 (Q2), U5.13 (D2), U6.19 (CD5), U9.50 (I/O), U11.14 (D2)
/GLUE/D3: J4.4, U2.13 (D4), U3.3 (D3), U4.15 (Q3), U5.15 (D3), U6.20 (CD4), U9.55 (I/O), U11.13 (D3)
/GLUE/D4: J4.6, U2.15 (D3), U3.2 (D4), U4.16 (Q4), U5.16 (D4), U6.21 (CD3), U9.54 (I/O), U11.12 (D4)
/GLUE/D5: J4.8, U2.1 (D2), U3.4 (D5), U4.17 (Q5), U5.17 (D5), U6.22 (CD2), U9.52 (I/O), U11.11 (D5)
/GLUE/D6: J4.10, U2.2 (D1), U3.5 (D6), U4.18 (Q6), U5.18 (D6), U6.23 (CD1), U9.51 (I/O), U11.10 (D6)
/GLUE/D7: J4.12, U2.3 (D0), U3.8 (D7), U4.19 (Q7), U5.19 (D7), U6.24 (CD0), U9.49 (I/O), U11.9 (D7)
/GLUE/TCK: J6.1, R17.1, U9.62 (I/O/(TCK))
/GLUE/TDI: J6.9, R14.1, U9.14 (I/O/(TDI))
/GLUE/TDO: J6.3, R16.1, U9.71 (I/O/(TDO))
/GLUE/TMS: J6.5, R15.1, U9.23 (I/O/(TMS))
/GLUE/~AY_SND_ENABLE: U9.79 (I/O), U11.1 (~WR), U11.2 (~CS)
/GLUE/~CSR: U6.15 (~CSR), U9.68 (I/O)
/GLUE/~CSW: U6.14 (~CSW), U9.69 (I/O)
/GLUE/~CS_h8000: J4.18, U9.65 (I/O)
/GLUE/~CS_hA000: J4.22, U9.64 (I/O)
/GLUE/~CS_hC000: J4.2, U9.63 (I/O)
/GLUE/~CS_hE000: J4.27, U9.67 (I/O)
/GLUE/~INT: R9.1, U3.12 (~INT), U9.61 (I/O)
/GLUE/~IORQ: U3.16 (~IORQ), U9.44 (I/O)
/GLUE/~M1: U3.24 (~M1), U9.35 (I/O)
/GLUE/~MREQ: U3.15 (~MREQ), U9.45 (I/O)
/GLUE/~RAM_CS: U4.20 (~CS), U9.57 (I/O)
/GLUE/~RAM_OE: U4.22 (~OE), U9.41 (I/O)
/GLUE/~RD: U3.18 (~RD), U9.40 (I/O)
/GLUE/~RESET_SW: R2.2, U9.1 (INPUT/GLCRn)
/GLUE/~RESET: U3.23 (~RESET), U6.34 (~RESET), U9.60 (I/O), U11.8 (~RESET)
/GLUE/~RFSH: U3.25 (~RFSH), U9.36 (I/O)
/GLUE/~ROM_ENABLE: U5.20 (~CE), U5.22 (~OE), U9.56 (I/O)
/GLUE/~SND_ENABLE: U2.5 (~WE), U2.6 (~CE), U9.58 (I/O)
/GLUE/~WAIT: R13.1, U2.4 (RDY), U3.21 (~WAIT), U9.39 (I/O)
/GLUE/~WR: U3.19 (~WR), U4.27 (~WE), U9.84 (INPUT/OE1)
/controller/ex_ARM: J5.5, J7.5, U10.8
/controller/ex_FIRE: J5.8, J7.8, U10.11
/controller/ex_disable: R20.2, SW3.1 (A), U10.10, U10.13
/controller/in_ARM: J1.5, U10.3
/controller/in_FIRE: J1.7, U10.6
/controller/in_disable: R21.1, SW3.3 (C), U10.1, U10.4
/cpu/~BUSRQ: R8.2, U3.22 (~BUSREQ)
/cpu/~HALT: R7.1, U3.14 (~HALT)
/cpu/~NMI: U3.13 (~NMI), U6.16 (~INT)
/sound/HP+: C2.2, J9.2, J9.3, R24.2
/sound/HP_BTL: J9.4, R4.1, R27.1
/sound/SP+: C2.1, C6.1, J2.1, R25.2, U1.5 (VO+)
/sound/SP-: J2.2, U1.8 (VO-)
/storage/A10e: U4.21 (A10), U12.4
/storage/A11e: U4.23 (A11), U13.4
/storage/A12e: U4.2 (A12), U14.4
/storage/A13e: U4.26 (A13), U15.4
/storage/A14e: U4.1 (A14), U16.4
/storage/ram_mirror: U9.37 (I/O), U12.2, U13.2, U14.2, U15.2, U16.2
/video/AD0: U6.10 (AD0), U7.10 (A7), U8.10 (A7)
/video/AD1: U6.9 (AD1), U7.6 (A6), U8.6 (A6)
/video/AD2: U6.8 (AD2), U7.7 (A5), U8.7 (A5)
/video/AD3: U6.7 (AD3), U7.8 (A4), U8.8 (A4)
/video/AD4: U6.6 (AD4), U7.11 (A3), U8.11 (A3)
/video/AD5: U6.5 (AD5), U7.12 (A2), U8.12 (A2)
/video/AD6: U6.4 (AD6), U7.13 (A1), U8.13 (A1)
/video/AD7: U6.3 (AD7), U7.14 (A0), U8.14 (A0)
/video/R0: U6.32 (RD0), U7.2 (DQ1)
/video/R1: U6.31 (RD1), U7.3 (DQ2)
/video/R2: U6.30 (RD2), U7.15 (DQ3)
/video/R3: U6.29 (RD3), U7.17 (DQ4)
/video/R4: U6.28 (RD4), U8.17 (DQ4)
/video/R5: U6.27 (RD5), U8.15 (DQ3)
/video/R6: U6.26 (RD6), U8.3 (DQ2)
/video/R7: U6.25 (RD7), U8.2 (DQ1)
/video/RnW: U6.11 (R/~W), U7.4 (~W), U8.4 (~W)
/video/Y: R12.2, U6.36 (COMVID)
/video/nCAS: U6.2 (~CAS), U7.16 (~CAS), U8.16 (~CAS)
/video/nRAS: U6.1 (~RAS), U7.5 (~RAS), U8.5 (~RAS)
GNDD: C1.2, C3.2, C4.1, C5.2, C7.2, C8.2, C9.2, C10.2, C11.2, C12.2, C13.2, C14.2, C15.1, C16.2, C17.2, C18.2, C19.2, C20.2, C21.2, C22.2, C23.2, C24.2, C25.1, C27.2, C28.2, C29.2, C30.2, C31.2, C32.2, C33.2, C34.2, C35.2, C36.2, D1.1 (K), J3.2 (Ext), J4.29, J6.2, J6.10, J9.1, J10.2, J11.2, R10.1, R11.2, R17.2, R24.1, R26.1, RV1.1, SW1.2, SW3.2 (B), U1.1 (SHUTDOWN), U1.7 (GND), U2.8 (GND), U3.26 (GND), U4.14 (GND), U5.14 (GND), U6.12 (VSS), U7.1 (~G), U7.18 (VSS), U8.1 (~G), U8.18 (VSS), U9.7 (GND), U9.19 (GND), U9.32 (GND), U9.42 (GND), U9.47 (GND), U9.59 (GND), U9.72 (GND), U9.82 (GND), U10.7 (GND), U11.6 (GND), U12.3 (GND), U13.3 (GND), U14.3 (GND), U15.3 (GND), U16.3 (GND)
unnamed: C1.1, R1.2, R2.1, SW1.1
unnamed: C4.2, R5.1, R6.1, RV1.3
unnamed: C26.1, R23.1
unnamed: C26.2, R26.2, RV1.2
unnamed: D1.2 (A), R22.2
unnamed: J3.1 (In), Q1.1 (E), R10.2
unnamed: J5.9, R19.1
unnamed: J7.9, R18.1
unnamed: J10.1, SW2.2 (B)
unnamed: L1.1, R29.1
unnamed: Q1.2 (B), R11.1, R12.1
unnamed: C28.1, U1.2 (BYPASS)
unnamed: C6.2, R23.2, R25.1, U1.4 (IN)
unnamed: C27.1, R4.2, U1.3 (SE/~BTL)
unnamed: R5.2, U2.7 (OUT)
unnamed: C15.2, U6.40 (XTAL1), Y1.1
unnamed: C16.1, U6.39 (XTAL2), Y1.2
unnamed: R6.2, U11.5 (OUT)

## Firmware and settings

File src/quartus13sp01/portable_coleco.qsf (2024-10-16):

# -------------------------------------------------------------------------- #
#
# Copyright (C) 1991-2013 Altera Corporation
# Your use of Altera Corporation's design tools, logic functions
# and other software and tools, and its AMPP partner logic
# functions, and any output files from any of the foregoing
# (including device programming or simulation files), and any
# associated documentation or information are expressly subject
# to the terms and conditions of the Altera Program License
# Subscription Agreement, Altera MegaCore Function License
# Agreement, or other applicable license agreement, including,
# without limitation, that your use is for the sole purpose of
# programming logic devices manufactured by Altera and sold by
# Altera or its authorized distributors.  Please refer to the
# applicable agreement for further details.
#
# -------------------------------------------------------------------------- #
#
# Quartus II 64-Bit
# Version 13.0.1 Build 232 06/12/2013 Service Pack 1 SJ Web Edition
# Date created = 17:47:30  December 31, 2023
#
# -------------------------------------------------------------------------- #
#
# Notes:
#
# 1) The default values for assignments are stored in the file:
#		portable_coleco_assignment_defaults.qdf
#    If this file doesn't exist, see file:
#		assignment_defaults.qdf
#
# 2) Altera recommends that you do not modify this file. This
#    file is updated automatically by the Quartus II software
#    and any changes you make may be lost or overwritten.
#
# -------------------------------------------------------------------------- #


set_global_assignment -name FAMILY MAX7000S
set_global_assignment -name DEVICE "EPM7128SLC84-10"
set_global_assignment -name TOP_LEVEL_ENTITY porta_glue_coleco
set_global_assignment -name ORIGINAL_QUARTUS_VERSION "13.0 SP1"
set_global_assignment -name PROJECT_CREATION_TIME_DATE "17:47:30  DECEMBER 31, 2023"
set_global_assignment -name LAST_QUARTUS_VERSION "13.0 SP1"
set_global_assignment -name PROJECT_OUTPUT_DIRECTORY output_files
set_global_assignment -name ERROR_CHECK_FREQUENCY_DIVISOR "-1"
set_global_assignment -name EDA_SIMULATION_TOOL "ModelSim-Altera (Verilog)"
set_global_assignment -name EDA_OUTPUT_DATA_FORMAT "VERILOG HDL" -section_id eda_simulation
set_global_assignment -name OPTIMIZE_HOLD_TIMING OFF
set_global_assignment -name OPTIMIZE_MULTI_CORNER_TIMING OFF
set_global_assignment -name FITTER_EFFORT "STANDARD FIT"
set_global_assignment -name MAX7000_DEVICE_IO_STANDARD TTL
set_global_assignment -name SDC_FILE ../portable_coleco/constr/porta_glue_coleco.sdc
set_global_assignment -name VERILOG_FILE ../portable_coleco/src/porta_glue_coleco.v
set_location_assignment PIN_15 -to A[15]
set_location_assignment PIN_16 -to A[14]
set_location_assignment PIN_17 -to A[13]
set_location_assignment PIN_18 -to A[12]
set_location_assignment PIN_20 -to A[11]
set_location_assignment PIN_21 -to A[10]
set_location_assignment PIN_22 -to A[9]
set_location_assignment PIN_24 -to A[8]
set_location_assignment PIN_25 -to A[7]
set_location_assignment PIN_27 -to A[6]
set_location_assignment PIN_28 -to A[5]
set_location_assignment PIN_29 -to A[4]
set_location_assignment PIN_30 -to A[3]
set_location_assignment PIN_31 -to A[2]
set_location_assignment PIN_33 -to A[1]
set_location_assignment PIN_34 -to A[0]
set_location_assignment PIN_2  -to C1P1
set_location_assignment PIN_4  -to C1P2
set_location_assignment PIN_5  -to C1P3
set_location_assignment PIN_6  -to C1P4
set_location_assignment PIN_8  -to C1P6
set_location_assignment PIN_9  -to C1P7
set_location_assignment PIN_80 -to C1P9
set_location_assignment PIN_70 -to C2P1
set_location_assignment PIN_73 -to C2P2
set_location_assignment PIN_74 -to C2P3
set_location_assignment PIN_75 -to C2P4
set_location_assignment PIN_76 -to C2P6
set_location_assignment PIN_77 -to C2P7
set_location_assignment PIN_81 -to C2P9
set_location_assignment PIN_68 -to CSRn
set_location_assignment PIN_69 -to CSWn
set_location_assignment PIN_65 -to CS_h8000n
set_location_assignment PIN_64 -to CS_hA000n
set_location_assignment PIN_63 -to CS_hC000n
set_location_assignment PIN_67 -to CS_hE000n
set_location_assignment PIN_49 -to D[7]
set_location_assignment PIN_51 -to D[6]
set_location_assignment PIN_52 -to D[5]
set_location_assignment PIN_54 -to D[4]
set_location_assignment PIN_55 -to D[3]
set_location_assignment PIN_50 -to D[2]
set_location_assignment PIN_48 -to D[1]
set_location_assignment PIN_46 -to D[0]
set_location_assignment PIN_44 -to IORQn
set_location_assignment PIN_35 -to M1n
set_location_assignment PIN_45 -to MREQn
set_location_assignment PIN_57 -to RAM_CSn
set_location_assignment PIN_37 -to RAM_MIRROR
set_location_assignment PIN_1  -to RESETn_SW
set_location_assignment PIN_36 -to RFSHn
set_location_assignment PIN_56 -to ROM_ENABLEn
set_location_assignment PIN_58 -to SND_ENABLEn
set_location_assignment PIN_61 -to INTn
set_location_assignment PIN_39 -to WAITn
set_location_assignment PIN_84 -to WRn
set_location_assignment PIN_83 -to clk
set_location_assignment PIN_60 -to RESETn
set_location_assignment PIN_41 -to RAM_OEn
set_location_assignment PIN_40 -to RDn
set_location_assignment PIN_11 -to CP5_ARM
set_location_assignment PIN_12 -to CP8_FIRE
set_location_assignment PIN_79 -to AY_SND_ENABLEn
set_location_assignment PIN_10 -to AS

set_global_assignment -name SLOW_SLEW_RATE ON

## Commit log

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2022-12-28 first day of pcb trace, working pin by of the z80 cpu. Last pin completed: 7
    [coleco_original.kicad_sch, sound.kicad_sch]
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2022-12-30 changed all vintage library names to better represent future ideas. Removed parts not needed... for now. Updated schmematic symbols.
    [sound.kicad_sch, storage.kicad_sch, video.kicad_sch]
2022-12-31 Up to pin 29 on z80 done. Address 0 to 10 left. Only tracing to its end point for the most part. Each chip gets traced chip to chip in this manned
    [clock_reset.kicad_sch, coleco_original.kicad_sch, cpu.kicad_sch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]
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2023-01-02 added rf modulation schematic, added dram to vdp. Fixed +5vc to +5v
    [clock_reset.kicad_sch, coleco_original.kicad_sch, cpu.kicad_sch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]
2023-01-02 added u5 decoder lines, need to rename for chip selects that they actually are in future.
    [clock_reset.kicad_sch, coleco_original.kicad_sch, decoder_logic.kicad_sch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]
2023-01-02 added u6 decoder lines, renamed a few lines to make sense to there destination.
    [coleco_original.kicad_sch, controller.kicad_sch, decoder_logic.kicad_sch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]
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2023-01-03 fixed some more line names, added a expansion port io pin.
    [clock_reset.kicad_sch, coleco_original.kicad_sch, cpu.kicad_sch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]
2023-01-03 power supply added, controller circuit added. Controller is a very odd duck to say the least. Seems they wanted to have plenty of current, maybe due to the steering wheel attachement?
    [clock_reset.kicad_sch, coleco_original.kicad_sch, controller.kicad_sch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]
2023-01-03 started work on clock_reset_misc circuits. inverter u7 done, u8 added and starting work around U22.
    [clock_reset.kicad_sch, coleco_original.kicad_sch, controller.kicad_sch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]
2023-01-04 first version of clock-reset circuits. Its a bit complicated and will need some revisions.
    [clock_reset.kicad_sch, coleco_original.kicad_sch, psu.kicad_sch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]
2023-01-04 altered and did some cleanup of the way the wires were run. Finished expansion port routes to rf modulator. Added ext_psu for future external power supply design (will be an off the shelf psu block).
    [clock_reset.kicad_sch, coleco_original.kicad_sch, controller.kicad_sch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]
2023-01-04 added rf mod section, this is very rough. Has mistakes for sure.
    [coleco_original.kicad_sch, rf_mod.kicad_sch]
2023-01-04 RF modulator completed, rough draft complete. Next step is to clean-up all pages.
    [clock_reset.kicad_sch, coleco_original.kicad_sch, ext_psu.kicad_sch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]
2023-01-08 Cleanup clock-reset-invert schematic. Checked against wiki.console5.com/wiki/Colecovision. Had a inverter backwards (after cleanup it was obvious since its a standard circuit). Everything else checks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
    [clock_reset.kicad_sch, coleco_original.kicad_sch, cpu.kicad_sch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]
2023-01-08 cleanup on the controller schematic. Checked against wiki.console5.com/wiki/Colecovision. Found a mistake with INT line thanks to the wiki. R21/R22 is reversed between the schematics. Aka R21 is plac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
    [clock_reset.kicad_sch, controller.kicad_sch, sound.kicad_sch]
2023-01-08 cleaup of rf circuits. much better flow vs the original. Comparing to the wiki.console5.com/wiki/Colecovision shows many differences. Not sure I agree with it at all. Going to use the ADAM schematic 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
    [coleco_original.kicad_sch, rf_mod.kicad_sch, sub_rf_mod.kicad_sch]
2023-01-09 cleanup of power supply, and another pass at the RF circuit. Both look much better. The RF circuit just looks wrong though. Will need to check it over.
    [coleco_original.kicad_sch, io_ports.kicad_sch, psu.kicad_sch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]
2023-01-09 cleaned up RF circuit again, and used ChildOfCv schematic as a ref. Fixed a few mistakes. I didn't know his even existed. Its a very nice project. I didn't know it existed till I was googling some so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
    [clock_reset.kicad_sch, coleco_original.kicad_sch, rf_mod.kicad_sch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]
2023-01-09 added my refs so people will know where the 2nd phase of checks came from. its really helped the effort, the goal is to reverse the board from the original, and use online sources to check, and then 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
2023-01-10 all lines renamed, based most of the names from the coleco adam schematic. CS cart lines are my own, and the rest are from the wiki schematic for the controller... those will need to be checked.
    [clock_reset.kicad_sch, coleco_original.kicad_sch, controller.kicad_sch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]
2023-01-10 adjusted size of the sheets. added pcb version to the rev field. F.0... the 0 is for future fixes on my end. RF PCB is E.0.
    [clock_reset.kicad_sch, coleco_original.kicad_sch, controller.kicad_sch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]
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2023-01-16 added new libs for rest of the parts. some still need updating for correct parts, but for now they work. PCB import complete.
    [c-5530841-2-b-3d.ipt, c-5530841-2-b-3d.stp, clock_reset.kicad_sch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]
2023-01-16 created edge cut outline for coleco pcb. updated expansion connector edge cut to be the correct size (using a 0.8 mm cutting end in my mill).
    [coleco_original.kicad_pcb, coleco_original.kicad_sch, sub_rf_mod.kicad_sch]
2023-01-16 place a few components for an alignment check. changed edge cut back to 0.1. added new edge.cuts.mill layer for pcb mill edge cuts
    [coleco_original.kicad_pcb, sub_rf_mod.kicad_sch]
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2023-02-07 added a quick version of the RF board. Not checked at all.
    [coleco_original.kicad_pcb]
2023-02-12 fixed RF board placement, not perfect, but needs to align to new component sizes
    [coleco_original.kicad_pcb, sub_rf_mod.kicad_pcb, sub_rf_mod.kicad_sch]
2023-02-13 RF on main board components setup correctly.
    [coleco_original.kicad_pcb, coleco_original.kicad_sch, psu.kicad_sch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]
2023-02-14 did a small amount of pcb work, also finished component directions for the main board. RF pcb is still a mess and needs a second pass.
    [coleco_original.kicad_pcb, sub_rf_mod.kicad_sch]
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2023-02-22 added traces to parts of the clock gen/reset ic's
    [coleco_original.kicad_pcb, coleco_original.kicad_sch, psu.kicad_sch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]
2023-02-28 fixed a bug on the +5v line, added +5NF (no filter) net list names. Added traces to the ram, and inverter, and select ics.
    [coleco_original.kicad_pcb, coleco_original.kicad_sch, decoder_logic.kicad_sch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]
2023-03-02 added memory, eprom and sound lines. some video as well. fixed the cap size for polar. its a bit weird since they use 5 mm pin and 5mm body and bend out the leads.
    [clock_reset.kicad_sch, coleco_original.kicad_pcb, coleco_original.kicad_sch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]
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2023-03-13 added a new jack with matching pin names. started fixing drc errors. start working on power trace sizes.
    [coleco_original.kicad_sch, sub_rf_mod.kicad_sch]
2023-03-14 added new models, fixed the drc errors. changed power width.
    [clock_reset.kicad_sch, coleco_original.kicad_sch, controller.kicad_sch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]
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2023-03-14 added power cable pinout, cleanup finished on main page of schematic, now fits US letter page.
    [coleco_original.kicad_sch, ext_psu.kicad_sch, video.kicad_sch]
2023-03-17 added pads for switch and RF shield, RF shield still needs adjustment
    [coleco_original.kicad_sch, controller.kicad_sch, psu.kicad_sch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]
2023-03-17 fixed mount spacing, added labels, and added new version of reset switch.
    [coleco_original.kicad_sch, sub_rf_mod.kicad_sch]
2023-03-17 imporved power rails, added 3D models (primitives at this point till others can be made).
    [Coilcraft SLOT10 tunable.FCStd, Coilcraft SLOT10 tunable.stp, c-5530841-2-b-3d.ipt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]
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2023-03-20 some cleanup on the rf main circuit. tested out and reverted 10 mil to 12 mil spacing. Fails on cart connector.
    [coleco_original.kicad_sch, rf_mod.kicad_sch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]
2023-03-23 fixed cart for 12 mil isolation routing. Now minimum trace isolation is 12 mil. Trace width min is 12 mil. This is easier to build.
    [coleco_original.kicad_sch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]
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2023-03-25 adjusted connector and switch to remove ignored clearance errors
    [coleco_original.kicad_sch, sub_rf_mod.kicad_sch]
2023-03-25 adjust gnd iso width to better connect all grounds in video ram (20 down to 12mil)
    [sub_rf_mod.kicad_sch]
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2023-03-30 enlarged mount holes to match coleco, adjusted placement of two. adjusted traces for new holes.
    [coleco_original.kicad_sch]
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2023-04-03 fixed two resistors that were the wrong value wrong, 270. correct 120.
    [coleco_original.kicad_sch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]
2023-04-03 changed the board from the original so the control ports can be soldered from the bottom. standard dsub 9 bin connectors don't work on non-plated hole designs. All other parts can be soldered top and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
2023-04-03 added mounting holes, future proof the video section for jumper selection of voltages between 4516/4116 chips
    [coleco_original.kicad_sch, rf_mod.kicad_sch, sub_rf_mod.kicad_pcb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]
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2023-04-07 changed crystal a bit more to make double sided non-plated through hole designs easier. This time top traces rerouted to avoid shorts from the crystal body.
2023-04-08 updated schematic PDF, updated 3D image. Updated all gerber files, and small adjustments to the pcb to cleanup traces.
    [clock_reset.kicad_sch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]
2023-04-09 fixed cap value, adjusted rf lines on main board to make npt hole assembly easier
    [coleco_original.kicad_sch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]
2023-04-09 fixed value of resistors on RF board, fixed placement of resistors on RF board
    [coleco_original.kicad_sch, sub_rf_mod.kicad_sch]
2023-04-10 adjusting RF layout, seems to have issues with the previous layout with noise
    [sub_rf_mod-B_Cu.gbr, sub_rf_mod-B_Silkscreen.gbr, sub_rf_mod-Edge_Cuts.gbr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]
2023-04-11 fixed footprint lead size
    [sub_rf_mod-B_Cu.gbr, sub_rf_mod-B_Silkscreen.gbr, sub_rf_mod-Edge_Cuts.gbr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]
2023-04-12 pdf added, and changes to data bus to resolve shorting issues between cart and rom
    [coleco_original_main_only-B_Cu.gbr, coleco_original_main_only-B_Silkscreen.gbr, coleco_original_main_only-Edge_Cuts.gbr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]
2023-04-13 changed switch to one that is a better match for the old (larger)
    [coleco_original.kicad_sch, sub_rf_mod.kicad_pcb, sub_rf_mod.kicad_sch]
2023-04-14 update routing of rf board to fix loop over pin
    [sub_rf_mod-B_Cu.gbr, sub_rf_mod-B_Silkscreen.gbr, sub_rf_mod-Edge_Cuts.gbr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]
2023-05-01 changed a few traces, and updated a few parts. cleanup to make building easier so resistors don't have vias under them for npth builds
    [clock_reset.kicad_sch, coleco_original.kicad_sch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]
2023-05-01 changed clock line so it wouldn't keep the resistor out of place on npth builds
    [coleco_original.kicad_sch]
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2023-05-10 updated switch to fix isolation size. fixed some traces to prevent shorts when being build at home with mills or etching methods.
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2023-05-21 fixed pad size for switch
    [coleco_original_main_only.step, main_exports_missing.FCStd]
2023-05-22 fixed 5v via so it doesn't hold up the resistor
    [coleco_original_main_only-B_Cu.gbr, coleco_original_main_only-B_Silkscreen.gbr, coleco_original_main_only-Edge_Cuts.gbr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]
2023-05-23 fixed some t-tech edge cut for the main board.
    [coleco_original_main_only-B_Cu.gbr, coleco_original_main_only-B_Silkscreen.gbr, coleco_original_main_only-Edge_Cuts.gbr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]
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2023-05-23 fixed the switch for the sub-rf board to match the original coleco for chan 3/4 selection
    [sub_rf_mod-B_Cu.gbr, sub_rf_mod-B_Silkscreen.gbr, sub_rf_mod-Edge_Cuts.gbr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]
2023-05-25 first commit of verison 1.0.0, missing documents for signals and 3D enclosure.
    [clock_reset.kicad_sch, coleco_original.kicad_sch, controller.kicad_sch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]
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2023-05-28 added new kicad 3d model of pcb... coleco_original3.iam is the best. odd bug that the switch comes out clear
    [5530841-2.iam, Assembly1.0004.iam, Assembly1.0006.iam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]
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2023-06-19 3D printed part adjust, fix cart position.
    [Assembly1.0006.iam, Assembly1.0009.iam, Assembly1.iam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]
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2024-01-04 first commit of portable coleco, major changes... pcb meh. CPLD code tested, quartus build works.
    [coleco_original.kicad_sch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]
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2024-01-07 First version sent out for build. 6116 as a DIP makes the design easier.
    [coleco_original-B_Adhesive.gbr, coleco_original-B_Cu.gbr, coleco_original-B_Mask.gbr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]
2024-01-07 changed traces to 8 mil, 8 mil iso. allows for better routing of lines that didn't need to be as thick as they were.
    [coleco_original.kicad_pcb]
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2024-01-08 moved JTAG connector over to make room for power on side of board
    [coleco_original.kicad_pcb, coleco_original.kicad_sch, glue.kicad_sch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]
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2024-02-03 improve nand circuit for controller enable, since clocked version works fine, just use and xor to indicated its time to flip flop enables
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2024-03-24 added board images, old version, missing holes and C*P9 resistors and caps.
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2024-03-25 fix ref for schematic, add bin folder
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2024-04-20 updated output jacks to correct footprint
    [coleco_original.kicad_pcb, psu.kicad_sch, sound.kicad_sch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]
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2024-10-05 update for release, correct documents, and update readme
    [coleco_original-B_Courtyard.gbr, coleco_original-B_Cu.gbr, coleco_original-B_Fab.gbr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]
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2024-11-08 correct error in fusesoc section
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2024-11-09 add 2 ohm resistors to pi filters for analog noise filtering
    [coleco_original-B_Adhesive.gbr, coleco_original-B_Courtyard.gbr, coleco_original-B_Cu.gbr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]
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2025-02-10 update with last few changes and fixes
    [coleco_original-B_Adhesive.gbr, coleco_original-B_Courtyard.gbr, coleco_original-B_Cu.gbr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]
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
